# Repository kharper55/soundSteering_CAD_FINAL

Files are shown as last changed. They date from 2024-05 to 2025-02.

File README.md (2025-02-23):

All CAD pdfs and RAW files from KiCAD6 and some nice pin mapping references + block diagrams. Custom symbol and footprint library (not provided) needed to rebuild Gerbers (provided as-is). 

Contains schematic, PCB, BOM (entire KiCAD project + PDF prints) and Gerber files for 3x 4 layer mixed signal PCBs. KiCAD project has since seen edits in silkscreen and rectifying some issues with DNP parts.

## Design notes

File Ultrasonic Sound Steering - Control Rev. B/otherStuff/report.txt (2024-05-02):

Info: 
Info: Only selected footprints will be reannotated.
Info: Front footprints will start at 1
Info: Back footprints will start at 1.
Info: Prior to sorting by footprint location, the coordinates of which will be rounded to a 0.0100 mm, 0.0100 mm grid.
Info: 
Info: 
Info: Front Footprints
Info: *********** Sort on Footprint Coordinates ***********
Info: Sort Code 1
Info: 1 H4 UUID: [5ef39d40-b55b-4409-b36c-55ace9773fcc], X, Y: 270.2001 mm, 31.4900 mm, Rounded X, Y, 270.2000 mm, 31.4900 mm
Info: 2 H3 UUID: [7f6b7f0f-1088-4a6f-96c7-380cabd2f233], X, Y: 162.2002 mm, 31.4900 mm, Rounded X, Y, 162.2000 mm, 31.4900 mm
Info: 3 P1 UUID: [6f78a790-197d-4599-be1c-a15c64767265], X, Y: 260.8551 mm, 34.3800 mm, Rounded X, Y, 260.8600 mm, 34.3800 mm
Info: 4 P2 UUID: [7a461615-ffd7-4d30-9663-87001a941793], X, Y: 237.0701 mm, 34.3800 mm, Rounded X, Y, 237.0700 mm, 34.3800 mm
Info: 5 P3 UUID: [b7c12510-6d3f-4c6a-94f6-3d0dc28c4cde], X, Y: 213.2476 mm, 34.3800 mm, Rounded X, Y, 213.2500 mm, 34.3800 mm
Info: 6 P4 UUID: [4b9d0df7-170f-4f7f-a033-8b28d6827d94], X, Y: 189.3551 mm, 34.3800 mm, Rounded X, Y, 189.3600 mm, 34.3800 mm
Info: 7 R74 UUID: [192819fe-81a5-48ce-b989-7daec683b7d6], X, Y: 285.6400 mm, 38.6100 mm, Rounded X, Y, 285.6400 mm, 38.6100 mm
Info: 8 R75 UUID: [aceaaa9f-2b43-44a9-b572-54237d9b5ddd], X, Y: 284.1000 mm, 38.6100 mm, Rounded X, Y, 284.1000 mm, 38.6100 mm
Info: 9 C96 UUID: [d31a0397-f6ec-4a75-b0f9-c2d860a3d8c2], X, Y: 243.1000 mm, 41.3000 mm, Rounded X, Y, 243.1000 mm, 41.3000 mm
Info: 10 C94 UUID: [c2bd5aec-4e19-4a4d-851d-8b688b552ec4], X, Y: 241.6000 mm, 41.3000 mm, Rounded X, Y, 241.6000 mm, 41.3000 mm
Info: 11 C95 UUID: [f7d8199e-b9d8-48f1-bcea-ccafea0f0110], X, Y: 224.1000 mm, 41.5000 mm, Rounded X, Y, 224.1000 mm, 41.5000 mm
Info: 12 C93 UUID: [2ff3868e-4557-4a7c-8d10-9de1767db7a0], X, Y: 222.6000 mm, 41.5000 mm, Rounded X, Y, 222.6000 mm, 41.5000 mm
Info: 13 C104 UUID: [77131fb7-b846-4782-86b5-000abba21fb8], X, Y: 213.1000 mm, 41.5000 mm, Rounded X, Y, 213.1000 mm, 41.5000 mm
Info: 14 C102 UUID: [9f405f32-2f64-4263-b93f-015da219d625], X, Y: 211.6000 mm, 41.5000 mm, Rounded X, Y, 211.6000 mm, 41.5000 mm
Info: 15 C106 UUID: [21935355-0ea7-4418-bf57-3f39151b43f0], X, Y: 194.6000 mm, 41.5000 mm, Rounded X, Y, 194.6000 mm, 41.5000 mm
Info: 16 C108 UUID: [5b7d43c3-fe25-4339-ba2b-cab150709af7], X, Y: 193.0000 mm, 41.5000 mm, Rounded X, Y, 193.0000 mm, 41.5000 mm
Info: 17 D7 UUID: [b641bdf0-49eb-4e1c-94cb-5314bfd786c3], X, Y: 171.2000 mm, 43.1000 mm, Rounded X, Y, 171.2000 mm, 43.1000 mm
Info: 18 D6 UUID: [15c5f8f7-2afb-450d-b21e-f225e625be45], X, Y: 167.8000 mm, 43.1000 mm, Rounded X, Y, 167.8000 mm, 43.1000 mm
Info: 19 D8 UUID: [ad3ab07d-9057-4924-bd8b-8088b57ed8a1], X, Y: 164.4000 mm, 43.1000 mm, Rounded X, Y, 164.4000 mm, 43.1000 mm
Info: 20 R2 UUID: [6c8bd184-798c-4f7b-a843-9cd77462ab86], X, Y: 285.1250 mm, 43.3700 mm, Rounded X, Y, 285.1200 mm, 43.3700 mm
Info: 21 R1 UUID: [0578c37e-47f8-452a-a67a-b190503e62a1], X, Y: 285.1300 mm, 44.9400 mm, Rounded X, Y, 285.1300 mm, 44.9400 mm
Info: 22 C6 UUID: [90d4da69-4018-498f-bb6b-4cfebdb4cb5a], X, Y: 256.9948 mm, 45.9200 mm, Rounded X, Y, 256.9900 mm, 45.9200 mm
Info: 23 R5 UUID: [0b83f195-4963-4ca1-a54c-d24446b93c1d], X, Y: 255.4698 mm, 45.9200 mm, Rounded X, Y, 255.4700 mm, 45.9200 mm
Info: 24 R6 UUID: [a8cb8963-6a5a-49e4-a7a4-19c73d057da1], X, Y: 248.5198 mm, 45.9767 mm, Rounded X, Y, 248.5200 mm, 45.9800 mm
Info: 25 C4 UUID: [b4efda08-249d-4e6f-88e2-4c848a29d86f], X, Y: 246.9948 mm, 46.0017 mm, Rounded X, Y, 246.9900 mm, 46.0000 mm
Info: 26 U2 UUID: [b464a15f-49cd-483f-929b-b1d63c0dfe61], X, Y: 252.9200 mm, 47.6602 mm, Rounded X, Y, 252.9200 mm, 47.6600 mm
Info: 27 G*** UUID: [f62f571e-809b-4679-b4e9-53366150a207], X, Y: 171.0000 mm, 48.1000 mm, Rounded X, Y, 171.0000 mm, 48.1000 mm
Info: 28 G*** UUID: [f1c5bfbf-437b-4444-ade4-cd4697dfba52], X, Y: 164.1000 mm, 48.1000 mm, Rounded X, Y, 164.1000 mm, 48.1000 mm
Info: 29 R8 UUID: [c76515d9-e052-481d-a8d4-7fa5a038c2eb], X, Y: 256.9948 mm, 49.0200 mm, Rounded X, Y, 256.9900 mm, 49.0200 mm
Info: 30 R7 UUID: [2f5d750f-5572-471e-ad27-fa2c6e839281], X, Y: 246.9948 mm, 49.1017 mm, Rounded X, Y, 246.9900 mm, 49.1000 mm
Info: 31 R12 UUID: [ef9dd0d9-21e3-49e7-af84-aa2227a2675a], X, Y: 253.7200 mm, 51.2950 mm, Rounded X, Y, 253.7200 mm, 51.2900 mm
Info: 32 R15 UUID: [7903577e-90f3-4db0-83ab-298ddfa54431], X, Y: 252.1200 mm, 51.3200 mm, Rounded X, Y, 252.1200 mm, 51.3200 mm
Info: 33 R20 UUID: [e50c0e15-2a00-42e9-969f-a33d5defc610], X, Y: 255.9700 mm, 52.0450 mm, Rounded X, Y, 255.9700 mm, 52.0400 mm
Info: 34 R21 UUID: [9a23b505-a1c1-4c55-8e94-07d0a04f6fc8], X, Y: 249.8700 mm, 52.0700 mm, Rounded X, Y, 249.8700 mm, 52.0700 mm
Info: 35 C30 UUID: [ee7c2646-8918-4316-a13c-a55547939d0d], X, Y: 256.7200 mm, 54.3200 mm, Rounded X, Y, 256.7200 mm, 54.3200 mm
Info: 36 R23 UUID: [0a22617f-48e2-405b-8c59-09456fa25df2], X, Y: 255.2200 mm, 54.3200 mm, Rounded X, Y, 255.2200 mm, 54.3200 mm
Info: 37 C25 UUID: [2add6fbd-b38e-45b6-a212-125797d8d517], X, Y: 253.7200 mm, 54.3200 mm, Rounded X, Y, 253.7200 mm, 54.3200 mm
Info: 38 C26 UUID: [f990f52e-1060-43c0-97b5-9bdc75fcd620], X, Y: 252.1200 mm, 54.3450 mm, Rounded X, Y, 252.1200 mm, 54.3400 mm
Info: 39 R22 UUID: [0b8f20a1-43ed-46d2-8b26-702ba0309f43], X, Y: 250.6200 mm, 54.3450 mm, Rounded X, Y, 250.6200 mm, 54.3400 mm
Info: 40 C31 UUID: [b8513cf6-7d74-49e5-a1db-c65cbb1ba585], X, Y: 249.1200 mm, 54.3450 mm, Rounded X, Y, 249.1200 mm, 54.3400 mm
Info: 41 R31 UUID: [a8602b57-4e29-4aee-9e20-8a3468aa8102], X, Y: 248.9902 mm, 57.5333 mm, Rounded X, Y, 248.9900 mm, 57.5300 mm
Info: 42 C43 UUID: [42c4c59c-cc5c-4fd7-a70a-157ab00b49dd], X, Y: 247.4902 mm, 57.5383 mm, Rounded X, Y, 247.4900 mm, 57.5400 mm
Info: 43 U4 UUID: [9b29cd54-7d87-4a06-95ed-141c28052086], X, Y: 252.9200 mm, 59.1200 mm, Rounded X, Y, 252.9200 mm, 59.1200 mm
Info: 44 R30 UUID: [542dc883-e43e-472f-abc6-3a26a651cfff], X, Y: 248.9902 mm, 60.7133 mm, Rounded X, Y, 248.9900 mm, 60.7100 mm
Info: 45 C42 UUID: [e14837a6-e638-4080-99ac-983030d82948], X, Y: 247.4802 mm, 60.7183 mm, Rounded X, Y, 247.4800 mm, 60.7200 mm
Info: 46 C13 UUID: [5c6f666c-9dd8-4829-8e80-5befac30e1d8], X, Y: 266.1745 mm, 63.2595 mm, Rounded X, Y, 266.1700 mm, 63.2600 mm
Info: 47 C2 UUID: [32d9b593-6e00-4ffd-a08a-8f7fab912e91], X, Y: 264.6745 mm, 63.2595 mm, Rounded X, Y, 264.6700 mm, 63.2600 mm
Info: 48 R4 UUID: [335eb178-9181-4ef2-a296-3c4829b20506], X, Y: 263.1745 mm, 63.2595 mm, Rounded X, Y, 263.1700 mm, 63.2600 mm
Info: 49 C52 UUID: [90c07117-21cb-4709-aafc-49395e5940fc], X, Y: 250.6200 mm, 63.8950 mm, Rounded X, Y, 250.6200 mm, 63.8900 mm
Info: 50 C53 UUID: [f0b0f0b8-d6ab-47f5-b3d7-a419942acf09], X, Y: 255.1200 mm, 63.9200 mm, Rounded X, Y, 255.1200 mm, 63.9200 mm
Info: 51 R35 UUID: [96bb19ba-ff89-4c77-a440-9e0a11db0f5c], X, Y: 253.6200 mm, 63.9200 mm, Rounded X, Y, 253.6200 mm, 63.9200 mm
Info: 52 R34 UUID: [92833a25-9b29-40f2-9ff9-85f116f08a3f], X, Y: 252.1200 mm, 63.9200 mm, Rounded X, Y, 252.1200 mm, 63.9200 mm
Info: 53 R3 UUID: [eb0800e6-e528-4757-9302-dcfdf8abad5f], X, Y: 261.0995 mm, 65.1095 mm, Rounded X, Y, 261.1000 mm, 65.1100 mm
Info: 54 C49 UUID: [4f0d0ace-e127-46ac-950d-6772649d938a], X, Y: 252.8700 mm, 66.1400 mm, Rounded X, Y, 252.8700 mm, 66.1400 mm
Info: 55 C1 UUID: [0938bcb7-e6c9-4788-b5e6-9acbacb9b62b], X, Y: 261.0995 mm, 66.6095 mm, Rounded X, Y, 261.1000 mm, 66.6100 mm
Info: 56 U1 UUID: [93391fc0-2245-4688-ae4c-8d46a3492553], X, Y: 265.2445 mm, 67.3595 mm, Rounded X, Y, 265.2400 mm, 67.3600 mm
Info: 57 R28 UUID: [82640fbd-3c73-4450-a22e-da4ba30d7b63], X, Y: 258.1450 mm, 67.8500 mm, Rounded X, Y, 258.1400 mm, 67.8500 mm
Info: 58 R29 UUID: [e7bf863f-b7ab-4ead-b51e-bc27fb58766e], X, Y: 255.1700 mm, 67.8500 mm, Rounded X, Y, 255.1700 mm, 67.8500 mm
Info: 59 R65 UUID: [75d41bf9-6a28-4542-b1f4-cd0ecc474c5b], X, Y: 174.7400 mm, 69.1100 mm, Rounded X, Y, 174.7400 mm, 69.1100 mm
Info: 60 R66 UUID: [11961651-8c18-44a2-9be0-223b05e9f2bd], X, Y: 171.6600 mm, 69.1100 mm, Rounded X, Y, 171.6600 mm, 69.1100 mm
Info: 61 R67 UUID: [c720f2e8-cac0-49f0-894e-f5031baecdde], X, Y: 168.6100 mm, 69.1100 mm, Rounded X, Y, 168.6100 mm, 69.1100 mm
Info: 62 C40 UUID: [958d8925-0e3f-4da3-a6b1-bfae443f6cfd], X, Y: 258.1450 mm, 69.3500 mm, Rounded X, Y, 258.1400 mm, 69.3500 mm
Info: 63 C41 UUID: [71bd50be-7db5-4780-bbec-b6e8ed043e99], X, Y: 255.1700 mm, 69.3500 mm, Rounded X, Y, 255.1700 mm, 69.3500 mm
Info: 64 R64 UUID: [2fd27f65-5d80-4188-b2bf-acc531168e70], X, Y: 174.7400 mm, 70.6600 mm, Rounded X, Y, 174.7400 mm, 70.6600 mm
Info: 65 C51 UUID: [8e789659-96b5-4a8d-93cb-7298e7069d96], X, Y: 251.8772 mm, 71.0578 mm, Rounded X, Y, 251.8800 mm, 71.0600 mm
Info: 66 C18 UUID: [9996c1e2-bf8a-4331-acff-6dbfe163533c], X, Y: 266.6445 mm, 71.8678 mm, Rounded X, Y, 266.6400 mm, 71.8700 mm
Info: 67 C17 UUID: [0a662090-924a-41f9-9c84-ecfee2765f3e], X, Y: 265.0445 mm, 71.8678 mm, Rounded X, Y, 265.0400 mm, 71.8700 mm
Info: 68 C28 UUID: [28542c89-831f-46a2-9572-15f587ab3dd8], X, Y: 260.5450 mm, 71.8900 mm, Rounded X, Y, 260.5400 mm, 71.8900 mm
Info: 69 Q3 UUID: [d3c47d26-7908-49cc-ab0e-07a830d9cec5], X, Y: 178.5000 mm, 72.0500 mm, Rounded X, Y, 178.5000 mm, 72.0500 mm
Info: 70 R33 UUID: [9946b09b-2d8e-41c4-9b8b-ed51b1f0b4bf], X, Y: 251.8772 mm, 72.5578 mm, Rounded X, Y, 251.8800 mm, 72.5600 mm
Info: 71 R70 UUID: [7aacb1dd-9b5b-400c-b776-7248739c89ff], X, Y: 175.5100 mm, 72.9800 mm, Rounded X, Y, 175.5100 mm, 72.9800 mm
Info: 72 R71 UUID: [8ef63d0b-c40a-4028-9155-7be2f9ffa36c], X, Y: 183.0100 mm, 72.9900 mm, Rounded X, Y, 183.0100 mm, 72.9900 mm
Info: 73 C129 UUID: [42e22537-8a59-4884-bd3a-296ff192f30d], X, Y: 181.4800 mm, 73.0000 mm, Rounded X, Y, 181.4800 mm, 73.0000 mm
Info: 74 R37 UUID: [cb7e0a10-8b63-4d06-a672-9a51c28baffb], X, Y: 240.6750 mm, 73.2543 mm, Rounded X, Y, 240.6700 mm, 73.2500 mm
Info: 75 C48 UUID: [37e90919-1fd3-4491-a9f2-abbb7c6a93ce], X, Y: 249.6772 mm, 73.3578 mm, Rounded X, Y, 249.6800 mm, 73.3600 mm
Info: 76 U3 UUID: [83b39ec6-0a03-45f8-aae0-940e61a7cd70], X, Y: 256.5929 mm, 73.4056 mm, Rounded X, Y, 256.5900 mm, 73.4100 mm
Info: 77 U5 UUID: [bf2f306b-7e48-4394-9dde-f34ee5ca8ec2], X, Y: 244.7600 mm, 73.9632 mm, Rounded X, Y, 244.7600 mm, 73.9600 mm
Info: 78 R32 UUID: [bb950574-61bb-4618-8728-ac44e25a7a25], X, Y: 251.8772 mm, 74.2578 mm, Rounded X, Y, 251.8800 mm, 74.2600 mm
Info: 79 U24 UUID: [46db3e31-f72d-4b19-8aa0-55fdef644baa], X, Y: 170.2400 mm, 74.3900 mm, Rounded X, Y, 170.2400 mm, 74.3900 mm
Info: 80 R38 UUID: [45e4f1da-2cd8-4e6f-aa8f-689a94f70921], X, Y: 240.6750 mm, 74.8043 mm, Rounded X, Y, 240.6700 mm, 74.8000 mm
Info: 81 R18 UUID: [2d249090-11f4-449d-862f-8733c097b5af], X, Y: 268.0900 mm, 74.8800 mm, Rounded X, Y, 268.0900 mm, 74.8800 mm
Info: 82 R17 UUID: [52124a33-5324-45fa-b076-c4332c089c58], X, Y: 266.5900 mm, 74.8800 mm, Rounded X, Y, 266.5900 mm, 74.8800 mm
Info: 83 R16 UUID: [4ee4ae8b-61c7-460c-873f-ed49651743e8], X, Y: 265.0900 mm, 74.8800 mm, Rounded X, Y, 265.0900 mm, 74.8800 mm
Info: 84 R19 UUID: [48259941-b1fb-4747-bfc0-4331eaabce95], X, Y: 263.5900 mm, 74.8800 mm, Rounded X, Y, 263.5900 mm, 74.8800 mm
Info: 85 C29 UUID: [c9b8090c-a012-4831-a62a-59edb3a90baf], X, Y: 260.5450 mm, 74.8900 mm, Rounded X, Y, 260.5400 mm, 74.8900 mm
Info: 86 R61 UUID: [97c48f85-5a6d-4bef-8746-bcdebd06ca61], X, Y: 197.1100 mm, 75.2500 mm, Rounded X, Y, 197.1100 mm, 75.2500 mm
Info: 87 C50 UUID: [9a103e91-c496-430d-9146-89abff106f87], X, Y: 251.8772 mm, 75.7578 mm, Rounded X, Y, 251.8800 mm, 75.7600 mm
Info: 88 Q4 UUID: [92dae593-27cc-438d-a171-3260aeebd602], X, Y: 178.4900 mm, 75.9200 mm, Rounded X, Y, 178.4900 mm, 75.9200 mm
Info: 89 R69 UUID: [fbef717e-a140-4706-a0a6-c307fe2c19e4], X, Y: 175.5000 mm, 76.0200 mm, Rounded X, Y, 175.5000 mm, 76.0200 mm
Info: 90 R72 UUID: [c3b5ef56-74ef-43ec-b9f8-07e69d639ad9], X, Y: 183.0100 mm, 76.0350 mm, Rounded X, Y, 183.0100 mm, 76.0300 mm
Info: 91 C128 UUID: [b37c6c1a-abc1-4336-984f-1696003b4358], X, Y: 181.4800 mm, 76.0300 mm, Rounded X, Y, 181.4800 mm, 76.0300 mm
Info: 92 U13 UUID: [78d52183-fc9f-473d-af48-32cb8a86e314], X, Y: 216.5000 mm, 76.5000 mm, Rounded X, Y, 216.5000 mm, 76.5000 mm
Info: 93 FB1 UUID: [13478164-44d8-4b70-9a3b-18f200deddfc], X, Y: 270.0850 mm, 78.5550 mm, Rounded X, Y, 270.0800 mm, 78.5500 mm
Info: 94 R53 UUID: [9d9169e7-d932-4355-8a5e-b13cc3a2fc9a], X, Y: 165.2800 mm, 80.8300 mm, Rounded X, Y, 165.2800 mm, 80.8300 mm
Info: 95 R52 UUID: [9be3b8fe-2aed-47e1-bf97-ad717698cc02], X, Y: 161.4700 mm, 80.8400 mm, Rounded X, Y, 161.4700 mm, 80.8400 mm
Info: 96 U9 UUID: [1e35901f-e7f0-47bc-aea6-8bbf3533fe51], X, Y: 270.0900 mm, 82.6500 mm, Rounded X, Y, 270.0900 mm, 82.6500 mm
Info: 97 U11 UUID: [81382938-a484-404e-ae45-0197ce3f233a], X, Y: 261.4800 mm, 82.7250 mm, Rounded X, Y, 261.4800 mm, 82.7200 mm
Info: 98 R42 UUID: [16936265-9da4-432d-a361-22a87bc4a26f], X, Y: 257.4100 mm, 85.3750 mm, Rounded X, Y, 257.4100 mm, 85.3700 mm
Info: 99 C73 UUID: [1ad55954-5086-4ae6-acf2-05f4ff0708cd], X, Y: 270.3350 mm, 86.6250 mm, Rounded X, Y, 270.3300 mm, 86.6200 mm
Info: 100 U12 UUID: [c8756d37-f96f-4413-a974-4dbac44a0e0c], X, Y: 261.4550 mm, 87.2400 mm, Rounded X, Y, 261.4500 mm, 87.2400 mm
Info: 101 U10 UUID: [ebbc979d-a82a-471c-b7ac-e64b771ab7d5], X, Y: 265.4700 mm, 87.2697 mm, Rounded X, Y, 265.4700 mm, 87.2700 mm
Info: 102 C63 UUID: [caec2e82-d955-4b57-b3b9-4b6088cd5e3d], X, Y: 250.9250 mm, 87.5800 mm, Rounded X, Y, 250.9200 mm, 87.5800 mm
Info: 103 C65 UUID: [8d6a3f03-ec70-4c74-8934-5b1887b0c26a], X, Y: 249.4250 mm, 87.5800 mm, Rounded X, Y, 249.4200 mm, 87.5800 mm
Info: 104 C71 UUID: [55d8539e-39e3-440e-aa96-8af5bcd2eee1], X, Y: 258.1650 mm, 87.5900 mm, Rounded X, Y, 258.1600 mm, 87.5900 mm
Info: 105 R41 UUID: [46e0d02b-21e0-4f5f-8bb2-290863801475], X, Y: 256.6400 mm, 87.5900 mm, Rounded X, Y, 256.6400 mm, 87.5900 mm
Info: 106 U6 UUID: [0e20234a-d07f-4b02-bfb0-6ca2c38105cb], X, Y: 253.9500 mm, 87.5900 mm, Rounded X, Y, 253.9500 mm, 87.5900 mm
Info: 107 C61 UUID: [a19f97a2-0a39-482e-9340-8934eb3161fc], X, Y: 247.8250 mm, 87.6300 mm, Rounded X, Y, 247.8200 mm, 87.6300 mm
Info: 108 R73 UUID: [34f28257-075d-435a-96ca-7744eb05a464], X, Y: 181.3600 mm, 88.2100 mm, Rounded X, Y, 181.3600 mm, 88.2100 mm
Info: 109 U23 UUID: [8e489fcd-25ef-4282-b196-fb724bde004c], X, Y: 164.1900 mm, 92.6300 mm, Rounded X, Y, 164.1900 mm, 92.6300 mm
Info: 110 R60 UUID: [9c9165ac-716c-46cf-b69d-ea14b7bfe4bd], X, Y: 181.3900 mm, 97.0800 mm, Rounded X, Y, 181.3900 mm, 97.0800 mm
Info: 111 C112 UUID: [b3a4c3e6-681c-43ad-9343-5eb646d4f70f], X, Y: 258.7750 mm, 97.8500 mm, Rounded X, Y, 258.7700 mm, 97.8500 mm
Info: 112 C111 UUID: [10518b7c-2576-4335-ac7a-e38c726bca78], X, Y: 256.9750 mm, 97.8500 mm, Rounded X, Y, 256.9700 mm, 97.8500 mm
Info: 113 C78 UUID: [fc19c4f7-798f-46df-b8b4-fb10653c19a8], X, Y: 255.3750 mm, 97.8500 mm, Rounded X, Y, 255.3700 mm, 97.8500 mm
Info: 114 C83 UUID: [871747f9-d1f0-4f8a-8771-37d32db82351], X, Y: 252.5750 mm, 97.8500 mm, Rounded X, Y, 252.5700 mm, 97.8500 mm
Info: 115 C113 UUID: [4e6f3825-9341-4cd0-9ea1-c2c481507c6b], X, Y: 250.7400 mm, 97.8800 mm, Rounded X, Y, 250.7400 mm, 97.8800 mm
Info: 116 C114 UUID: [731aa020-86a5-4998-b1e5-55071e2cfa29], X, Y: 249.1300 mm, 97.8900 mm, Rounded X, Y, 249.1300 mm, 97.8900 mm
Info: 117 C75 UUID: [bf49afb2-9e6b-4a9b-b75c-195b8a5a194a], X, Y: 258.7500 mm, 101.7000 mm, Rounded X, Y, 258.7500 mm, 101.7000 mm
Info: 118 C68 UUID: [bd7604c5-87b8-4bd9-9e37-649c4b42cdae], X, Y: 246.0750 mm, 102.5250 mm, Rounded X, Y, 246.0700 mm, 102.5200 mm
Info: 119 R45 UUID: [2d77b8ea-03f8-43d2-b213-4da4a284dabd], X, Y: 258.7750 mm, 105.2750 mm, Rounded X, Y, 258.7700 mm, 105.2700 mm
Info: 120 D3 UUID: [a303aa19-a577-4ba5-9a36-66e085dc6db1], X, Y: 248.8000 mm, 105.3250 mm, Rounded X, Y, 248.8000 mm, 105.3200 mm
Info: 121 C76 UUID: [197e5499-bc56-4f90-8c4c-8d2aa56a1aa0], X, Y: 160.1825 mm, 105.3450 mm, Rounded X, Y, 160.1800 mm, 105.3400 mm
Info: 122 C127 UUID: [8bc0ea16-b07c-4e84-a974-b827d275f5a0], X, Y: 167.8500 mm, 105.3500 mm, Rounded X, Y, 167.8500 mm, 105.3500 mm
Info: 123 R68 UUID: [e3e1f600-a238-4847-b7c3-b379d7babea4], X, Y: 166.3100 mm, 105.3500 mm, Rounded X, Y, 166.3100 mm, 105.3500 mm
Info: 124 C124 UUID: [ea8b2af2-85c3-459f-a29f-9c21bd1553b7], X, Y: 164.7700 mm, 105.3500 mm, Rounded X, Y, 164.7700 mm, 105.3500 mm
Info: 125 C123 UUID: [a40b12bd-43c8-462e-9491-b7479b20666d], X, Y: 163.2400 mm, 105.3500 mm, Rounded X, Y, 163.2400 mm, 105.3500 mm
Info: 126 C126 UUID: [034b6d13-24cd-4c7b-893b-aff3f8314eec], X, Y: 161.7125 mm, 105.3550 mm, Rounded X, Y, 161.7100 mm, 105.3500 mm
Info: 127 R62 UUID: [882d58ad-dfac-4c09-8126-2d39727f4f25], X, Y: 174.1600 mm, 105.3800 mm, Rounded X, Y, 174.1600 mm, 105.3800 mm
Info: 128 R44 UUID: [898fec02-e9f0-4f68-86df-85569242df45], X, Y: 246.0750 mm, 106.6250 mm, Rounded X, Y, 246.0700 mm, 106.6200 mm
Info: 129 U8 UUID: [b50be23b-ce1c-4528-8206-bf645533c790], X, Y: 253.9750 mm, 106.8500 mm, Rounded X, Y, 253.9700 mm, 106.8500 mm
Info: 130 R46 UUID: [a9e2d506-51b2-477d-b263-0ea3a860e4c6], X, Y: 268.6000 mm, 106.9250 mm, Rounded X, Y, 268.6000 mm, 106.9200 mm
Info: 131 R43 UUID: [10ff95ff-472d-4d51-9562-3d4d318a9c29], X, Y: 246.0750 mm, 108.1250 mm, Rounded X, Y, 246.0700 mm, 108.1200 mm
Info: 132 D1 UUID: [24954364-08ca-480b-a17f-cef42a647d11], X, Y: 263.8500 mm, 109.2250 mm, Rounded X, Y, 263.8500 mm, 109.2200 mm
Info: 133 C70 UUID: [5b89adf9-9731-4f8a-b8c1-e82e57f2cb4a], X, Y: 246.0750 mm, 109.6250 mm, Rounded X, Y, 246.0700 mm, 109.6200 mm
Info: 134 S1 UUID: [48bfdc01-b0cd-4f5b-bb75-2b3ad4a6ff9f], X, Y: 271.9100 mm, 110.5800 mm, Rounded X, Y, 271.9100 mm, 110.5800 mm
Info: 135 C99 UUID: [6bac4868-49c8-4e96-84cf-d7d4421e10a0], X, Y: 220.9500 mm, 111.4750 mm, Rounded X, Y, 220.9500 mm, 111.4700 mm
Info: 136 C97 UUID: [3f7c91bb-b0a0-416f-ac44-126083cffde2], X, Y: 219.4500 mm, 111.4750 mm, Rounded X, Y, 219.4500 mm, 111.4700 mm
Info: 137 C100 UUID: [006fd919-1196-470f-a248-f93a156f42f7], X, Y: 239.4000 mm, 111.5000 mm, Rounded X, Y, 239.4000 mm, 111.5000 mm
Info: 138 C98 UUID: [5f0202a2-1de2-4919-9405-f4d2a479cf56], X, Y: 237.9100 mm, 111.5000 mm, Rounded X, Y, 237.9100 mm, 111.5000 mm
Info: 139 C107 UUID: [456aeb2b-6826-4420-b620-80c6dc9e071b], X, Y: 190.4000 mm, 111.5000 mm, Rounded X, Y, 190.4000 mm, 111.5000 mm
Info: 140 C105 UUID: [479b4504-5605-4082-919a-baca47d55419], X, Y: 188.9000 mm, 111.5000 mm, Rounded X, Y, 188.9000 mm, 111.5000 mm
Info: 141 C101 UUID: [66ae25e1-8f78-438d-aa96-ca55ba5a4ab3], X, Y: 209.3000 mm, 111.5250 mm, Rounded X, Y, 209.3000 mm, 111.5200 mm
Info: 142 C103 UUID: [8c1789b1-5d02-4b6f-aa73-a8487ba46dee], X, Y: 207.8200 mm, 111.5250 mm, Rounded X, Y, 207.8200 mm, 111.5200 mm
Info: 143 P5 UUID: [0210975c-d641-4efc-aed9-abd36f5b2ca2], X, Y: 243.0751 mm, 118.7000 mm, Rounded X, Y, 243.0800 mm, 118.7000 mm
Info: 144 P6 UUID: [83e8e0fb-2eed-4111-9b7a-27ebbdb49fb5], X, Y: 219.2901 mm, 118.7000 mm, Rounded X, Y, 219.2900 mm, 118.7000 mm
Info: 145 P7 UUID: [65d166da-6e54-4899-bf21-78b437ce2ab8], X, Y: 195.4676 mm, 118.7000 mm, Rounded X, Y, 195.4700 mm, 118.7000 mm
Info: 146 P8 UUID: [95e88e77-ee7d-4a55-b131-b751971338ed], X, Y: 171.5751 mm, 118.7000 mm, Rounded X, Y, 171.5800 mm, 118.7000 mm
Info: 147 H2 UUID: [fe5f3cf4-30f5-4ecf-a7da-43bdebe2cf47], X, Y: 270.2002 mm, 121.6400 mm, Rounded X, Y, 270.2000 mm, 121.6400 mm
Info: 148 H1 UUID: [395c3b9a-2c81-4f50-bfcd-a053be469ada], X, Y: 162.2002 mm, 121.6400 mm, Rounded X, Y, 162.2000 mm, 121.6400 mm
Info: 
Info: 
Info: Back Footprints
Info: *********** Sort on Footprint Coordinates ***********
Info: Sort Code 1
Info: 1 Q2 UUID: [7229c1f7-ce77-4976-8be7-27a657ec73d2], X, Y: 163.1592 mm, 41.5988 mm, Rounded X, Y, 163.1600 mm, 41.6000 mm
Info: 2 Q1 UUID: [30fecc18-0e4a-4a8b-b8b0-44c7c2196f7b], X, Y: 170.0945 mm, 41.6000 mm, Rounded X, Y, 170.0900 mm, 41.6000 mm
Info: 3 U22 UUID: [050e1bcb-3371-4602-b469-575177afa360], X, Y: 192.0000 mm, 41.6000 mm, Rounded X, Y, 192.0000 mm, 41.6000 mm
Info: 4 U20 UUID: [c18eab44-b32e-4646-aba6-319c7960505b], X, Y: 210.5000 mm, 41.7000 mm, Rounded X, Y, 210.5000 mm, 41.7000 mm
Info: 5 U18 UUID: [cd526938-1c37-4fa0-a92d-cff8ee4bd1f4], X, Y: 221.5000 mm, 41.7000 mm, Rounded X, Y, 221.5000 mm, 41.7000 mm
Info: 6 U16 UUID: [89f3bab7-ff7c-4c47-a530-197c66f36b2d], X, Y: 240.5000 mm, 41.7000 mm, Rounded X, Y, 240.5000 mm, 41.7000 mm
Info: 7 C110 UUID: [03e42c5d-8b0c-4085-a1e8-a37b52982fbc], X, Y: 249.8148 mm, 43.6967 mm, Rounded X, Y, 249.8100 mm, 43.7000 mm
Info: 8 C15 UUID: [ab44f634-ee67-4827-abd4-6fd7dd2e327f], X, Y: 252.8948 mm, 43.6967 mm, Rounded X, Y, 252.8900 mm, 43.7000 mm
Info: 9 P12 UUID: [be7cb87d-abfc-4a7d-8c35-12d8b56fcde4], X, Y: 270.1900 mm, 44.3400 mm, Rounded X, Y, 270.1900 mm, 44.3400 mm
Info: 10 R57 UUID: [b0ca33c9-4d0c-4b03-88eb-a8d18a79b7de], X, Y: 161.8000 mm, 45.0000 mm, Rounded X, Y, 161.8000 mm, 45.0000 mm
Info: 11 R58 UUID: [9980ec04-e9a0-43dc-a3f1-5f8bc796ad5b], X, Y: 163.4000 mm, 45.0000 mm, Rounded X, Y, 163.4000 mm, 45.0000 mm
Info: 12 R59 UUID: [17009834-6e4e-4fd2-8ac3-a243e8945980], X, Y: 165.0000 mm, 45.0000 mm, Rounded X, Y, 165.0000 mm, 45.0000 mm
Info: 13 R49 UUID: [c1f2104a-f60c-4faa-9ee3-e336583210a3], X, Y: 166.8500 mm, 45.0000 mm, Rounded X, Y, 166.8500 mm, 45.0000 mm
Info: 14 R54 UUID: [a57788f3-d21e-43ec-96a4-4db259bb954d], X, Y: 168.7000 mm, 45.0000 mm, Rounded X, Y, 168.7000 mm, 45.0000 mm
Info: 15 R55 UUID: [e5a074a7-ff93-4fde-b2c1-47d7de951c20], X, Y: 170.3000 mm, 45.0000 mm, Rounded X, Y, 170.3000 mm, 45.0000 mm
Info: 16 R56 UUID: [59bd1d4b-a234-43d7-91a4-3c8593a3bf5e], X, Y: 171.9000 mm, 45.0000 mm, Rounded X, Y, 171.9000 mm, 45.0000 mm
Info: 17 C109 UUID: [7dfd4a95-0f0c-4c6b-b96e-75361dc62b3c], X, Y: 249.8148 mm, 45.2367 mm, Rounded X, Y, 249.8100 mm, 45.2400 mm
Info: 18 C11 UUID: [049301c4-836c-42b1-a93c-28aae55408d5], X, Y: 252.9048 mm, 45.2367 mm, Rounded X, Y, 252.9000 mm, 45.2400 mm
Info: 19 R9 UUID: [ddc9600e-c189-4ae7-a3a6-1a827ed62c65], X, Y: 252.9200 mm, 47.5603 mm, Rounded X, Y, 252.9200 mm, 47.5600 mm
Info: 20 C16 UUID: [f8b4dc17-7e6f-447d-8bdd-6c8de11b4e98], X, Y: 252.9200 mm, 49.0603 mm, Rounded X, Y, 252.9200 mm, 49.0600 mm
Info: 21 C20 UUID: [3903a7de-2080-4916-aaae-f6130c5d3cb4], X, Y: 252.9200 mm, 50.5950 mm, Rounded X, Y, 252.9200 mm, 50.5900 mm
Info: 22 C19 UUID: [39bd9ff3-0c14-4750-8a58-22cb13cea02b], X, Y: 252.9200 mm, 52.0950 mm, Rounded X, Y, 252.9200 mm, 52.0900 mm
Info: 23 C121 UUID: [5cff931d-c10b-49a5-bdc4-9d14b1c160c6], X, Y: 254.4298 mm, 55.3267 mm, Rounded X, Y, 254.4300 mm, 55.3300 mm
Info: 24 C22 UUID: [ee9cbc31-a358-4ecc-bc3d-8e179228e60d], X, Y: 251.3898 mm, 55.3367 mm, Rounded X, Y, 251.3900 mm, 55.3400 mm
Info: 25 C10 UUID: [f73535b3-97a4-4a32-a960-648bbaab0a5c], X, Y: 251.3898 mm, 56.8367 mm, Rounded X, Y, 251.3900 mm, 56.8400 mm
Info: 26 C122 UUID: [46f3186b-9cb4-4ee4-aef3-fed529b61380], X, Y: 254.4298 mm, 56.8367 mm, Rounded X, Y, 254.4300 mm, 56.8400 mm
Info: 27 P10 UUID: [ec5d0170-2e7d-4ac1-9c32-53fadbc043c3], X, Y: 168.5600 mm, 57.0440 mm, Rounded X, Y, 168.5600 mm, 57.0400 mm
Info: 28 C45 UUID: [b858d4fc-1ae7-42f9-b7ac-881b2e757188], X, Y: 248.3198 mm, 58.3847 mm, Rounded X, Y, 248.3200 mm, 58.3800 mm
Info: 29 R26 UUID: [3a0f3436-5902-44bc-af79-bc7e4335f373], X, Y: 251.3902 mm, 58.3833 mm, Rounded X, Y, 251.3900 mm, 58.3800 mm
Info: 30 C37 UUID: [50fdd1d1-0b1b-47f2-bd51-fb5c8551a03d], X, Y: 254.4252 mm, 58.3833 mm, Rounded X, Y, 254.4300 mm, 58.3800 mm
Info: 31 C33 UUID: [a5aafbc4-6857-4b48-8cc9-4a6ab1bbc515], X, Y: 257.4848 mm, 58.3967 mm, Rounded X, Y, 257.4800 mm, 58.4000 mm
Info: 32 R27 UUID: [e2a9378b-ff6a-4a83-85d5-d0135d33860c], X, Y: 251.3952 mm, 59.8833 mm, Rounded X, Y, 251.4000 mm, 59.8800 mm
Info: 33 C38 UUID: [54fb6744-6c33-4a2c-b97b-8eea48071cb5], X, Y: 254.4252 mm, 59.8833 mm, Rounded X, Y, 254.4300 mm, 59.8800 mm
Info: 34 C39 UUID: [bcd20e3b-b32f-4f3f-8683-84c74b424a31], X, Y: 257.4748 mm, 59.8867 mm, Rounded X, Y, 257.4700 mm, 59.8900 mm
Info: 35 C47 UUID: [31db70a3-321b-4b2d-9be7-cba2683b6363], X, Y: 248.3168 mm, 59.8967 mm, Rounded X, Y, 248.3200 mm, 59.9000 mm
Info: 36 P14 UUID: [050031de-379a-4826-b614-b1ad07b7f6ac], X, Y: 270.8900 mm, 60.1365 mm, Rounded X, Y, 270.8900 mm, 60.1400 mm
Info: 37 C14 UUID: [e2b7a84e-676c-4bba-944f-4f2f88f47a73], X, Y: 251.4048 mm, 61.4267 mm, Rounded X, Y, 251.4000 mm, 61.4300 mm
Info: 38 C120 UUID: [0a84a363-d903-4d0f-8b6f-94f535064747], X, Y: 254.4298 mm, 61.4267 mm, Rounded X, Y, 254.4300 mm, 61.4300 mm
Info: 39 C24 UUID: [5de24c5a-0d92-4307-b912-89667a998851], X, Y: 251.4048 mm, 62.9267 mm, Rounded X, Y, 251.4000 mm, 62.9300 mm
Info: 40 C119 UUID: [7fd84043-c517-481b-bdbf-37d6473c4a16], X, Y: 254.4298 mm, 62.9267 mm, Rounded X, Y, 254.4300 mm, 62.9300 mm
Info: 41 C3 UUID: [ed96ccc4-aab8-44f5-a1d3-3647cc28df2b], X, Y: 269.3945 mm, 66.8345 mm, Rounded X, Y, 269.3900 mm, 66.8300 mm
Info: 42 C7 UUID: [5496db35-6ef0-4639-a828-70c5c26991aa], X, Y: 264.6445 mm, 67.5595 mm, Rounded X, Y, 264.6400 mm, 67.5600 mm
Info: 43 C125 UUID: [989b15eb-2f2c-42ac-9b7c-a70612fe0c20], X, Y: 174.7400 mm, 68.2400 mm, Rounded X, Y, 174.7400 mm, 68.2400 mm
Info: 44 C5 UUID: [392aa572-63f2-4317-8b79-89485949724a], X, Y: 269.3945 mm, 68.3345 mm, Rounded X, Y, 269.3900 mm, 68.3300 mm
Info: 45 R63 UUID: [bc3c8697-07da-4b1b-ad16-618c560fa37a], X, Y: 164.7400 mm, 68.4100 mm, Rounded X, Y, 164.7400 mm, 68.4100 mm
Info: 46 C44 UUID: [55507068-597a-4c50-bc81-2b343b4ef596], X, Y: 255.8478 mm, 68.9222 mm, Rounded X, Y, 255.8500 mm, 68.9200 mm
Info: 47 C46 UUID: [f81f1620-d48f-402f-9ed9-161e797ba741], X, Y: 257.4078 mm, 68.9172 mm, Rounded X, Y, 257.4100 mm, 68.9200 mm
Info: 48 C9 UUID: [4cef2cbc-20a6-4f56-a97a-e50f88857f1b], X, Y: 264.6745 mm, 69.4678 mm, Rounded X, Y, 264.6700 mm, 69.4700 mm
Info: 49 C85 UUID: [8a1972e6-f9a8-44a3-9e4b-757b6644815c], X, Y: 174.7450 mm, 69.7800 mm, Rounded X, Y, 174.7400 mm, 69.7800 mm
Info: 50 P15 UUID: [5d4950f4-94a1-4ab0-b1e8-e2a42c64c274], X, Y: 160.4600 mm, 70.7400 mm, Rounded X, Y, 160.4600 mm, 70.7400 mm
Info: 51 D4 UUID: [1e6167bc-7806-4ced-a5f6-e99b2283d242], X, Y: 164.8600 mm, 70.9300 mm, Rounded X, Y, 164.8600 mm, 70.9300 mm
Info: 52 C54 UUID: [40ddb19d-527e-460f-8d1d-e7faa8b277a1], X, Y: 247.4350 mm, 70.9632 mm, Rounded X, Y, 247.4300 mm, 70.9600 mm
Info: 53 R24 UUID: [a2a2d179-1175-4308-97c7-fa03d9127053], X, Y: 257.4050 mm, 71.9450 mm, Rounded X, Y, 257.4000 mm, 71.9400 mm
Info: 54 C21 UUID: [48e97c7a-98fb-4b35-bf23-b7ea8c85fac9], X, Y: 258.9078 mm, 71.9422 mm, Rounded X, Y, 258.9100 mm, 71.9400 mm
Info: 55 C23 UUID: [afc90274-01fc-4028-8959-5f230f4849e8], X, Y: 260.4078 mm, 71.9372 mm, Rounded X, Y, 260.4100 mm, 71.9400 mm
Info: 56 C8 UUID: [0aa32a1a-9e2c-4456-bd4a-5561b9c2c8d2], X, Y: 252.7778 mm, 71.9472 mm, Rounded X, Y, 252.7800 mm, 71.9500 mm
Info: 57 C12 UUID: [2e30bc3b-cc4a-44d0-976b-0f64614a5a2e], X, Y: 254.2878 mm, 71.9472 mm, Rounded X, Y, 254.2900 mm, 71.9500 mm
Info: 58 R25 UUID: [c10bb1c8-a745-4d9e-94df-30c005a5e76b], X, Y: 255.8450 mm, 71.9500 mm, Rounded X, Y, 255.8400 mm, 71.9500 mm
Info: 59 C56 UUID: [6334eb73-f858-49e0-af73-47361ff9d93f], X, Y: 247.4250 mm, 72.4793 mm, Rounded X, Y, 247.4200 mm, 72.4800 mm
Info: 60 R11 UUID: [cbbe08ae-6596-485b-98a3-241e9911a242], X, Y: 264.2645 mm, 72.5595 mm, Rounded X, Y, 264.2600 mm, 72.5600 mm
Info: 61 R10 UUID: [54610e84-ea16-4391-9601-61ffbcf0932a], X, Y: 267.3745 mm, 72.5595 mm, Rounded X, Y, 267.3700 mm, 72.5600 mm
Info: 62 R13 UUID: [480c40d1-0b68-4f35-95b9-a10a108eb864], X, Y: 268.8695 mm, 74.0745 mm, Rounded X, Y, 268.8700 mm, 74.0700 mm
Info: 63 R14 UUID: [d6967e59-ac81-4c74-983a-85444f18308d], X, Y: 262.8045 mm, 74.0845 mm, Rounded X, Y, 262.8000 mm, 74.0800 mm
Info: 64 C27 UUID: [88129fd6-6252-4341-9a45-cdaa28cd6452], X, Y: 265.8372 mm, 74.0772 mm, Rounded X, Y, 265.8400 mm, 74.0800 mm
Info: 65 C58 UUID: [011c59c5-0c46-4eac-8687-1cafa03e01eb], X, Y: 247.4000 mm, 74.1043 mm, Rounded X, Y, 247.4000 mm, 74.1000 mm
Info: 66 C34 UUID: [35ff2996-b5d4-4622-9c88-75b7625d77bb], X, Y: 257.4050 mm, 74.9450 mm, Rounded X, Y, 257.4000 mm, 74.9400 mm
Info: 67 C118 UUID: [98c13ee8-4310-4a21-8db5-ff993a9f4ac1], X, Y: 252.7778 mm, 74.9472 mm, Rounded X, Y, 252.7800 mm, 74.9500 mm
Info: 68 C117 UUID: [a56c3097-6f1e-4290-85b5-70a21926c298], X, Y: 254.2878 mm, 74.9522 mm, Rounded X, Y, 254.2900 mm, 74.9500 mm
Info: 69 C35 UUID: [d4aa73aa-daa5-4297-91ba-12d88b780096], X, Y: 255.8450 mm, 74.9500 mm, Rounded X, Y, 255.8500 mm, 74.9500 mm
Info: 70 C116 UUID: [6579343a-d450-4ba5-8b44-6cb016f1ef98], X, Y: 258.9178 mm, 74.9522 mm, Rounded X, Y, 258.9200 mm, 74.9500 mm
Info: 71 C115 UUID: [f6b4802b-cd30-434d-941b-8088132ba7da], X, Y: 260.4078 mm, 74.9572 mm, Rounded X, Y, 260.4100 mm, 74.9600 mm
Info: 72 C59 UUID: [d16b239e-8706-46a0-9ecf-f607e7faf56c], X, Y: 242.0500 mm, 75.6543 mm, Rounded X, Y, 242.0500 mm, 75.6500 mm
Info: 73 C57 UUID: [30db28b3-50af-4e57-8044-facdff9db157], X, Y: 247.4000 mm, 75.6543 mm, Rounded X, Y, 247.4000 mm, 75.6500 mm
Info: 74 C60 UUID: [1aca5681-7aa6-4eae-8c99-50777c4894db], X, Y: 242.0500 mm, 77.2043 mm, Rounded X, Y, 242.0500 mm, 77.2000 mm
Info: 75 C55 UUID: [64789ba1-d945-4e19-bb37-73597674a88f], X, Y: 247.4000 mm, 77.2043 mm, Rounded X, Y, 247.4000 mm, 77.2000 mm
Info: 76 C32 UUID: [14a53fb3-99f8-489f-988a-c0d3d55cb28b], X, Y: 255.8478 mm, 77.9872 mm, Rounded X, Y, 255.8500 mm, 77.9900 mm
Info: 77 C36 UUID: [f15d8941-e5d2-4ee2-8736-35d1b2f31cb2], X, Y: 257.3878 mm, 77.9872 mm, Rounded X, Y, 257.3900 mm, 77.9900 mm
Info: 78 C82 UUID: [6ef30bfa-4d68-4507-b1f2-4bea123a0a5a], X, Y: 269.2950 mm, 79.6050 mm, Rounded X, Y, 269.2900 mm, 79.6000 mm
Info: 79 C84 UUID: [a446a4bd-c0df-4521-8cd9-9cb94f0fa056], X, Y: 270.8550 mm, 79.6050 mm, Rounded X, Y, 270.8500 mm, 79.6000 mm
Info: 80 C88 UUID: [8463b486-db9d-4652-a5f6-722ed7121eba], X, Y: 262.7550 mm, 81.7700 mm, Rounded X, Y, 262.7500 mm, 81.7700 mm
Info: 81 C80 UUID: [4c3c566b-5d3a-42f0-a0f5-fa1979fedb7f], X, Y: 269.2900 mm, 82.6750 mm, Rounded X, Y, 269.2900 mm, 82.6700 mm
Info: 82 C81 UUID: [2325ae8a-9804-4d09-ac61-9ae66fe9b83e], X, Y: 270.8650 mm, 82.6750 mm, Rounded X, Y, 270.8600 mm, 82.6700 mm
Info: 83 C89 UUID: [5f072146-6b82-489f-af77-0c9758aad44e], X, Y: 262.7550 mm, 83.3000 mm, Rounded X, Y, 262.7500 mm, 83.3000 mm
Info: 84 R51 UUID: [d3d52359-4704-4c2a-a3da-5151eeeac1fc], X, Y: 259.7250 mm, 84.8247 mm, Rounded X, Y, 259.7200 mm, 84.8200 mm
Info: 85 C90 UUID: [3f49c6aa-37d6-41fd-9675-601b58a2e473], X, Y: 262.7550 mm, 84.8250 mm, Rounded X, Y, 262.7500 mm, 84.8200 mm
Info: 86 C87 UUID: [cf0b5247-64ae-477a-9c4c-9681fd84ab8b], X, Y: 265.8150 mm, 84.8200 mm, Rounded X, Y, 265.8100 mm, 84.8200 mm
Info: 87 C79 UUID: [b17ae80e-a340-4fae-baa4-af3df43b9a92], X, Y: 269.2950 mm, 85.6650 mm, Rounded X, Y, 269.2900 mm, 85.6600 mm
Info: 88 C77 UUID: [9976fec7-33ce-4dee-8290-4d3804dd5e30], X, Y: 270.8550 mm, 85.6650 mm, Rounded X, Y, 270.8500 mm, 85.6600 mm
Info: 89 C86 UUID: [2b14adac-cca2-4896-8bab-3a1fc486090b], X, Y: 265.8150 mm, 86.3450 mm, Rounded X, Y, 265.8100 mm, 86.3400 mm
Info: 90 R50 UUID: [ddaad275-5139-407c-8e36-15cf66ac78c7], X, Y: 262.7550 mm, 86.3600 mm, Rounded X, Y, 262.7500 mm, 86.3600 mm
Info: 91 C67 UUID: [af6de374-1a94-4cad-b07a-19ae085d0789], X, Y: 251.9150 mm, 87.5800 mm, Rounded X, Y, 251.9100 mm, 87.5800 mm
Info: 92 C69 UUID: [b4d3db8c-66ea-4e6c-a40f-011e0b2b021a], X, Y: 256.6650 mm, 87.5900 mm, Rounded X, Y, 256.6600 mm, 87.5900 mm
Info: 93 C92 UUID: [71745492-fbdf-4764-ab22-c14f16e7d789], X, Y: 262.7550 mm, 87.8900 mm, Rounded X, Y, 262.7500 mm, 87.8900 mm
Info: 94 C91 UUID: [6105f66b-49cc-4e83-8855-35e84d62db66], X, Y: 262.7550 mm, 89.4150 mm, Rounded X, Y, 262.7500 mm, 89.4100 mm
Info: 95 D2 UUID: [32c6056e-b8fa-4c46-ad0c-09c0b4bb2de6], X, Y: 253.5350 mm, 90.2150 mm, Rounded X, Y, 253.5300 mm, 90.2100 mm
Info: 96 P13 UUID: [62fae5db-aefd-49f4-bd23-c8258f8de2a8], X, Y: 266.3600 mm, 98.6300 mm, Rounded X, Y, 266.3600 mm, 98.6300 mm
Info: 97 C62 UUID: [185e717d-cafc-477b-8a94-8dd03b893b98], X, Y: 246.0750 mm, 98.8200 mm, Rounded X, Y, 246.0700 mm, 98.8200 mm
Info: 98 C66 UUID: [f1c13122-72ec-47d0-977a-e001c914b5f8], X, Y: 246.0750 mm, 100.3200 mm, Rounded X, Y, 246.0700 mm, 100.3200 mm
Info: 99 R47 UUID: [da550156-2ca0-4ce6-aea6-e89b7600c8fc], X, Y: 252.2250 mm, 100.9500 mm, Rounded X, Y, 252.2200 mm, 100.9500 mm
Info: 100 C64 UUID: [eccbf476-4db6-4dc1-8ec3-eb56c41e9f74], X, Y: 246.0750 mm, 101.8100 mm, Rounded X, Y, 246.0700 mm, 101.8100 mm
Info: 101 R48 UUID: [9885ea21-53d6-4293-a125-4684aced693e], X, Y: 252.2250 mm, 102.5500 mm, Rounded X, Y, 252.2200 mm, 102.5500 mm
Info: 102 D5 UUID: [98af2c1c-b6a7-4149-bfdf-bf548e98e423], X, Y: 255.1750 mm, 102.5880 mm, Rounded X, Y, 255.1700 mm, 102.5900 mm
Info: 103 P11 UUID: [ca42bf9c-0096-433a-b851-e6986d406de4], X, Y: 261.3100 mm, 104.4900 mm, Rounded X, Y, 261.3100 mm, 104.4900 mm
Info: 104 U7 UUID: [5dc85c26-8c89-40e3-b50e-35482bcb433a], X, Y: 246.1000 mm, 105.1350 mm, Rounded X, Y, 246.1000 mm, 105.1300 mm
Info: 105 C72 UUID: [27181084-a42d-4a0a-8ead-00b229558e3c], X, Y: 246.0500 mm, 109.7200 mm, Rounded X, Y, 246.0500 mm, 109.7200 mm
Info: 106 P9 UUID: [deb69fe6-822d-45f4-accb-86c7bc72f6a5], X, Y: 266.7100 mm, 110.8200 mm, Rounded X, Y, 266.7100 mm, 110.8200 mm
Info: 107 C74 UUID: [0ea40afa-ad0b-4a97-8bed-5210c8e03f19], X, Y: 246.0500 mm, 111.2200 mm, Rounded X, Y, 246.0500 mm, 111.2200 mm
Info: 108 U21 UUID: [a3bf3566-6d82-4a3a-93da-8f83a1066455], X, Y: 191.5000 mm, 111.3000 mm, Rounded X, Y, 191.5000 mm, 111.3000 mm
Info: 109 U19 UUID: [9d45ff23-ab3f-461c-a7ae-58c53f71fe04], X, Y: 210.5000 mm, 111.3000 mm, Rounded X, Y, 210.5000 mm, 111.3000 mm
Info: 110 U17 UUID: [1e6228d2-9c68-47f6-a7cc-da82c1324c88], X, Y: 222.0000 mm, 111.3000 mm, Rounded X, Y, 222.0000 mm, 111.3000 mm
Info: 111 U15 UUID: [b2af789e-e071-4e79-97b3-14a5a62d7887], X, Y: 240.5000 mm, 111.3000 mm, Rounded X, Y, 240.5000 mm, 111.3000 mm
Info: 
Info: 
Info: There are 10 types of reference designations
Info: **********************************************************
Info: H P R S U C D G*** Q FB 
Info:     Change Array
Info: ***********************
Info: C1 -> C22   
Info: C2 -> C18   
Info: C3 -> C23   
Info: C4 -> C10   
Info: C5 -> C26   
Info: C6 -> C9   
Info: C7 -> C24   
Info: C8 -> C34   
Info: C9 -> C29   
Info: C10 -> C11   
Info: C11 -> C5   
Info: C12 -> C35   
Info: C13 -> C17   
Info: C14 -> C19   
Info: C15 -> C3   
Info: C16 -> C6   
Info: C17 -> C27   
Info: C18 -> C26   
Info: C19 -> C8   
Info: C20 -> C7   
Info: C21 -> C32   
Info: C22 -> C10   
Info: C23 -> C33   
Info: C24 -> C21   
Info: C25 -> C12   
Info: C26 -> C13   
Info: C27 -> C37   
Info: C28 -> C28   
Info: C29 -> C31   
Info: C30 -> C11   
Info: C31 -> C14   
Info: C32 -> C49   
Info: C33 -> C15   
Info: C34 -> C39   
Info: C35 -> C42   
Info: C36 -> C50   
Info: C37 -> C14   
Info: C38 -> C16   
Info: C39 -> C17   
Info: C40 -> C23   
Info: C41 -> C24   
Info: C42 -> C16   
Info: C43 -> C15   
Info: C44 -> C27   
Info: C45 -> C13   
Info: C46 -> C28   
Info: C47 -> C18   
Info: C48 -> C30   
Info: C49 -> C21   
Info: C50 -> C32   
Info: C51 -> C25   
Info: C52 -> C19   
Info: C53 -> C20   
Info: C54 -> C31   
Info: C55 -> C48   
Info: C56 -> C36   
Info: C57 -> C46   
Info: C58 -> C38   
Info: C59 -> C45   
Info: C60 -> C47   
Info: C61 -> C38   
Info: C62 -> C66   
Info: C63 -> C35   
Info: C64 -> C68   
Info: C65 -> C36   
Info: C66 -> C67   
Info: C67 -> C62   
Info: C68 -> C46   
Info: C69 -> C63   
Info: C70 -> C52   
Info: C71 -> C37   
Info: C72 -> C69   
Info: C73 -> C34   
Info: C74 -> C70   
Info: C75 -> C45   
Info: C76 -> C47   
Info: C77 -> C60   
Info: C78 -> C41   
Info: C79 -> C59   
Info: C80 -> C54   
Info: C81 -> C55   
Info: C82 -> C51   
Info: C83 -> C42   
Info: C84 -> C52   
Info: C85 -> C30   
Info: C86 -> C61   
Info: C87 -> C58   
Info: C88 -> C53   
Info: C89 -> C56   
Info: C90 -> C57   
Info: C91 -> C65   
Info: C92 -> C64   
Info: C93 -> C4   
Info: C94 -> C2   
Info: C95 -> C3   
Info: C96 -> C1   
Info: C97 -> C54   
Info: C98 -> C56   
Info: C99 -> C53   
Info: C100 -> C55   
Info: C101 -> C59   
Info: C102 -> C6   
Info: C103 -> C60   
Info: C104 -> C5   
Info: C105 -> C58   
Info: C106 -> C7   
Info: C107 -> C57   
Info: C108 -> C8   
Info: C109 -> C4   
Info: C110 -> C2   
Info: C111 -> C40   
Info: C112 -> C39   
Info: C113 -> C43   
Info: C114 -> C44   
Info: C115 -> C44   
Info: C116 -> C43   
Info: C117 -> C41   
Info: C118 -> C40   
Info: C119 -> C22   
Info: C120 -> C20   
Info: C121 -> C9   
Info: C122 -> C12   
Info: C123 -> C50   
Info: C124 -> C49   
Info: C125 -> C25   
Info: C126 -> C51   
Info: C127 -> C48   
Info: C128 -> C33   
Info: C129 -> C29   
Info: D1 -> D5   
Info: D2 -> D3   
Info: D3 -> D4   
Info: D4 -> D2   
Info: D5 -> D4   
Info: D6 -> D2   
Info: D7 -> D1   
Info: D8 -> D3   
Info: FB1 -> FB1   
Info: G*** -> G***2   
Info: G*** -> G***1   
Info: H1 -> H1  Excluded  will be ignored
Info: H2 -> H2  Excluded  will be ignored
Info: H3 -> H3  Excluded  will be ignored
Info: H4 -> H4  Excluded  will be ignored
Info: P1 -> P1  Excluded  will be ignored
Info: P2 -> P2  Excluded  will be ignored
Info: P3 -> P3  Excluded  will be ignored
Info: P4 -> P4  Excluded  will be ignored
Info: P5 -> P5  Excluded  will be ignored
Info: P6 -> P6  Excluded  will be ignored
Info: P7 -> P7  Excluded  will be ignored
Info: P8 -> P8  Excluded  will be ignored
Info: P9 -> P9  Excluded  will be ignored
Info: P10 -> P10   
Info: P11 -> P11  Excluded  will be ignored
Info: P12 -> P12  Excluded  will be ignored
Info: P13 -> P13  Excluded  will be ignored
Info: P14 -> P14   
Info: P15 -> P15   
Info: Q1 -> Q3   
Info: Q2 -> Q2   
Info: Q3 -> Q1   
Info: Q4 -> Q2   
Info: R1 -> R3   
Info: R2 -> R2   
Info: R3 -> R19   
Info: R4 -> R16   
Info: R5 -> R4   
Info: R6 -> R5   
Info: R7 -> R7   
Info: R8 -> R6   
Info: R9 -> R9   
Info: R10 -> R16   
Info: R11 -> R15   
Info: R12 -> R8   
Info: R13 -> R17   
Info: R14 -> R18   
Info: R15 -> R9   
Info: R16 -> R34   
Info: R17 -> R33   
Info: R18 -> R32   
Info: R19 -> R35   
Info: R20 -> R10   
Info: R21 -> R11   
Info: R22 -> R13   
Info: R23 -> R12   
Info: R24 -> R13   
Info: R25 -> R14   
Info: R26 -> R10   
Info: R27 -> R11   
Info: R28 -> R20   
Info: R29 -> R21   
Info: R30 -> R15   
Info: R31 -> R14   
Info: R32 -> R30   
Info: R33 -> R26   
Info: R34 -> R18   
Info: R35 -> R17   
Info: R37 -> R29   
Info: R38 -> R31   
Info: R41 -> R42   
Info: R42 -> R41   
Info: R43 -> R50   
Info: R44 -> R48   
Info: R45 -> R45   
Info: R46 -> R49   
Info: R47 -> R21   
Info: R48 -> R22   
Info: R49 -> R5   
Info: R50 -> R20   
Info: R51 -> R19   
Info: R52 -> R40   
Info: R53 -> R39   
Info: R54 -> R6   
Info: R55 -> R7   
Info: R56 -> R8   
Info: R57 -> R2   
Info: R58 -> R3   
Info: R59 -> R4   
Info: R60 -> R44   
Info: R61 -> R36   
Info: R62 -> R47   
Info: R63 -> R12   
Info: R64 -> R25   
Info: R65 -> R22   
Info: R66 -> R23   
Info: R67 -> R24   
Info: R68 -> R46   
Info: R69 -> R37   
Info: R70 -> R27   
Info: R71 -> R28   
Info: R72 -> R38   
Info: R73 -> R43   
Info: R74 -> R74  Excluded  will be ignored
Info: R75 -> R75  Excluded  will be ignored
Info: S1 -> S1  Excluded  will be ignored
Info: U1 -> U4   
Info: U2 -> U2   
Info: U3 -> U5   
Info: U4 -> U3   
Info: U5 -> U6   
Info: U6 -> U13   
Info: U7 -> U4   
Info: U8 -> U17   
Info: U9 -> U9   
Info: U10 -> U12   
Info: U11 -> U10   
Info: U12 -> U11   
Info: U13 -> U8   
Info: U15 -> U15  Excluded  will be ignored
Info: U16 -> U16  Excluded  will be ignored
Info: U17 -> U6   
Info: U18 -> U3   
Info: U19 -> U5   
Info: U20 -> U2   
Info: U21 -> U21  Excluded  will be ignored
Info: U22 -> U22  Excluded  will be ignored
Info: U23 -> U14   
Info: U24 -> U7   
Info: 
Info: U13 -> U8   
Info: U15 -> U15  Excluded  will be ignored
Info: U16 -> U16  Excluded  will be ignored
Info: U17 -> U6   
Info: U18 -> U3   
Info: U19 -> U5   
Info: U20 -> U2   
Info: U21 -> U21  Excluded  will be ignored
Info: U22 -> U22  Excluded  will be ignored
Info: U23 -> U14   
Info: U24 -> U7   
Info: 
Info: 
Info: Only selected footprints will be reannotated.
Info: Front footprints will start at 1
Info: Back footprints will start at 1.
Info: Prior to sorting by footprint location, the coordinates of which will be rounded to a 0.0100 mm, 0.0100 mm grid.
Info: 
Info: 
Info: Front Footprints
Info: *********** Sort on Footprint Coordinates ***********
Info: Sort Code 1
Info: 1 H4 UUID: [5ef39d40-b55b-4409-b36c-55ace9773fcc], X, Y: 270.2001 mm, 31.4900 mm, Rounded X, Y, 270.2000 mm, 31.4900 mm
Info: 2 H3 UUID: [7f6b7f0f-1088-4a6f-96c7-380cabd2f233], X, Y: 162.2002 mm, 31.4900 mm, Rounded X, Y, 162.2000 mm, 31.4900 mm
Info: 3 P1 UUID: [6f78a790-197d-4599-be1c-a15c64767265], X, Y: 260.8551 mm, 34.3800 mm, Rounded X, Y, 260.8600 mm, 34.3800 mm
Info: 4 P2 UUID: [7a461615-ffd7-4d30-9663-87001a941793], X, Y: 237.0701 mm, 34.3800 mm, Rounded X, Y, 237.0700 mm, 34.3800 mm
Info: 5 P3 UUID: [b7c12510-6d3f-4c6a-94f6-3d0dc28c4cde], X, Y: 213.2476 mm, 34.3800 mm, Rounded X, Y, 213.2500 mm, 34.3800 mm
Info: 6 P4 UUID: [4b9d0df7-170f-4f7f-a033-8b28d6827d94], X, Y: 189.3551 mm, 34.3800 mm, Rounded X, Y, 189.3600 mm, 34.3800 mm
Info: 7 R74 UUID: [192819fe-81a5-48ce-b989-7daec683b7d6], X, Y: 285.6400 mm, 38.6100 mm, Rounded X, Y, 285.6400 mm, 38.6100 mm
Info: 8 R75 UUID: [aceaaa9f-2b43-44a9-b572-54237d9b5ddd], X, Y: 284.1000 mm, 38.6100 mm, Rounded X, Y, 284.1000 mm, 38.6100 mm
Info: 9 C96 UUID: [d31a0397-f6ec-4a75-b0f9-c2d860a3d8c2], X, Y: 243.1000 mm, 41.3000 mm, Rounded X, Y, 243.1000 mm, 41.3000 mm
Info: 10 C94 UUID: [c2bd5aec-4e19-4a4d-851d-8b688b552ec4], X, Y: 241.6000 mm, 41.3000 mm, Rounded X, Y, 241.6000 mm, 41.3000 mm
Info: 11 C95 UUID: [f7d8199e-b9d8-48f1-bcea-ccafea0f0110], X, Y: 224.1000 mm, 41.5000 mm, Rounded X, Y, 224.1000 mm, 41.5000 mm
Info: 12 C93 UUID: [2ff3868e-4557-4a7c-8d10-9de1767db7a0], X, Y: 222.6000 mm, 41.5000 mm, Rounded X, Y, 222.6000 mm, 41.5000 mm
Info: 13 C104 UUID: [77131fb7-b846-4782-86b5-000abba21fb8], X, Y: 213.1000 mm, 41.5000 mm, Rounded X, Y, 213.1000 mm, 41.5000 mm
Info: 14 C102 UUID: [9f405f32-2f64-4263-b93f-015da219d625], X, Y: 211.6000 mm, 41.5000 mm, Rounded X, Y, 211.6000 mm, 41.5000 mm
Info: 15 C106 UUID: [21935355-0ea7-4418-bf57-3f39151b43f0], X, Y: 194.6000 mm, 41.5000 mm, Rounded X, Y, 194.6000 mm, 41.5000 mm
Info: 16 C108 UUID: [5b7d43c3-fe25-4339-ba2b-cab150709af7], X, Y: 193.0000 mm, 41.5000 mm, Rounded X, Y, 193.0000 mm, 41.5000 mm
Info: 17 D7 UUID: [b641bdf0-49eb-4e1c-94cb-5314bfd786c3], X, Y: 171.2000 mm, 43.1000 mm, Rounded X, Y, 171.2000 mm, 43.1000 mm
Info: 18 D6 UUID: [15c5f8f7-2afb-450d-b21e-f225e625be45], X, Y: 167.8000 mm, 43.1000 mm, Rounded X, Y, 167.8000 mm, 43.1000 mm
Info: 19 D8 UUID: [ad3ab07d-9057-4924-bd8b-8088b57ed8a1], X, Y: 164.4000 mm, 43.1000 mm, Rounded X, Y, 164.4000 mm, 43.1000 mm
Info: 20 R2 UUID: [6c8bd184-798c-4f7b-a843-9cd77462ab86], X, Y: 285.1250 mm, 43.3700 mm, Rounded X, Y, 285.1200 mm, 43.3700 mm
Info: 21 R1 UUID: [0578c37e-47f8-452a-a67a-b190503e62a1], X, Y: 285.1300 mm, 44.9400 mm, Rounded X, Y, 285.1300 mm, 44.9400 mm
Info: 22 C6 UUID: [90d4da69-4018-498f-bb6b-4cfebdb4cb5a], X, Y: 256.9948 mm, 45.9200 mm, Rounded X, Y, 256.9900 mm, 45.9200 mm
Info: 23 R5 UUID: [0b83f195-4963-4ca1-a54c-d24446b93c1d], X, Y: 255.4698 mm, 45.9200 mm, Rounded X, Y, 255.4700 mm, 45.9200 mm
Info: 24 R6 UUID: [a8cb8963-6a5a-49e4-a7a4-19c73d057da1], X, Y: 248.5198 mm, 45.9767 mm, Rounded X, Y, 248.5200 mm, 45.9800 mm
Info: 25 C4 UUID: [b4efda08-249d-4e6f-88e2-4c848a29d86f], X, Y: 246.9948 mm, 46.0017 mm, Rounded X, Y, 246.9900 mm, 46.0000 mm
Info: 26 U2 UUID: [b464a15f-49cd-483f-929b-b1d63c0dfe61], X, Y: 252.9200 mm, 47.6602 mm, Rounded X, Y, 252.9200 mm, 47.6600 mm
Info: 27 G*** UUID: [f62f571e-809b-4679-b4e9-53366150a207], X, Y: 171.0000 mm, 48.1000 mm, Rounded X, Y, 171.0000 mm, 48.1000 mm
Info: 28 G*** UUID: [f1c5bfbf-437b-4444-ade4-cd4697dfba52], X, Y: 164.1000 mm, 48.1000 mm, Rounded X, Y, 164.1000 mm, 48.1000 mm
Info: 29 R8 UUID: [c76515d9-e052-481d-a8d4-7fa5a038c2eb], X, Y: 256.9948 mm, 49.0200 mm, Rounded X, Y, 256.9900 mm, 49.0200 mm
Info: 30 R7 UUID: [2f5d750f-5572-471e-ad27-fa2c6e839281], X, Y: 246.9948 mm, 49.1017 mm, Rounded X, Y, 246.9900 mm, 49.1000 mm
Info: 31 R12 UUID: [ef9dd0d9-21e3-49e7-af84-aa2227a2675a], X, Y: 253.7200 mm, 51.2950 mm, Rounded X, Y, 253.7200 mm, 51.2900 mm
Info: 32 R15 UUID: [7903577e-90f3-4db0-83ab-298ddfa54431], X, Y: 252.1200 mm, 51.3200 mm, Rounded X, Y, 252.1200 mm, 51.3200 mm
Info: 33 R20 UUID: [e50c0e15-2a00-42e9-969f-a33d5defc610], X, Y: 255.9700 mm, 52.0450 mm, Rounded X, Y, 255.9700 mm, 52.0400 mm
Info: 34 R21 UUID: [9a23b505-a1c1-4c55-8e94-07d0a04f6fc8], X, Y: 249.8700 mm, 52.0700 mm, Rounded X, Y, 249.8700 mm, 52.0700 mm
Info: 35 C30 UUID: [ee7c2646-8918-4316-a13c-a55547939d0d], X, Y: 256.7200 mm, 54.3200 mm, Rounded X, Y, 256.7200 mm, 54.3200 mm
Info: 36 R23 UUID: [0a22617f-48e2-405b-8c59-09456fa25df2], X, Y: 255.2200 mm, 54.3200 mm, Rounded X, Y, 255.2200 mm, 54.3200 mm
Info: 37 C25 UUID: [2add6fbd-b38e-45b6-a212-125797d8d517], X, Y: 253.7200 mm, 54.3200 mm, Rounded X, Y, 253.7200 mm, 54.3200 mm
Info: 38 C26 UUID: [f990f52e-1060-43c0-97b5-9bdc75fcd620], X, Y: 252.1200 mm, 54.3450 mm, Rounded X, Y, 252.1200 mm, 54.3400 mm
Info: 39 R22 UUID: [0b8f20a1-43ed-46d2-8b26-702ba0309f43], X, Y: 250.6200 mm, 54.3450 mm, Rounded X, Y, 250.6200 mm, 54.3400 mm
Info: 40 C31 UUID: [b8513cf6-7d74-49e5-a1db-c65cbb1ba585], X, Y: 249.1200 mm, 54.3450 mm, Rounded X, Y, 249.1200 mm, 54.3400 mm
Info: 41 R31 UUID: [a8602b57-4e29-4aee-9e20-8a3468aa8102], X, Y: 248.9902 mm, 57.5333 mm, Rounded X, Y, 248.9900 mm, 57.5300 mm
Info: 42 C43 UUID: [42c4c59c-cc5c-4fd7-a70a-157ab00b49dd], X, Y: 247.4902 mm, 57.5383 mm, Rounded X, Y, 247.4900 mm, 57.5400 mm
Info: 43 U4 UUID: [9b29cd54-7d87-4a06-95ed-141c28052086], X, Y: 252.9200 mm, 59.1200 mm, Rounded X, Y, 252.9200 mm, 59.1200 mm
Info: 44 R30 UUID: [542dc883-e43e-472f-abc6-3a26a651cfff], X, Y: 248.9902 mm, 60.7133 mm, Rounded X, Y, 248.9900 mm, 60.7100 mm
Info: 45 C42 UUID: [e14837a6-e638-4080-99ac-983030d82948], X, Y: 247.4802 mm, 60.7183 mm, Rounded X, Y, 247.4800 mm, 60.7200 mm
Info: 46 C13 UUID: [5c6f666c-9dd8-4829-8e80-5befac30e1d8], X, Y: 266.1745 mm, 63.2595 mm, Rounded X, Y, 266.1700 mm, 63.2600 mm
Info: 47 C2 UUID: [32d9b593-6e00-4ffd-a08a-8f7fab912e91], X, Y: 264.6745 mm, 63.2595 mm, Rounded X, Y, 264.6700 mm, 63.2600 mm
Info: 48 R4 UUID: [335eb178-9181-4ef2-a296-3c4829b20506], X, Y: 263.1745 mm, 63.2595 mm, Rounded X, Y, 263.1700 mm, 63.2600 mm
Info: 49 C52 UUID: [90c07117-21cb-4709-aafc-49395e5940fc], X, Y: 250.6200 mm, 63.8950 mm, Rounded X, Y, 250.6200 mm, 63.8900 mm
Info: 50 C53 UUID: [f0b0f0b8-d6ab-47f5-b3d7-a419942acf09], X, Y: 255.1200 mm, 63.9200 mm, Rounded X, Y, 255.1200 mm, 63.9200 mm
Info: 51 R35 UUID: [96bb19ba-ff89-4c77-a440-9e0a11db0f5c], X, Y: 253.6200 mm, 63.9200 mm, Rounded X, Y, 253.6200 mm, 63.9200 mm
Info: 52 R34 UUID: [92833a25-9b29-40f2-9ff9-85f116f08a3f], X, Y: 252.1200 mm, 63.9200 mm, Rounded X, Y, 252.1200 mm, 63.9200 mm
Info: 53 R3 UUID: [eb0800e6-e528-4757-9302-dcfdf8abad5f], X, Y: 261.0995 mm, 65.1095 mm, Rounded X, Y, 261.1000 mm, 65.1100 mm
Info: 54 C49 UUID: [4f0d0ace-e127-46ac-950d-6772649d938a], X, Y: 252.8700 mm, 66.1400 mm, Rounded X, Y, 252.8700 mm, 66.1400 mm
Info: 55 C1 UUID: [0938bcb7-e6c9-4788-b5e6-9acbacb9b62b], X, Y: 261.0995 mm, 66.6095 mm, Rounded X, Y, 261.1000 mm, 66.6100 mm
Info: 56 U1 UUID: [93391fc0-2245-4688-ae4c-8d46a3492553], X, Y: 265.2445 mm, 67.3595 mm, Rounded X, Y, 265.2400 mm, 67.3600 mm
Info: 57 R28 UUID: [82640fbd-3c73-4450-a22e-da4ba30d7b63], X, Y: 258.1450 mm, 67.8500 mm, Rounded X, Y, 258.1400 mm, 67.8500 mm
Info: 58 R29 UUID: [e7bf863f-b7ab-4ead-b51e-bc27fb58766e], X, Y: 255.1700 mm, 67.8500 mm, Rounded X, Y, 255.1700 mm, 67.8500 mm
Info: 59 R65 UUID: [75d41bf9-6a28-4542-b1f4-cd0ecc474c5b], X, Y: 174.7400 mm, 69.1100 mm, Rounded X, Y, 174.7400 mm, 69.1100 mm
Info: 60 R66 UUID: [11961651-8c18-44a2-9be0-223b05e9f2bd], X, Y: 171.6600 mm, 69.1100 mm, Rounded X, Y, 171.6600 mm, 69.1100 mm
Info: 61 R67 UUID: [c720f2e8-cac0-49f0-894e-f5031baecdde], X, Y: 168.6100 mm, 69.1100 mm, Rounded X, Y, 168.6100 mm, 69.1100 mm
Info: 62 C40 UUID: [958d8925-0e3f-4da3-a6b1-bfae443f6cfd], X, Y: 258.1450 mm, 69.3500 mm, Rounded X, Y, 258.1400 mm, 69.3500 mm
Info: 63 C41 UUID: [71bd50be-7db5-4780-bbec-b6e8ed043e99], X, Y: 255.1700 mm, 69.3500 mm, Rounded X, Y, 255.1700 mm, 69.3500 mm
Info: 64 R64 UUID: [2fd27f65-5d80-4188-b2bf-acc531168e70], X, Y: 174.7400 mm, 70.6600 mm, Rounded X, Y, 174.7400 mm, 70.6600 mm
Info: 65 C51 UUID: [8e789659-96b5-4a8d-93cb-7298e7069d96], X, Y: 251.8772 mm, 71.0578 mm, Rounded X, Y, 251.8800 mm, 71.0600 mm
Info: 66 C18 UUID: [9996c1e2-bf8a-4331-acff-6dbfe163533c], X, Y: 266.6445 mm, 71.8678 mm, Rounded X, Y, 266.6400 mm, 71.8700 mm
Info: 67 C17 UUID: [0a662090-924a-41f9-9c84-ecfee2765f3e], X, Y: 265.0445 mm, 71.8678 mm, Rounded X, Y, 265.0400 mm, 71.8700 mm
Info: 68 C28 UUID: [28542c89-831f-46a2-9572-15f587ab3dd8], X, Y: 260.5450 mm, 71.8900 mm, Rounded X, Y, 260.5400 mm, 71.8900 mm
Info: 69 Q3 UUID: [d3c47d26-7908-49cc-ab0e-07a830d9cec5], X, Y: 178.5000 mm, 72.0500 mm, Rounded X, Y, 178.5000 mm, 72.0500 mm
Info: 70 R33 UUID: [9946b09b-2d8e-41c4-9b8b-ed51b1f0b4bf], X, Y: 251.8772 mm, 72.5578 mm, Rounded X, Y, 251.8800 mm, 72.5600 mm
Info: 71 R70 UUID: [7aacb1dd-9b5b-400c-b776-7248739c89ff], X, Y: 175.5100 mm, 72.9800 mm, Rounded X, Y, 175.5100 mm, 72.9800 mm
Info: 72 R71 UUID: [8ef63d0b-c40a-4028-9155-7be2f9ffa36c], X, Y: 183.0100 mm, 72.9900 mm, Rounded X, Y, 183.0100 mm, 72.9900 mm
Info: 73 C129 UUID: [42e22537-8a59-4884-bd3a-296ff192f30d], X, Y: 181.4800 mm, 73.0000 mm, Rounded X, Y, 181.4800 mm, 73.0000 mm
Info: 74 R37 UUID: [cb7e0a10-8b63-4d06-a672-9a51c28baffb], X, Y: 240.6750 mm, 73.2543 mm, Rounded X, Y, 240.6700 mm, 73.2500 mm
Info: 75 C48 UUID: [37e90919-1fd3-4491-a9f2-abbb7c6a93ce], X, Y: 249.6772 mm, 73.3578 mm, Rounded X, Y, 249.6800 mm, 73.3600 mm
Info: 76 U3 UUID: [83b39ec6-0a03-45f8-aae0-940e61a7cd70], X, Y: 256.5929 mm, 73.4056 mm, Rounded X, Y, 256.5900 mm, 73.4100 mm
Info: 77 U5 UUID: [bf2f306b-7e48-4394-9dde-f34ee5ca8ec2], X, Y: 244.7600 mm, 73.9632 mm, Rounded X, Y, 244.7600 mm, 73.9600 mm
Info: 78 R32 UUID: [bb950574-61bb-4618-8728-ac44e25a7a25], X, Y: 251.8772 mm, 74.2578 mm, Rounded X, Y, 251.8800 mm, 74.2600 mm
Info: 79 U24 UUID: [46db3e31-f72d-4b19-8aa0-55fdef644baa], X, Y: 170.2400 mm, 74.3900 mm, Rounded X, Y, 170.2400 mm, 74.3900 mm
Info: 80 R38 UUID: [45e4f1da-2cd8-4e6f-aa8f-689a94f70921], X, Y: 240.6750 mm, 74.8043 mm, Rounded X, Y, 240.6700 mm, 74.8000 mm
Info: 81 R18 UUID: [2d249090-11f4-449d-862f-8733c097b5af], X, Y: 268.0900 mm, 74.8800 mm, Rounded X, Y, 268.0900 mm, 74.8800 mm
Info: 82 R17 UUID: [52124a33-5324-45fa-b076-c4332c089c58], X, Y: 266.5900 mm, 74.8800 mm, Rounded X, Y, 266.5900 mm, 74.8800 mm
Info: 83 R16 UUID: [4ee4ae8b-61c7-460c-873f-ed49651743e8], X, Y: 265.0900 mm, 74.8800 mm, Rounded X, Y, 265.0900 mm, 74.8800 mm
Info: 84 R19 UUID: [48259941-b1fb-4747-bfc0-4331eaabce95], X, Y: 263.5900 mm, 74.8800 mm, Rounded X, Y, 263.5900 mm, 74.8800 mm
Info: 85 C29 UUID: [c9b8090c-a012-4831-a62a-59edb3a90baf], X, Y: 260.5450 mm, 74.8900 mm, Rounded X, Y, 260.5400 mm, 74.8900 mm
Info: 86 R61 UUID: [97c48f85-5a6d-4bef-8746-bcdebd06ca61], X, Y: 197.1100 mm, 75.2500 mm, Rounded X, Y, 197.1100 mm, 75.2500 mm
Info: 87 C50 UUID: [9a103e91-c496-430d-9146-89abff106f87], X, Y: 251.8772 mm, 75.7578 mm, Rounded X, Y, 251.8800 mm, 75.7600 mm
Info: 88 Q4 UUID: [92dae593-27cc-438d-a171-3260aeebd602], X, Y: 178.4900 mm, 75.9200 mm, Rounded X, Y, 178.4900 mm, 75.9200 mm
Info: 89 R69 UUID: [fbef717e-a140-4706-a0a6-c307fe2c19e4], X, Y: 175.5000 mm, 76.0200 mm, Rounded X, Y, 175.5000 mm, 76.0200 mm
Info: 90 R72 UUID: [c3b5ef56-74ef-43ec-b9f8-07e69d639ad9], X, Y: 183.0100 mm, 76.0350 mm, Rounded X, Y, 183.0100 mm, 76.0300 mm
Info: 91 C128 UUID: [b37c6c1a-abc1-4336-984f-1696003b4358], X, Y: 181.4800 mm, 76.0300 mm, Rounded X, Y, 181.4800 mm, 76.0300 mm
Info: 92 U13 UUID: [78d52183-fc9f-473d-af48-32cb8a86e314], X, Y: 216.5000 mm, 76.5000 mm, Rounded X, Y, 216.5000 mm, 76.5000 mm
Info: 93 FB1 UUID: [13478164-44d8-4b70-9a3b-18f200deddfc], X, Y: 270.0850 mm, 78.5550 mm, Rounded X, Y, 270.0800 mm, 78.5500 mm
Info: 94 R53 UUID: [9d9169e7-d932-4355-8a5e-b13cc3a2fc9a], X, Y: 165.2800 mm, 80.8300 mm, Rounded X, Y, 165.2800 mm, 80.8300 mm
Info: 95 R52 UUID: [9be3b8fe-2aed-47e1-bf97-ad717698cc02], X, Y: 161.4700 mm, 80.8400 mm, Rounded X, Y, 161.4700 mm, 80.8400 mm
Info: 96 U9 UUID: [1e35901f-e7f0-47bc-aea6-8bbf3533fe51], X, Y: 270.0900 mm, 82.6500 mm, Rounded X, Y, 270.0900 mm, 82.6500 mm
Info: 97 U11 UUID: [81382938-a484-404e-ae45-0197ce3f233a], X, Y: 261.4800 mm, 82.7250 mm, Rounded X, Y, 261.4800 mm, 82.7200 mm
Info: 98 R42 UUID: [16936265-9da4-432d-a361-22a87bc4a26f], X, Y: 257.4100 mm, 85.3750 mm, Rounded X, Y, 257.4100 mm, 85.3700 mm
Info: 99 C73 UUID: [1ad55954-5086-4ae6-acf2-05f4ff0708cd], X, Y: 270.3350 mm, 86.6250 mm, Rounded X, Y, 270.3300 mm, 86.6200 mm
Info: 100 U12 UUID: [c8756d37-f96f-4413-a974-4dbac44a0e0c], X, Y: 261.4550 mm, 87.2400 mm, Rounded X, Y, 261.4500 mm, 87.2400 mm
Info: 101 U10 UUID: [ebbc979d-a82a-471c-b7ac-e64b771ab7d5], X, Y: 265.4700 mm, 87.2697 mm, Rounded X, Y, 265.4700 mm, 87.2700 mm
Info: 102 C63 UUID: [caec2e82-d955-4b57-b3b9-4b6088cd5e3d], X, Y: 250.9250 mm, 87.5800 mm, Rounded X, Y, 250.9200 mm, 87.5800 mm
Info: 103 C65 UUID: [8d6a3f03-ec70-4c74-8934-5b1887b0c26a], X, Y: 249.4250 mm, 87.5800 mm, Rounded X, Y, 249.4200 mm, 87.5800 mm
Info: 104 C71 UUID: [55d8539e-39e3-440e-aa96-8af5bcd2eee1], X, Y: 258.1650 mm, 87.5900 mm, Rounded X, Y, 258.1600 mm, 87.5900 mm
Info: 105 R41 UUID: [46e0d02b-21e0-4f5f-8bb2-290863801475], X, Y: 256.6400 mm, 87.5900 mm, Rounded X, Y, 256.6400 mm, 87.5900 mm
Info: 106 U6 UUID: [0e20234a-d07f-4b02-bfb0-6ca2c38105cb], X, Y: 253.9500 mm, 87.5900 mm, Rounded X, Y, 253.9500 mm, 87.5900 mm
Info: 107 C61 UUID: [a19f97a2-0a39-482e-9340-8934eb3161fc], X, Y: 247.8250 mm, 87.6300 mm, Rounded X, Y, 247.8200 mm, 87.6300 mm
Info: 108 R73 UUID: [34f28257-075d-435a-96ca-7744eb05a464], X, Y: 181.3600 mm, 88.2100 mm, Rounded X, Y, 181.3600 mm, 88.2100 mm
Info: 109 U23 UUID: [8e489fcd-25ef-4282-b196-fb724bde004c], X, Y: 164.1900 mm, 92.6300 mm, Rounded X, Y, 164.1900 mm, 92.6300 mm
Info: 110 R60 UUID: [9c9165ac-716c-46cf-b69d-ea14b7bfe4bd], X, Y: 181.3900 mm, 97.0800 mm, Rounded X, Y, 181.3900 mm, 97.0800 mm
Info: 111 C112 UUID: [b3a4c3e6-681c-43ad-9343-5eb646d4f70f], X, Y: 258.7750 mm, 97.8500 mm, Rounded X, Y, 258.7700 mm, 97.8500 mm
Info: 112 C111 UUID: [10518b7c-2576-4335-ac7a-e38c726bca78], X, Y: 256.9750 mm, 97.8500 mm, Rounded X, Y, 256.9700 mm, 97.8500 mm
Info: 113 C78 UUID: [fc19c4f7-798f-46df-b8b4-fb10653c19a8], X, Y: 255.3750 mm, 97.8500 mm, Rounded X, Y, 255.3700 mm, 97.8500 mm
Info: 114 C83 UUID: [871747f9-d1f0-4f8a-8771-37d32db82351], X, Y: 252.5750 mm, 97.8500 mm, Rounded X, Y, 252.5700 mm, 97.8500 mm
Info: 115 C113 UUID: [4e6f3825-9341-4cd0-9ea1-c2c481507c6b], X, Y: 250.7400 mm, 97.8800 mm, Rounded X, Y, 250.7400 mm, 97.8800 mm
Info: 116 C114 UUID: [731aa020-86a5-4998-b1e5-55071e2cfa29], X, Y: 249.1300 mm, 97.8900 mm, Rounded X, Y, 249.1300 mm, 97.8900 mm
Info: 117 C75 UUID: [bf49afb2-9e6b-4a9b-b75c-195b8a5a194a], X, Y: 258.7500 mm, 101.7000 mm, Rounded X, Y, 258.7500 mm, 101.7000 mm
Info: 118 C68 UUID: [bd7604c5-87b8-4bd9-9e37-649c4b42cdae], X, Y: 246.0750 mm, 102.5250 mm, Rounded X, Y, 246.0700 mm, 102.5200 mm
Info: 119 R45 UUID: [2d77b8ea-03f8-43d2-b213-4da4a284dabd], X, Y: 258.7750 mm, 105.2750 mm, Rounded X, Y, 258.7700 mm, 105.2700 mm
Info: 120 D3 UUID: [a303aa19-a577-4ba5-9a36-66e085dc6db1], X, Y: 248.8000 mm, 105.3250 mm, Rounded X, Y, 248.8000 mm, 105.3200 mm
Info: 121 C76 UUID: [197e5499-bc56-4f90-8c4c-8d2aa56a1aa0], X, Y: 160.1825 mm, 105.3450 mm, Rounded X, Y, 160.1800 mm, 105.3400 mm
Info: 122 C127 UUID: [8bc0ea16-b07c-4e84-a974-b827d275f5a0], X, Y: 167.8500 mm, 105.3500 mm, Rounded X, Y, 167.8500 mm, 105.3500 mm
Info: 123 R68 UUID: [e3e1f600-a238-4847-b7c3-b379d7babea4], X, Y: 166.3100 mm, 105.3500 mm, Rounded X, Y, 166.3100 mm, 105.3500 mm
Info: 124 C124 UUID: [ea8b2af2-85c3-459f-a29f-9c21bd1553b7], X, Y: 164.7700 mm, 105.3500 mm, Rounded X, Y, 164.7700 mm, 105.3500 mm
Info: 125 C123 UUID: [a40b12bd-43c8-462e-9491-b7479b20666d], X, Y: 163.2400 mm, 105.3500 mm, Rounded X, Y, 163.2400 mm, 105.3500 mm
Info: 126 C126 UUID: [034b6d13-24cd-4c7b-893b-aff3f8314eec], X, Y: 161.7125 mm, 105.3550 mm, Rounded X, Y, 161.7100 mm, 105.3500 mm
Info: 127 R62 UUID: [882d58ad-dfac-4c09-8126-2d39727f4f25], X, Y: 174.1600 mm, 105.3800 mm, Rounded X, Y, 174.1600 mm, 105.3800 mm
Info: 128 R44 UUID: [898fec02-e9f0-4f68-86df-85569242df45], X, Y: 246.0750 mm, 106.6250 mm, Rounded X, Y, 246.0700 mm, 106.6200 mm
Info: 129 U8 UUID: [b50be23b-ce1c-4528-8206-bf645533c790], X, Y: 253.9750 mm, 106.8500 mm, Rounded X, Y, 253.9700 mm, 106.8500 mm
Info: 130 R46 UUID: [a9e2d506-51b2-477d-b263-0ea3a860e4c6], X, Y: 268.6000 mm, 106.9250 mm, Rounded X, Y, 268.6000 mm, 106.9200 mm
Info: 131 R43 UUID: [10ff95ff-472d-4d51-9562-3d4d318a9c29], X, Y: 246.0750 mm, 108.1250 mm, Rounded X, Y, 246.0700 mm, 108.1200 mm
Info: 132 D1 UUID: [24954364-08ca-480b-a17f-cef42a647d11], X, Y: 263.8500 mm, 109.2250 mm, Rounded X, Y, 263.8500 mm, 109.2200 mm
Info: 133 C70 UUID: [5b89adf9-9731-4f8a-b8c1-e82e57f2cb4a], X, Y: 246.0750 mm, 109.6250 mm, Rounded X, Y, 246.0700 mm, 109.6200 mm
Info: 134 S1 UUID: [48bfdc01-b0cd-4f5b-bb75-2b3ad4a6ff9f], X, Y: 271.9100 mm, 110.5800 mm, Rounded X, Y, 271.9100 mm, 110.5800 mm
Info: 135 C99 UUID: [6bac4868-49c8-4e96-84cf-d7d4421e10a0], X, Y: 220.9500 mm, 111.4750 mm, Rounded X, Y, 220.9500 mm, 111.4700 mm
Info: 136 C97 UUID: [3f7c91bb-b0a0-416f-ac44-126083cffde2], X, Y: 219.4500 mm, 111.4750 mm, Rounded X, Y, 219.4500 mm, 111.4700 mm
Info: 137 C100 UUID: [006fd919-1196-470f-a248-f93a156f42f7], X, Y: 239.4000 mm, 111.5000 mm, Rounded X, Y, 239.4000 mm, 111.5000 mm
Info: 138 C98 UUID: [5f0202a2-1de2-4919-9405-f4d2a479cf56], X, Y: 237.9100 mm, 111.5000 mm, Rounded X, Y, 237.9100 mm, 111.5000 mm
Info: 139 C107 UUID: [456aeb2b-6826-4420-b620-80c6dc9e071b], X, Y: 190.4000 mm, 111.5000 mm, Rounded X, Y, 190.4000 mm, 111.5000 mm
Info: 140 C105 UUID: [479b4504-5605-4082-919a-baca47d55419], X, Y: 188.9000 mm, 111.5000 mm, Rounded X, Y, 188.9000 mm, 111.5000 mm
Info: 141 C101 UUID: [66ae25e1-8f78-438d-aa96-ca55ba5a4ab3], X, Y: 209.3000 mm, 111.5250 mm, Rounded X, Y, 209.3000 mm, 111.5200 mm
Info: 142 C103 UUID: [8c1789b1-5d02-4b6f-aa73-a8487ba46dee], X, Y: 207.8200 mm, 111.5250 mm, Rounded X, Y, 207.8200 mm, 111.5200 mm
Info: 143 P5 UUID: [0210975c-d641-4efc-aed9-abd36f5b2ca2], X, Y: 243.0751 mm, 118.7000 mm, Rounded X, Y, 243.0800 mm, 118.7000 mm
Info: 144 P6 UUID: [83e8e0fb-2eed-4111-9b7a-27ebbdb49fb5], X, Y: 219.2901 mm, 118.7000 mm, Rounded X, Y, 219.2900 mm, 118.7000 mm
Info: 145 P7 UUID: [65d166da-6e54-4899-bf21-78b437ce2ab8], X, Y: 195.4676 mm, 118.7000 mm, Rounded X, Y, 195.4700 mm, 118.7000 mm
Info: 146 P8 UUID: [95e88e77-ee7d-4a55-b131-b751971338ed], X, Y: 171.5751 mm, 118.7000 mm, Rounded X, Y, 171.5800 mm, 118.7000 mm
Info: 147 H2 UUID: [fe5f3cf4-30f5-4ecf-a7da-43bdebe2cf47], X, Y: 270.2002 mm, 121.6400 mm, Rounded X, Y, 270.2000 mm, 121.6400 mm
Info: 148 H1 UUID: [395c3b9a-2c81-4f50-bfcd-a053be469ada], X, Y: 162.2002 mm, 121.6400 mm, Rounded X, Y, 162.2000 mm, 121.6400 mm
Info: 
Info: 
Info: Back Footprints
Info: *********** Sort on Footprint Coordinates ***********
Info: Sort Code 1
Info: 1 Q2 UUID: [7229c1f7-ce77-4976-8be7-27a657ec73d2], X, Y: 163.1592 mm, 41.5988 mm, Rounded X, Y, 163.1600 mm, 41.6000 mm
Info: 2 Q1 UUID: [30fecc18-0e4a-4a8b-b8b0-44c7c2196f7b], X, Y: 170.0945 mm, 41.6000 mm, Rounded X, Y, 170.0900 mm, 41.6000 mm
Info: 3 U22 UUID: [050e1bcb-3371-4602-b469-575177afa360], X, Y: 192.0000 mm, 41.6000 mm, Rounded X, Y, 192.0000 mm, 41.6000 mm
Info: 4 U20 UUID: [c18eab44-b32e-4646-aba6-319c7960505b], X, Y: 210.5000 mm, 41.7000 mm, Rounded X, Y, 210.5000 mm, 41.7000 mm
Info: 5 U18 UUID: [cd526938-1c37-4fa0-a92d-cff8ee4bd1f4], X, Y: 221.5000 mm, 41.7000 mm, Rounded X, Y, 221.5000 mm, 41.7000 mm
Info: 6 U16 UUID: [89f3bab7-ff7c-4c47-a530-197c66f36b2d], X, Y: 240.5000 mm, 41.7000 mm, Rounded X, Y, 240.5000 mm, 41.7000 mm
Info: 7 C110 UUID: [03e42c5d-8b0c-4085-a1e8-a37b52982fbc], X, Y: 249.8148 mm, 43.6967 mm, Rounded X, Y, 249.8100 mm, 43.7000 mm
Info: 8 C15 UUID: [ab44f634-ee67-4827-abd4-6fd7dd2e327f], X, Y: 252.8948 mm, 43.6967 mm, Rounded X, Y, 252.8900 mm, 43.7000 mm
Info: 9 P12 UUID: [be7cb87d-abfc-4a7d-8c35-12d8b56fcde4], X, Y: 270.1900 mm, 44.3400 mm, Rounded X, Y, 270.1900 mm, 44.3400 mm
Info: 10 R57 UUID: [b0ca33c9-4d0c-4b03-88eb-a8d18a79b7de], X, Y: 161.8000 mm, 45.0000 mm, Rounded X, Y, 161.8000 mm, 45.0000 mm
Info: 11 R58 UUID: [9980ec04-e9a0-43dc-a3f1-5f8bc796ad5b], X, Y: 163.4000 mm, 45.0000 mm, Rounded X, Y, 163.4000 mm, 45.0000 mm
Info: 12 R59 UUID: [17009834-6e4e-4fd2-8ac3-a243e8945980], X, Y: 165.0000 mm, 45.0000 mm, Rounded X, Y, 165.0000 mm, 45.0000 mm
Info: 13 R49 UUID: [c1f2104a-f60c-4faa-9ee3-e336583210a3], X, Y: 166.8500 mm, 45.0000 mm, Rounded X, Y, 166.8500 mm, 45.0000 mm
Info: 14 R54 UUID: [a57788f3-d21e-43ec-96a4-4db259bb954d], X, Y: 168.7000 mm, 45.0000 mm, Rounded X, Y, 168.7000 mm, 45.0000 mm
Info: 15 R55 UUID: [e5a074a7-ff93-4fde-b2c1-47d7de951c20], X, Y: 170.3000 mm, 45.0000 mm, Rounded X, Y, 170.3000 mm, 45.0000 mm
Info: 16 R56 UUID: [59bd1d4b-a234-43d7-91a4-3c8593a3bf5e], X, Y: 171.9000 mm, 45.0000 mm, Rounded X, Y, 171.9000 mm, 45.0000 mm
Info: 17 C109 UUID: [7dfd4a95-0f0c-4c6b-b96e-75361dc62b3c], X, Y: 249.8148 mm, 45.2367 mm, Rounded X, Y, 249.8100 mm, 45.2400 mm
Info: 18 C11 UUID: [049301c4-836c-42b1-a93c-28aae55408d5], X, Y: 252.9048 mm, 45.2367 mm, Rounded X, Y, 252.9000 mm, 45.2400 mm
Info: 19 R9 UUID: [ddc9600e-c189-4ae7-a3a6-1a827ed62c65], X, Y: 252.9200 mm, 47.5603 mm, Rounded X, Y, 252.9200 mm, 47.5600 mm
Info: 20 C16 UUID: [f8b4dc17-7e6f-447d-8bdd-6c8de11b4e98], X, Y: 252.9200 mm, 49.0603 mm, Rounded X, Y, 252.9200 mm, 49.0600 mm
Info: 21 C20 UUID: [3903a7de-2080-4916-aaae-f6130c5d3cb4], X, Y: 252.9200 mm, 50.5950 mm, Rounded X, Y, 252.9200 mm, 50.5900 mm
Info: 22 C19 UUID: [39bd9ff3-0c14-4750-8a58-22cb13cea02b], X, Y: 252.9200 mm, 52.0950 mm, Rounded X, Y, 252.9200 mm, 52.0900 mm
Info: 23 C121 UUID: [5cff931d-c10b-49a5-bdc4-9d14b1c160c6], X, Y: 254.4298 mm, 55.3267 mm, Rounded X, Y, 254.4300 mm, 55.3300 mm
Info: 24 C22 UUID: [ee9cbc31-a358-4ecc-bc3d-8e179228e60d], X, Y: 251.3898 mm, 55.3367 mm, Rounded X, Y, 251.3900 mm, 55.3400 mm
Info: 25 C10 UUID: [f73535b3-97a4-4a32-a960-648bbaab0a5c], X, Y: 251.3898 mm, 56.8367 mm, Rounded X, Y, 251.3900 mm, 56.8400 mm
Info: 26 C122 UUID: [46f3186b-9cb4-4ee4-aef3-fed529b61380], X, Y: 254.4298 mm, 56.8367 mm, Rounded X, Y, 254.4300 mm, 56.8400 mm
Info: 27 P10 UUID: [ec5d0170-2e7d-4ac1-9c32-53fadbc043c3], X, Y: 168.5600 mm, 57.0440 mm, Rounded X, Y, 168.5600 mm, 57.0400 mm
Info: 28 C45 UUID: [b858d4fc-1ae7-42f9-b7ac-881b2e757188], X, Y: 248.3198 mm, 58.3847 mm, Rounded X, Y, 248.3200 mm, 58.3800 mm
Info: 29 R26 UUID: [3a0f3436-5902-44bc-af79-bc7e4335f373], X, Y: 251.3902 mm, 58.3833 mm, Rounded X, Y, 251.3900 mm, 58.3800 mm
Info: 30 C37 UUID: [50fdd1d1-0b1b-47f2-bd51-fb5c8551a03d], X, Y: 254.4252 mm, 58.3833 mm, Rounded X, Y, 254.4300 mm, 58.3800 mm
Info: 31 C33 UUID: [a5aafbc4-6857-4b48-8cc9-4a6ab1bbc515], X, Y: 257.4848 mm, 58.3967 mm, Rounded X, Y, 257.4800 mm, 58.4000 mm
Info: 32 R27 UUID: [e2a9378b-ff6a-4a83-85d5-d0135d33860c], X, Y: 251.3952 mm, 59.8833 mm, Rounded X, Y, 251.4000 mm, 59.8800 mm
Info: 33 C38 UUID: [54fb6744-6c33-4a2c-b97b-8eea48071cb5], X, Y: 254.4252 mm, 59.8833 mm, Rounded X, Y, 254.4300 mm, 59.8800 mm
Info: 34 C39 UUID: [bcd20e3b-b32f-4f3f-8683-84c74b424a31], X, Y: 257.4748 mm, 59.8867 mm, Rounded X, Y, 257.4700 mm, 59.8900 mm
Info: 35 C47 UUID: [31db70a3-321b-4b2d-9be7-cba2683b6363], X, Y: 248.3168 mm, 59.8967 mm, Rounded X, Y, 248.3200 mm, 59.9000 mm
Info: 36 P14 UUID: [050031de-379a-4826-b614-b1ad07b7f6ac], X, Y: 270.8900 mm, 60.1365 mm, Rounded X, Y, 270.8900 mm, 60.1400 mm
Info: 37 C14 UUID: [e2b7a84e-676c-4bba-944f-4f2f88f47a73], X, Y: 251.4048 mm, 61.4267 mm, Rounded X, Y, 251.4000 mm, 61.4300 mm
Info: 38 C120 UUID: [0a84a363-d903-4d0f-8b6f-94f535064747], X, Y: 254.4298 mm, 61.4267 mm, Rounded X, Y, 254.4300 mm, 61.4300 mm
Info: 39 C24 UUID: [5de24c5a-0d92-4307-b912-89667a998851], X, Y: 251.4048 mm, 62.9267 mm, Rounded X, Y, 251.4000 mm, 62.9300 mm
Info: 40 C119 UUID: [7fd84043-c517-481b-bdbf-37d6473c4a16], X, Y: 254.4298 mm, 62.9267 mm, Rounded X, Y, 254.4300 mm, 62.9300 mm
Info: 41 C3 UUID: [ed96ccc4-aab8-44f5-a1d3-3647cc28df2b], X, Y: 269.3945 mm, 66.8345 mm, Rounded X, Y, 269.3900 mm, 66.8300 mm
Info: 42 C7 UUID: [5496db35-6ef0-4639-a828-70c5c26991aa], X, Y: 264.6445 mm, 67.5595 mm, Rounded X, Y, 264.6400 mm, 67.5600 mm
Info: 43 C125 UUID: [989b15eb-2f2c-42ac-9b7c-a70612fe0c20], X, Y: 174.7400 mm, 68.2400 mm, Rounded X, Y, 174.7400 mm, 68.2400 mm
Info: 44 C5 UUID: [392aa572-63f2-4317-8b79-89485949724a], X, Y: 269.3945 mm, 68.3345 mm, Rounded X, Y, 269.3900 mm, 68.3300 mm
Info: 45 R63 UUID: [bc3c8697-07da-4b1b-ad16-618c560fa37a], X, Y: 164.7400 mm, 68.4100 mm, Rounded X, Y, 164.7400 mm, 68.4100 mm
Info: 46 C44 UUID: [55507068-597a-4c50-bc81-2b343b4ef596], X, Y: 255.8478 mm, 68.9222 mm, Rounded X, Y, 255.8500 mm, 68.9200 mm
Info: 47 C46 UUID: [f81f1620-d48f-402f-9ed9-161e797ba741], X, Y: 257.4078 mm, 68.9172 mm, Rounded X, Y, 257.4100 mm, 68.9200 mm
Info: 48 C9 UUID: [4cef2cbc-20a6-4f56-a97a-e50f88857f1b], X, Y: 264.6745 mm, 69.4678 mm, Rounded X, Y, 264.6700 mm, 69.4700 mm
Info: 49 C85 UUID: [8a1972e6-f9a8-44a3-9e4b-757b6644815c], X, Y: 174.7450 mm, 69.7800 mm, Rounded X, Y, 174.7400 mm, 69.7800 mm
Info: 50 P15 UUID: [5d4950f4-94a1-4ab0-b1e8-e2a42c64c274], X, Y: 160.4600 mm, 70.7400 mm, Rounded X, Y, 160.4600 mm, 70.7400 mm
Info: 51 D4 UUID: [1e6167bc-7806-4ced-a5f6-e99b2283d242], X, Y: 164.8600 mm, 70.9300 mm, Rounded X, Y, 164.8600 mm, 70.9300 mm
Info: 52 C54 UUID: [40ddb19d-527e-460f-8d1d-e7faa8b277a1], X, Y: 247.4350 mm, 70.9632 mm, Rounded X, Y, 247.4300 mm, 70.9600 mm
Info: 53 R24 UUID: [a2a2d179-1175-4308-97c7-fa03d9127053], X, Y: 257.4050 mm, 71.9450 mm, Rounded X, Y, 257.4000 mm, 71.9400 mm
Info: 54 C21 UUID: [48e97c7a-98fb-4b35-bf23-b7ea8c85fac9], X, Y: 258.9078 mm, 71.9422 mm, Rounded X, Y, 258.9100 mm, 71.9400 mm
Info: 55 C23 UUID: [afc90274-01fc-4028-8959-5f230f4849e8], X, Y: 260.4078 mm, 71.9372 mm, Rounded X, Y, 260.4100 mm, 71.9400 mm
Info: 56 C8 UUID: [0aa32a1a-9e2c-4456-bd4a-5561b9c2c8d2], X, Y: 252.7778 mm, 71.9472 mm, Rounded X, Y, 252.7800 mm, 71.9500 mm
Info: 57 C12 UUID: [2e30bc3b-cc4a-44d0-976b-0f64614a5a2e], X, Y: 254.2878 mm, 71.9472 mm, Rounded X, Y, 254.2900 mm, 71.9500 mm
Info: 58 R25 UUID: [c10bb1c8-a745-4d9e-94df-30c005a5e76b], X, Y: 255.8450 mm, 71.9500 mm, Rounded X, Y, 255.8400 mm, 71.9500 mm
Info: 59 C56 UUID: [6334eb73-f858-49e0-af73-47361ff9d93f], X, Y: 247.4250 mm, 72.4793 mm, Rounded X, Y, 247.4200 mm, 72.4800 mm
Info: 60 R11 UUID: [cbbe08ae-6596-485b-98a3-241e9911a242], X, Y: 264.2645 mm, 72.5595 mm, Rounded X, Y, 264.2600 mm, 72.5600 mm
Info: 61 R10 UUID: [54610e84-ea16-4391-9601-61ffbcf0932a], X, Y: 267.3745 mm, 72.5595 mm, Rounded X, Y, 267.3700 mm, 72.5600 mm
Info: 62 R13 UUID: [480c40d1-0b68-4f35-95b9-a10a108eb864], X, Y: 268.8695 mm, 74.0745 mm, Rounded X, Y, 268.8700 mm, 74.0700 mm
Info: 63 R14 UUID: [d6967e59-ac81-4c74-983a-85444f18308d], X, Y: 262.8045 mm, 74.0845 mm, Rounded X, Y, 262.8000 mm, 74.0800 mm
Info: 64 C27 UUID: [88129fd6-6252-4341-9a45-cdaa28cd6452], X, Y: 265.8372 mm, 74.0772 mm, Rounded X, Y, 265.8400 mm, 74.0800 mm
Info: 65 C58 UUID: [011c59c5-0c46-4eac-8687-1cafa03e01eb], X, Y: 247.4000 mm, 74.1043 mm, Rounded X, Y, 247.4000 mm, 74.1000 mm
Info: 66 C34 UUID: [35ff2996-b5d4-4622-9c88-75b7625d77bb], X, Y: 257.4050 mm, 74.9450 mm, Rounded X, Y, 257.4000 mm, 74.9400 mm
Info: 67 C118 UUID: [98c13ee8-4310-4a21-8db5-ff993a9f4ac1], X, Y: 252.7778 mm, 74.9472 mm, Rounded X, Y, 252.7800 mm, 74.9500 mm
Info: 68 C117 UUID: [a56c3097-6f1e-4290-85b5-70a21926c298], X, Y: 254.2878 mm, 74.9522 mm, Rounded X, Y, 254.2900 mm, 74.9500 mm
Info: 69 C35 UUID: [d4aa73aa-daa5-4297-91ba-12d88b780096], X, Y: 255.8450 mm, 74.9500 mm, Rounded X, Y, 255.8500 mm, 74.9500 mm
Info: 70 C116 UUID: [6579343a-d450-4ba5-8b44-6cb016f1ef98], X, Y: 258.9178 mm, 74.9522 mm, Rounded X, Y, 258.9200 mm, 74.9500 mm
Info: 71 C115 UUID: [f6b4802b-cd30-434d-941b-8088132ba7da], X, Y: 260.4078 mm, 74.9572 mm, Rounded X, Y, 260.4100 mm, 74.9600 mm
Info: 72 C59 UUID: [d16b239e-8706-46a0-9ecf-f607e7faf56c], X, Y: 242.0500 mm, 75.6543 mm, Rounded X, Y, 242.0500 mm, 75.6500 mm
Info: 73 C57 UUID: [30db28b3-50af-4e57-8044-facdff9db157], X, Y: 247.4000 mm, 75.6543 mm, Rounded X, Y, 247.4000 mm, 75.6500 mm
Info: 74 C60 UUID: [1aca5681-7aa6-4eae-8c99-50777c4894db], X, Y: 242.0500 mm, 77.2043 mm, Rounded X, Y, 242.0500 mm, 77.2000 mm
Info: 75 C55 UUID: [64789ba1-d945-4e19-bb37-73597674a88f], X, Y: 247.4000 mm, 77.2043 mm, Rounded X, Y, 247.4000 mm, 77.2000 mm
Info: 76 C32 UUID: [14a53fb3-99f8-489f-988a-c0d3d55cb28b], X, Y: 255.8478 mm, 77.9872 mm, Rounded X, Y, 255.8500 mm, 77.9900 mm
Info: 77 C36 UUID: [f15d8941-e5d2-4ee2-8736-35d1b2f31cb2], X, Y: 257.3878 mm, 77.9872 mm, Rounded X, Y, 257.3900 mm, 77.9900 mm
Info: 78 C82 UUID: [6ef30bfa-4d68-4507-b1f2-4bea123a0a5a], X, Y: 269.2950 mm, 79.6050 mm, Rounded X, Y, 269.2900 mm, 79.6000 mm
Info: 79 C84 UUID: [a446a4bd-c0df-4521-8cd9-9cb94f0fa056], X, Y: 270.8550 mm, 79.6050 mm, Rounded X, Y, 270.8500 mm, 79.6000 mm
Info: 80 C88 UUID: [8463b486-db9d-4652-a5f6-722ed7121eba], X, Y: 262.7550 mm, 81.7700 mm, Rounded X, Y, 262.7500 mm, 81.7700 mm
Info: 81 C80 UUID: [4c3c566b-5d3a-42f0-a0f5-fa1979fedb7f], X, Y: 269.2900 mm, 82.6750 mm, Rounded X, Y, 269.2900 mm, 82.6700 mm
Info: 82 C81 UUID: [2325ae8a-9804-4d09-ac61-9ae66fe9b83e], X, Y: 270.8650 mm, 82.6750 mm, Rounded X, Y, 270.8600 mm, 82.6700 mm
Info: 83 C89 UUID: [5f072146-6b82-489f-af77-0c9758aad44e], X, Y: 262.7550 mm, 83.3000 mm, Rounded X, Y, 262.7500 mm, 83.3000 mm
Info: 84 R51 UUID: [d3d52359-4704-4c2a-a3da-5151eeeac1fc], X, Y: 259.7250 mm, 84.8247 mm, Rounded X, Y, 259.7200 mm, 84.8200 mm
Info: 85 C90 UUID: [3f49c6aa-37d6-41fd-9675-601b58a2e473], X, Y: 262.7550 mm, 84.8250 mm, Rounded X, Y, 262.7500 mm, 84.8200 mm
Info: 86 C87 UUID: [cf0b5247-64ae-477a-9c4c-9681fd84ab8b], X, Y: 265.8150 mm, 84.8200 mm, Rounded X, Y, 265.8100 mm, 84.8200 mm
Info: 87 C79 UUID: [b17ae80e-a340-4fae-baa4-af3df43b9a92], X, Y: 269.2950 mm, 85.6650 mm, Rounded X, Y, 269.2900 mm, 85.6600 mm
Info: 88 C77 UUID: [9976fec7-33ce-4dee-8290-4d3804dd5e30], X, Y: 270.8550 mm, 85.6650 mm, Rounded X, Y, 270.8500 mm, 85.6600 mm
Info: 89 C86 UUID: [2b14adac-cca2-4896-8bab-3a1fc486090b], X, Y: 265.8150 mm, 86.3450 mm, Rounded X, Y, 265.8100 mm, 86.3400 mm
Info: 90 R50 UUID: [ddaad275-5139-407c-8e36-15cf66ac78c7], X, Y: 262.7550 mm, 86.3600 mm, Rounded X, Y, 262.7500 mm, 86.3600 mm
Info: 91 C67 UUID: [af6de374-1a94-4cad-b07a-19ae085d0789], X, Y: 251.9150 mm, 87.5800 mm, Rounded X, Y, 251.9100 mm, 87.5800 mm
Info: 92 C69 UUID: [b4d3db8c-66ea-4e6c-a40f-011e0b2b021a], X, Y: 256.6650 mm, 87.5900 mm, Rounded X, Y, 256.6600 mm, 87.5900 mm
Info: 93 C92 UUID: [71745492-fbdf-4764-ab22-c14f16e7d789], X, Y: 262.7550 mm, 87.8900 mm, Rounded X, Y, 262.7500 mm, 87.8900 mm
Info: 94 C91 UUID: [6105f66b-49cc-4e83-8855-35e84d62db66], X, Y: 262.7550 mm, 89.4150 mm, Rounded X, Y, 262.7500 mm, 89.4100 mm
Info: 95 D2 UUID: [32c6056e-b8fa-4c46-ad0c-09c0b4bb2de6], X, Y: 253.5350 mm, 90.2150 mm, Rounded X, Y, 253.5300 mm, 90.2100 mm
Info: 96 P13 UUID: [62fae5db-aefd-49f4-bd23-c8258f8de2a8], X, Y: 266.3600 mm, 98.6300 mm, Rounded X, Y, 266.3600 mm, 98.6300 mm
Info: 97 C62 UUID: [185e717d-cafc-477b-8a94-8dd03b893b98], X, Y: 246.0750 mm, 98.8200 mm, Rounded X, Y, 246.0700 mm, 98.8200 mm
Info: 98 C66 UUID: [f1c13122-72ec-47d0-977a-e001c914b5f8], X, Y: 246.0750 mm, 100.3200 mm, Rounded X, Y, 246.0700 mm, 100.3200 mm
Info: 99 R47 UUID: [da550156-2ca0-4ce6-aea6-e89b7600c8fc], X, Y: 252.2250 mm, 100.9500 mm, Rounded X, Y, 252.2200 mm, 100.9500 mm
Info: 100 C64 UUID: [eccbf476-4db6-4dc1-8ec3-eb56c41e9f74], X, Y: 246.0750 mm, 101.8100 mm, Rounded X, Y, 246.0700 mm, 101.8100 mm
Info: 101 R48 UUID: [9885ea21-53d6-4293-a125-4684aced693e], X, Y: 252.2250 mm, 102.5500 mm, Rounded X, Y, 252.2200 mm, 102.5500 mm
Info: 102 D5 UUID: [98af2c1c-b6a7-4149-bfdf-bf548e98e423], X, Y: 255.1750 mm, 102.5880 mm, Rounded X, Y, 255.1700 mm, 102.5900 mm
Info: 103 P11 UUID: [ca42bf9c-0096-433a-b851-e6986d406de4], X, Y: 261.3100 mm, 104.4900 mm, Rounded X, Y, 261.3100 mm, 104.4900 mm
Info: 104 U7 UUID: [5dc85c26-8c89-40e3-b50e-35482bcb433a], X, Y: 246.1000 mm, 105.1350 mm, Rounded X, Y, 246.1000 mm, 105.1300 mm
Info: 105 C72 UUID: [27181084-a42d-4a0a-8ead-00b229558e3c], X, Y: 246.0500 mm, 109.7200 mm, Rounded X, Y, 246.0500 mm, 109.7200 mm
Info: 106 P9 UUID: [deb69fe6-822d-45f4-accb-86c7bc72f6a5], X, Y: 266.7100 mm, 110.8200 mm, Rounded X, Y, 266.7100 mm, 110.8200 mm
Info: 107 C74 UUID: [0ea40afa-ad0b-4a97-8bed-5210c8e03f19], X, Y: 246.0500 mm, 111.2200 mm, Rounded X, Y, 246.0500 mm, 111.2200 mm
Info: 108 U21 UUID: [a3bf3566-6d82-4a3a-93da-8f83a1066455], X, Y: 191.5000 mm, 111.3000 mm, Rounded X, Y, 191.5000 mm, 111.3000 mm
Info: 109 U19 UUID: [9d45ff23-ab3f-461c-a7ae-58c53f71fe04], X, Y: 210.5000 mm, 111.3000 mm, Rounded X, Y, 210.5000 mm, 111.3000 mm
Info: 110 U17 UUID: [1e6228d2-9c68-47f6-a7cc-da82c1324c88], X, Y: 222.0000 mm, 111.3000 mm, Rounded X, Y, 222.0000 mm, 111.3000 mm
Info: 111 U15 UUID: [b2af789e-e071-4e79-97b3-14a5a62d7887], X, Y: 240.5000 mm, 111.3000 mm, Rounded X, Y, 240.5000 mm, 111.3000 mm
Info: 
Info: 
Info: There are 10 types of reference designations
Info: **********************************************************
Info: H P R S U C D G*** Q FB 
Info:     Change Array
Info: ***********************
Info: C1 -> C22   
Info: C2 -> C18   
Info: C3 -> C23   
Info: C4 -> C10   
Info: C5 -> C26   
Info: C6 -> C9   
Info: C7 -> C24   
Info: C8 -> C34   
Info: C9 -> C29   
Info: C10 -> C11   
Info: C11 -> C5   
Info: C12 -> C35   
Info: C13 -> C17   
Info: C14 -> C19   
Info: C15 -> C3   
Info: C16 -> C6   
Info: C17 -> C27   
Info: C18 -> C26   
Info: C19 -> C8   
Info: C20 -> C7   
Info: C21 -> C32   
Info: C22 -> C10   
Info: C23 -> C33   
Info: C24 -> C21   
Info: C25 -> C12   
Info: C26 -> C13   
Info: C27 -> C37   
Info: C28 -> C28   
Info: C29 -> C31   
Info: C30 -> C11   
Info: C31 -> C14   
Info: C32 -> C49   
Info: C33 -> C15   
Info: C34 -> C39   
Info: C35 -> C42   
Info: C36 -> C50   
Info: C37 -> C14   
Info: C38 -> C16   
Info: C39 -> C17   
Info: C40 -> C23   
Info: C41 -> C24   
Info: C42 -> C16   
Info: C43 -> C15   
Info: C44 -> C27   
Info: C45 -> C13   
Info: C46 -> C28   
Info: C47 -> C18   
Info: C48 -> C30   
Info: C49 -> C21   
Info: C50 -> C32   
Info: C51 -> C25   
Info: C52 -> C19   
Info: C53 -> C20   
Info: C54 -> C31   
Info: C55 -> C48   
Info: C56 -> C36   
Info: C57 -> C46   
Info: C58 -> C38   
Info: C59 -> C45   
Info: C60 -> C47   
Info: C61 -> C38   
Info: C62 -> C66   
Info: C63 -> C35   
Info: C64 -> C68   
Info: C65 -> C36   
Info: C66 -> C67   
Info: C67 -> C62   
Info: C68 -> C46   
Info: C69 -> C63   
Info: C70 -> C52   
Info: C71 -> C37   
Info: C72 -> C69   
Info: C73 -> C34   
Info: C74 -> C70   
Info: C75 -> C45   
Info: C76 -> C47   
Info: C77 -> C60   
Info: C78 -> C41   
Info: C79 -> C59   
Info: C80 -> C54   
Info: C81 -> C55   
Info: C82 -> C51   
Info: C83 -> C42   
Info: C84 -> C52   
Info: C85 -> C30   
Info: C86 -> C61   
Info: C87 -> C58   
Info: C88 -> C53   
Info: C89 -> C56   
Info: C90 -> C57   
Info: C91 -> C65   
Info: C92 -> C64   
Info: C93 -> C4   
Info: C94 -> C2   
Info: C95 -> C3   
Info: C96 -> C1   
Info: C97 -> C54   
Info: C98 -> C56   
Info: C99 -> C53   
Info: C100 -> C55   
Info: C101 -> C59   
Info: C102 -> C6   
Info: C103 -> C60   
Info: C104 -> C5   
Info: C105 -> C58   
Info: C106 -> C7   
Info: C107 -> C57   
Info: C108 -> C8   
Info: C109 -> C4   
Info: C110 -> C2   
Info: C111 -> C40   
Info: C112 -> C39   
Info: C113 -> C43   
Info: C114 -> C44   
Info: C115 -> C44   
Info: C116 -> C43   
Info: C117 -> C41   
Info: C118 -> C40   
Info: C119 -> C22   
Info: C120 -> C20   
Info: C121 -> C9   
Info: C122 -> C12   
Info: C123 -> C50   
Info: C124 -> C49   
Info: C125 -> C25   
Info: C126 -> C51   
Info: C127 -> C48   
Info: C128 -> C33   
Info: C129 -> C29   
Info: D1 -> D5   
Info: D2 -> D3   
Info: D3 -> D4   
Info: D4 -> D2   
Info: D5 -> D4   
Info: D6 -> D2   
Info: D7 -> D1   
Info: D8 -> D3   
Info: FB1 -> FB1   
Info: G*** -> G***2   
Info: G*** -> G***1   
Info: H1 -> H1  Excluded  will be ignored
Info: H2 -> H2  Excluded  will be ignored
Info: H3 -> H3  Excluded  will be ignored
Info: H4 -> H4  Excluded  will be ignored
Info: P1 -> P1  Excluded  will be ignored
Info: P2 -> P2  Excluded  will be ignored
Info: P3 -> P3  Excluded  will be ignored
Info: P4 -> P4  Excluded  will be ignored
Info: P5 -> P5  Excluded  will be ignored
Info: P6 -> P6  Excluded  will be ignored
Info: P7 -> P7  Excluded  will be ignored
Info: P8 -> P8  Excluded  will be ignored
Info: P9 -> P9  Excluded  will be ignored
Info: P10 -> P10   
Info: P11 -> P11  Excluded  will be ignored
Info: P12 -> P12  Excluded  will be ignored
Info: P13 -> P13  Excluded  will be ignored
Info: P14 -> P14   
Info: P15 -> P15   
Info: Q1 -> Q3   
Info: Q2 -> Q2   
Info: Q3 -> Q1   
Info: Q4 -> Q2   
Info: R1 -> R3   
Info: R2 -> R2   
Info: R3 -> R19   
Info: R4 -> R16   
Info: R5 -> R4   
Info: R6 -> R5   
Info: R7 -> R7   
Info: R8 -> R6   
Info: R9 -> R9   
Info: R10 -> R16   
Info: R11 -> R15   
Info: R12 -> R8   
Info: R13 -> R17   
Info: R14 -> R18   
Info: R15 -> R9   
Info: R16 -> R34   
Info: R17 -> R33   
Info: R18 -> R32   
Info: R19 -> R35   
Info: R20 -> R10   
Info: R21 -> R11   
Info: R22 -> R13   
Info: R23 -> R12   
Info: R24 -> R13   
Info: R25 -> R14   
Info: R26 -> R10   
Info: R27 -> R11   
Info: R28 -> R20   
Info: R29 -> R21   
Info: R30 -> R15   
Info: R31 -> R14   
Info: R32 -> R30   
Info: R33 -> R26   
Info: R34 -> R18   
Info: R35 -> R17   
Info: R37 -> R29   
Info: R38 -> R31   
Info: R41 -> R42   
Info: R42 -> R41   
Info: R43 -> R50   
Info: R44 -> R48   
Info: R45 -> R45   
Info: R46 -> R49   
Info: R47 -> R21   
Info: R48 -> R22   
Info: R49 -> R5   
Info: R50 -> R20   
Info: R51 -> R19   
Info: R52 -> R40   
Info: R53 -> R39   
Info: R54 -> R6   
Info: R55 -> R7   
Info: R56 -> R8   
Info: R57 -> R2   
Info: R58 -> R3   
Info: R59 -> R4   
Info: R60 -> R44   
Info: R61 -> R36   
Info: R62 -> R47   
Info: R63 -> R12   
Info: R64 -> R25   
Info: R65 -> R22   
Info: R66 -> R23   
Info: R67 -> R24   
Info: R68 -> R46   
Info: R69 -> R37   
Info: R70 -> R27   
Info: R71 -> R28   
Info: R72 -> R38   
Info: R73 -> R43   
Info: R74 -> R74  Excluded  will be ignored
Info: R75 -> R75  Excluded  will be ignored
Info: S1 -> S1  Excluded  will be ignored
Info: U1 -> U4   
Info: U2 -> U2   
Info: U3 -> U5   
Info: U4 -> U3   
Info: U5 -> U6   
Info: U6 -> U13   
Info: U7 -> U4   
Info: U8 -> U17   
Info: U9 -> U9   
Info: U10 -> U12   
Info: U11 -> U10   
Info: U12 -> U11   
Error: Duplicate instances of C22
Error: Duplicate instances of C18
Error: Duplicate instances of C23
Error: Duplicate instances of C10
Error: Duplicate instances of C26
Error: Duplicate instances of C9
Error: Duplicate instances of C24
Error: Duplicate instances of C34
Error: Duplicate instances of C29
Error: Duplicate instances of C11
Error: Duplicate instances of C5
Error: Selected options resulted in errors! Change them and try again.
Error: Duplicate instances of C22
Error: Duplicate instances of C18
Error: Duplicate instances of C23
Error: Duplicate instances of C10
Error: Duplicate instances of C26
Error: Duplicate instances of C9
Error: Duplicate instances of C24
Error: Duplicate instances of C34
Error: Duplicate instances of C29
Error: Duplicate instances of C11
Error: Duplicate instances of C5
Error: Selected options resulted in errors! Change them and try again.

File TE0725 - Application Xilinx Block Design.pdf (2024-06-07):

axi_iic_0 AXI IIC S_AXI IIC s_axi_aclk s_axi_aresetn iic2intc_irpt gpo[0:0] axi_quad_spi_0 AXI Quad SPI SPI_0 STARTUP_IO AXI_LITE ext_spi_clk s_axi_aclk s_axi_aresetn ip2intc_irpt axi_quad_spi_1 AXI Quad SPI SPI_0 io0_i io1_o sck_i spisel AXI_LITE ext_spi_clk s_axi_aclk s_axi_aresetn ip2intc_irpt axi_timer_0 AXI Timer S_AXI capturetrig0 capturetrig1 generateout0 generateout1 pwm0 interrupt freeze s_axi_aclk s_axi_aresetn axi_uartlite_0 AXI Uartlite S_AXI UART s_axi_aclk s_axi_aresetn interrupt clk_wiz_0 reset clk_in1 Clocking Wizard clk_out1 clk_out2 locked iic_main extra_io[2:0] i2s_receiver_0 I2S Receiver s_axi_ctrl m_axis_aud s_axi_ctrl_aclk s_axi_ctrl_aresetn aud_mclk aud_mrst m_axis_aud_aclk m_axis_aud_aresetn irq lrclk_in sclk_in sdata_0_in mdm_1 MicroBlaze Debug Module (MDM) MBDEBUG_0 Debug_SYS_Rst microblaze_0 MicroBlaze INTERRUPT DLMB ILMB M_AXI_DP DEBUG Clk Reset microblaze_0_axi_intc AXI Interrupt Controller s_axi interrupt s_axi_aclk s_axi_aresetn intr[5:0] processor_clk processor_rst microblaze_0_axi_periph AXI Interconnect S00_AXI M00_AXI M01_AXI M02_AXI M03_AXI M04_AXI M05_AXI M06_AXI M07_AXI ACLK ARESETN S00_ACLK S00_ARESETN M00_ACLK M00_ARESETN M01_ACLK M01_ARESETN M02_ACLK M02_ARESETN M03_ACLK M03_ARESETN M04_ACLK M04_ARESETN M05_ACLK M05_ARESETN M06_ACLK M06_ARESETN M07_ACLK M07_ARESETN microblaze_0_local_memory DLMB ILMB LMB_Clk SYS_Rst microblaze_0_xlconcat Concat In0[0:0] In1[0:0] In2[0:0] In3[0:0] In4[0:0] In5[0:0] dout[5:0] esp32_miso cs esp32_mosi esp32_sck esp32_ss ext_rst_esp heartbeat_led i2s_scl i2s_sda i2s_ws pwm_fan pwm_buff_en reset scl sdi sdoa sdob sys_clock pwm_out[1:64] tx_active_led rst_clk_wiz_0_100M Processor System Reset slowest_sync_clk ext_reset_in aux_reset_in mb_debug_sys_rst dcm_locked mb_reset bus_struct_reset[0:0] peripheral_reset[0:0] interconnect_aresetn[0:0] peripheral_aresetn[0:0] serial_adc_pwm_top_0 serial_adc_pwm_top_v1_0 s_axi s_axi_aclk clk_serial s_axi_aresetn sdoa sdob cs scl sdi pwm_fan pwm_buff_en pwm_out[1:64] heartbeat_led tx_active_led extra_io[2:0] uart spi_flash

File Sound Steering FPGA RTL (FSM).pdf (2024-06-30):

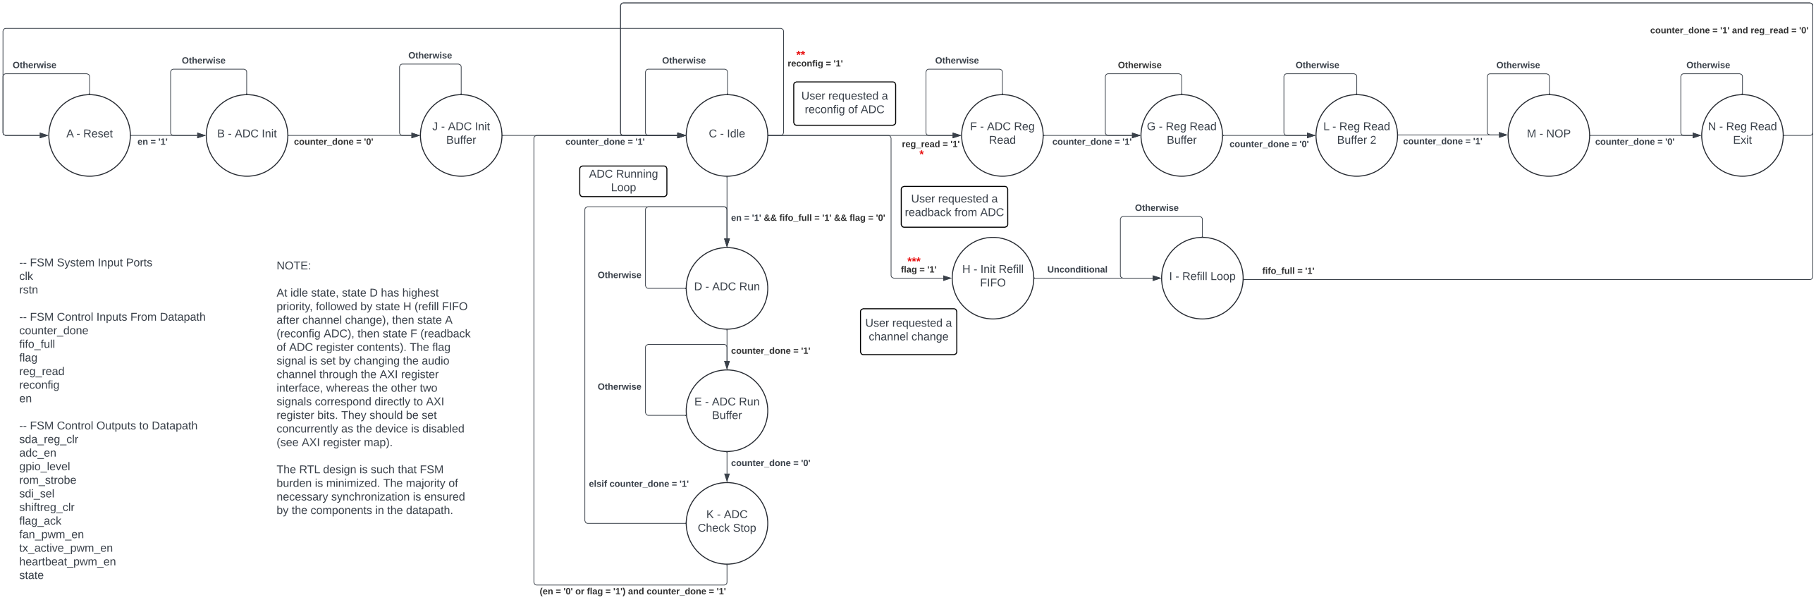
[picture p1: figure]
A - Reset; B - ADC Init; C - Idle; Otherwise Otherwise; Otherwise; reg_read = '1'; F - ADC Reg Read; D - ADC Run; G - Reg Read Buffer; counter_done = '1'; E - ADC Run Buffer; reconfig = '1'; NOTE:; At idle state, state D has highest; after channel change), then state A (reconfig ADC), then state F (readback of ADC register contents). The flag signal is set by changing the audio channel through the AXI register interface, whereas the other two signals correspond directly to AXI register bits. They should be set concurrently as the device is disabled (see AXI register map).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

en = '1' && fifo_full = '1' && flag = '0'

priority, followed by state H (refill FIFO

(en = '0' or flag = '1') and counter_done = '1'

### Sound Steering FPGA RTL (FSM)

Kevin Harper | June 1, 2024

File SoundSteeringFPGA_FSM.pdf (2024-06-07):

A - Reset | en = '1' | B - ADC Init | C - Idle
Otherwise Otherwise | Otherwise

reg_read = '1' F - ADC Reg Read

Otherwise

en = '1' && fifo_full = '1' && flag = '0'

D - ADC Run

G - Reg Read Buffer

Otherwise

counter_done = '1'

E - ADC Run Buffer

Otherwise

reconfig = '1'

Otherwise

counter_done = '1'

NOTE: At idle state, state D has highest priority, followed by state H (refill FIFO

after channel change), then state A (reconfig ADC), then state F (readback of ADC register contents). The flag

signal is set by changing the audio channel through the AXI register interface, whereas the other two signals correspond directly to AXI register bits. They should be set concurrently as the device is disabled

(see AXI register map).

The RTL design is such that FSM burden is minimized. The majority of necessary synchronization is ensured

by the components in the datapath.

flag = '1' H - Init Refill FIFO

User requested a
channel change
J - ADC Init counter_done = '0' | Buffer | counter_done = '1'

Otherwise

K - ADC
Check Stop

(en = '0' or flag = '1') and counter_done = '1'

elsif counter_done = '1'

counter_done = '0'

I - Refill Loop Unconditional

Otherwise

fifo_full = '1'

L - Reg Read Buffer 2 | M - NOP | N - Reg Read Exit counter_done = '0'

Otherwise

counter_done = '1'

Otherwise

counter_done = '0'

counter_done = '1' and reg_read = '0'

Otherwise

User requested a
readback from ADC

User requested a
reconfig of ADC

***

*

**

ADC Running
Loop

# Sound Steering AXI-Lite RTL Peripheral FSM

-- FSM System Input Ports
clk
rstn

-- FSM Control Inputs From Datapath counter_done
fifo_full
flag
reg_read
reconfig
en

-- FSM Control Outputs to Datapath sda_reg_clr adc_en

gpio_level rom_strobe

sdi_sel shiftreg_clr

flag_ack
fan_pwm_en
tx_active_pwm_en
heartbeat_pwm_en
state

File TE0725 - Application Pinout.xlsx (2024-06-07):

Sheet: Overview, Notes & Disclaimer
 |  |  |  | Pinout Planner and Trace length for 3.5x7.3 Series
 |  |  |  | Version v2.6.3
Carrier / Module Combination:
 |  |  |  |  | Select Module:
 |  |  |  |  | TE0725_REV03
 |  |  |  | Depending on your Office Setup
 |  |  |  | Press: STRG + Shift +F9 (LibreOffice)
 |  |  |  | Press: F9 (Microsoft Office)
 |  |  | to update table after selection
Notes:
 | 1. Published by Trenz Electronic GmbH, Holzweg 19A, 32257 Bünde, Germany.
 | 2. Document modification date: | 2019-08-22
 | 3. Detailed information’s of modules and carrier boards are available on the Trenz Electronic Wiki
 | 4. Trace length are only PCB length without devices packages and connector length
Disclaimers:
 | 1. All pinouts and pin information is provided as-is without assurance of correctness or completeness.
 | 2. All information is subject to change at any time without notice.
 | 3.Please verify all data with user manuals, FPGA and other components vendor's documentation.
Supported Software:
 | 1. Microsoft Office Excel (tested with Office 2019 on Win10 OS)
 | 2. LibreOffice Calc (tested with LibreOffice 6.2.3.2 (X64) on Win10 OS)

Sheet: Module Pin Table
Use overview sheet to select carrier and module
 | TE0725_REV03
Index | Conn Pin name | Desig. | Pin | intermediate | Module Net Name | # netname | FPGA Pin | others | M. Trace Length (mm)
1 | GND | J1 | 1 | --- | GND | 188 | --- | --- | ---
2 | GND | J1 | 2 | --- | GND | 188 | --- | --- | ---
3 | IO | J1 | 3 | --- | B35_L23_N | 2 | K1 | --- | 35.7327
4 | IO | J1 | 4 | --- | B35_L23_P | 2 | K2 | --- | 36.6321
5 | VCC | J1 | 5 | --- | 3.3V | 57 | --- | --- | ---
6 | VCC | J1 | 6 | --- | VCCIO35 | 16 | --- | --- | ---
7 | IO | J1 | 7 | --- | B35_L15_N | 2 | G2 | --- | 33.2423
8 | IO | J1 | 8 | --- | B35_L15_P | 2 | H2 | --- | 33.2423
9 | IO | J1 | 9 | --- | B35_L13_N | 2 | F3 | --- | 31.7862
10 | IO | J1 | 10 | --- | B35_L13_P | 2 | F4 | --- | 32.8214
11 | IO | J1 | 11 | --- | B35_L12_N | 2 | D3 | --- | 28.8848
12 | IO | J1 | 12 | --- | B35_L12_P | 2 | E3 | --- | 28.9374
13 | IO | J1 | 13 | --- | B35_L22_P | 2 | J3 | --- | 24.3505
14 | IO | J1 | 14 | --- | B35_L22_N | 2 | J2 | --- | 24.0032
15 | IO | J1 | 15 | --- | B35_L17_N | 2 | G1 | --- | 19.8156
16 | IO | J1 | 16 | --- | B35_L17_P | 2 | H1 | --- | 19.8156
17 | IO | J1 | 17 | --- | B35_L18_N | 2 | E1 | --- | 17.2377
18 | IO | J1 | 18 | --- | B35_L18_P | 2 | F1 | --- | 17.4862
19 | IO | J1 | 19 | --- | B35_L14_N | 2 | D2 | --- | 15.3667
20 | IO | J1 | 20 | --- | B35_L14_P | 2 | E2 | --- | 15.7195
21 | IO | J1 | 21 | --- | B35_L16_P | 2 | C2 | --- | 12.9746
22 | IO | J1 | 22 | --- | B35_L16_N | 2 | C1 | --- | 12.755
23 | IO | J1 | 23 | --- | B35_L9_N | 2 | A1 | --- | 9.9248
24 | IO | J1 | 24 | --- | B35_L9_P | 2 | B1 | --- | 10.4762
25 | IO | J1 | 25 | --- | B35_L10_P | 2 | B3 | --- | 10.9407
26 | IO | J1 | 26 | --- | B35_L10_N | 2 | B2 | --- | 10.8562
27 | IO | J1 | 27 | --- | B35_L8_N | 2 | A3 | --- | 9.7786
28 | IO | J1 | 28 | --- | B35_L8_P | 2 | A4 | --- | 9.6853
29 | IO | J1 | 29 | --- | B35_L11_N | 2 | D4 | --- | 16.82
30 | IO | J1 | 30 | --- | B35_L11_P | 2 | D5 | --- | 16.0985
31 | IO | J1 | 31 | --- | B35_L3_N | 2 | A5 | --- | 11.2399
32 | IO | J1 | 32 | --- | B35_L3_P | 2 | A6 | --- | 11.157
33 | IO | J1 | 33 | --- | B35_L2_N | 2 | B6 | --- | 13.665
34 | IO | J1 | 34 | --- | B35_L2_P | 2 | B7 | --- | 13.3926
35 | IO | J1 | 35 | --- | B35_L7_N | 2 | B4 | --- | 19.3525
36 | IO | J1 | 36 | --- | B35_L7_P | 3 | C4 | --- | 35.9472
37 | IO | J1 | 37 | --- | B35_L1_N | 2 | C5 | --- | 22.193
38 | IO | J1 | 38 | --- | B35_L1_P | 2 | C6 | --- | 21.7488
39 | IO | J1 | 39 | --- | B35_L5_N | 2 | E5 | --- | 27.1261
40 | IO | J1 | 40 | --- | B35_L5_P | 2 | E6 | --- | 26.7066
41 | IO | J1 | 41 | --- | B35_L6_N | 2 | D7 | --- | 26.9566
42 | IO | J1 | 42 | --- | B35_L6_P | 2 | E7 | --- | 26.1406
43 | IO | J1 | 43 | --- | B35_L19_P | 2 | G6 | --- | 33.1997
44 | IO | J1 | 44 | --- | B35_L19_N | 2 | F6 | --- | 33.0684
45 | VCC | J1 | 45 | --- | VCCIO35 | 16 | --- | --- | ---
46 | VCC | J1 | 46 | --- | 3.3V | 57 | --- | --- | ---
47 | IO | J1 | 47 | --- | B35_L4_N | 2 | C7 | --- | 31.9514
48 | IO | J1 | 48 | --- | B35_L4_P | 2 | D8 | --- | 31.7141
49 | GND | J1 | 49 | --- | GND | 188 | --- | --- | ---
50 | GND | J1 | 50 | --- | GND | 188 | --- | --- | ---
51 | GND | J2 | 1 | --- | GND | 188 | --- | --- | ---
52 | GND | J2 | 2 | --- | GND | 188 | --- | --- | ---
53 | IO | J2 | 3 | --- | B34_L24_N | 2 | T8 | --- | 21.1968
54 | IO | J2 | 4 | --- | B34_L24_P | 2 | R8 | --- | 21.6353
55 | VCC | J2 | 5 | --- | 3.3V | 57 | --- | --- | ---
56 | VCC | J2 | 6 | --- | VCCIO34 | 16 | --- | --- | ---
57 | IO | J2 | 7 | --- | B34_L21_N | 2 | V9 | --- | 14.7225
58 | IO | J2 | 8 | --- | B34_L21_P | 2 | U9 | --- | 15.5412
59 | IO | J2 | 9 | --- | B34_L18_N | 2 | N6 | --- | 20.7321
60 | IO | J2 | 10 | --- | B34_L18_P | 2 | M6 | --- | 19.2802
61 | IO | J2 | 11 | --- | B34_L22_N | 2 | U6 | --- | 14.2754
62 | IO | J2 | 12 | --- | B34_L22_P | 2 | U7 | --- | 10.0872
63 | IO | J2 | 13 | --- | B34_L20_N | 2 | V6 | --- | 11.4403
64 | IO | J2 | 14 | --- | B34_L20_P | 2 | V7 | --- | 7.2984
65 | IO | J2 | 15 | --- | B34_L23_N | 2 | T6 | --- | 11.5077
66 | IO | J2 | 16 | --- | B34_L23_P | 2 | R7 | --- | 19.6994
67 | IO | J2 | 17 | --- | B34_L10_N | 2 | V4 | --- | 8.6226
68 | IO | J2 | 18 | --- | B34_L10_P | 2 | V5 | --- | 6.095
69 | IO | J2 | 19 | --- | B34_L19_P | 2 | R6 | --- | 13.6272
70 | IO | J2 | 20 | --- | B34_L19_N | 2 | R5 | --- | 13.5235
71 | IO | J2 | 21 | --- | B34_L8_P | 2 | U4 | --- | 10.5352
72 | IO | J2 | 22 | --- | B34_L8_N | 2 | U3 | --- | 8.248
73 | IO | J2 | 23 | --- | B34_L9_N | 2 | V2 | --- | 10.1245
74 | IO | J2 | 24 | --- | B34_L9_P | 2 | U2 | --- | 8.935
75 | IO | J2 | 25 | --- | B34_L7_N | 2 | V1 | --- | 11.0309
76 | IO | J2 | 26 | --- | B34_L7_P | 2 | U1 | --- | 9.4581
77 | IO | J2 | 27 | --- | B34_L13_P | 2 | N5 | --- | 24.5189
78 | IO | J2 | 28 | --- | B34_L13_N | 2 | P5 | --- | 22.9635
79 | IO | J2 | 29 | --- | B34_L12_P | 2 | T5 | --- | 23.5868
80 | IO | J2 | 30 | --- | B34_L12_N | 2 | T4 | --- | 20.7418
81 | IO | J2 | 31 | --- | B34_L11_N | 2 | T3 | --- | 23.0921
82 | IO | J2 | 32 | --- | B34_L11_P | 2 | R3 | --- | 21.8751
83 | IO | J2 | 33 | --- | B34_L14_P | 2 | P4 | --- | 27.6209
84 | IO | J2 | 34 | --- | B34_L14_N | 2 | P3 | --- | 25.149
85 | IO | J2 | 35 | --- | B34_L16_N | 2 | N4 | --- | 30.7389
86 | IO | J2 | 36 | --- | B34_L16_P | 2 | M4 | --- | 29.6831
87 | IO | J2 | 37 | --- | B34_L17_N | 2 | T1 | --- | 26.9221
88 | IO | J2 | 38 | --- | B34_L17_P | 2 | R1 | --- | 27.1847
89 | IO | J2 | 39 | --- | B34_L15_N | 2 | R2 | --- | 31.6098
90 | IO | J2 | 40 | --- | B34_L15_P | 2 | P2 | --- | 30.5084
91 | IO | J2 | 41 | --- | B34_L3_N | 2 | N1 | --- | 34.1156
92 | IO | J2 | 42 | --- | B34_L3_P | 2 | N2 | --- | 33.4589
93 | IO | J2 | 43 | --- | B34_L1_N | 2 | M1 | --- | 36.7347
94 | IO | J2 | 44 | --- | B34_L1_P | 2 | L1 | --- | 35.4857
95 | VCC | J2 | 45 | --- | VCCIO34 | 16 | --- | --- | ---
96 | VCC | J2 | 46 | --- | 3.3V | 57 | --- | --- | ---
97 | IO | J2 | 47 | --- | B34_L4_P | 2 | M3 | --- | 45.8289
98 | IO | J2 | 48 | --- | B34_L4_N | 2 | M2 | --- | 45.261
99 | GND | J2 | 49 | --- | GND | 188 | --- | --- | ---
100 | GND | J2 | 50 | --- | GND | 188 | --- | --- | ---
101 | GND | JB1 | 1 | --- | GND | 188 | --- | --- | ---
102 | GND | JB1 | 2 | --- | GND | 188 | --- | --- | ---
103 | JTAG/UART | JB1 | 3 | --- | UART_RXD | 2 | M18 | --- | 17.9437
104 | JTAG/UART | JB1 | 4 | --- | F_TCK | 2 | E10 | --- | 29.0918
105 | VCC | JB1 | 5 | --- | 3.3V | 57 | --- | --- | ---
106 | VCC | JB1 | 6 | --- | 3.3V | 57 | --- | --- | ---
107 | JTAG/UART | JB1 | 7 | --- | UART_TXD | 2 | L18 | --- | 18.4656
108 | JTAG/UART | JB1 | 8 | --- | F_TDO | 2 | E13 | --- | 23.8251
109 | JTAG/UART | JB1 | 9 | --- | XMOD_E | 2 | M17 | --- | 21.2142
110 | JTAG/UART | JB1 | 10 | --- | F_TDI | 2 | E11 | --- | 26.427
111 | JTAG/UART | JB1 | 11 | --- | nRST | 3 | -- | U9-3 | 9.2202
112 | JTAG/UART | JB1 | 12 | --- | F_TMS | 2 | E12 | --- | 24.9618
113 | GND | JB1 | H1 | --- | GND | 188 | --- | --- | ---
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

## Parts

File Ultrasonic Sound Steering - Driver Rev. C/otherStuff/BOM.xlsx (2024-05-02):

Description | Manufacturer/Supplier | Min. quantity | Safe quantity | Package | MFR P/N | Unit Price |  | Link | Operating Voltage | Datasheet
10mm 40kHz ultrasonic transducer | Manorshi | 64 | 72 | Plastic 10mm radial TH | MA40S4S | 4.04 | $/50 | https://www.mouser.com/ProductDetail/Murata-Electronics/MA40S4S?qs=dyqxRLCA4pZUsZeqTN%2FO6A%3D%3D | ~18V | https://www.mouser.com/datasheet/2/281/MA40S4S-792899.pdf | 290.88
Dual channel noninverting low side gate driver IC | Microchip | 32 | 40 | MSOP8 | MIC4127YMME-TR | 1.01 | $/25 | https://www.mouser.com/ProductDetail/Microchip-Technology/MIC4127YMME-TR?qs=U6T8BxXiZAWcUTMWGiO%252Buw%3D%3D | ~18V | https://www.mouser.com/datasheet/2/268/MIC4126_27_28_Data_Sheet_20006084A-1891221.pdf | 40.4
0.1uF ceramic SMD 25VDC X7R | Kyocera AVX | 32 | 40 | 0603 | KGM15BR71E104KT | 0.02 | $/10 | https://www.mouser.com/ProductDetail/KYOCERA-AVX/KGM15BR71E104KT?qs=Jm2GQyTW%2FbiCo%2Fby4Q068Q%3D%3D | ~18V | https://www.mouser.com/datasheet/2/40/KGM_X7R-3223212.pdf | 0.88
4.7uF MLCC SMD 25VDC X5R | Murata | 32 | 40 | 0603 | GRT188R6YA475KE13J | 0.14 | $/10 | https://www.mouser.com/ProductDetail/Murata-Electronics/GRT188R6YA475KE13J?qs=d0WKAl%252BL4Kb75CCCaGtx8w%3D%3D | ~18V | https://www.mouser.com/datasheet/2/281/1/GRT188R6YA475KE13_01A-3158664.pdf | 5.56
TE Shrouded Vert 2.54mm pitch | TE | 16 | 20 | N/A | 2-644861-8 | 0.48 | $/10 | https://www.mouser.com/ProductDetail/TE-Connectivity-AMP/2-644861-8?qs=vsOZ4Z0PtMfz2oLZnOXmcA%3D%3D | x | https://www.te.com/usa-en/product-2-644861-8.datasheet.pdf | 9.64
TE Mating Conn 24AWG IDC feed thru w/ locking ramp | TE | 16 | 20 | 1X8POS 2.54MM | 3-640621-8 | 0.47 | $/10 | https://www.mouser.com/ProductDetail/TE-Connectivity-AMP/3-640621-8?qs=Z9rit7M%252B%252BOioUdyKCb966w%3D%3D | x | https://www.te.com/usa-en/product-3-640621-8.datasheet.pdf | 9.48
8P 50ft flat IDC Conductor 24AWG roll | Unknown | 1 | 1 | N/A | N/A | 9.99 | $/1 | https://www.amazon.com/Pc-Accessories-Length-Conductors-Connectors/dp/B00E9P0F34 | x | N/A | 9.99
8 ohm 1W speaker 3'' | Adafruit | 1 | 2 | N/A | ADA1313 | 6.99 | $/1 | https://www.amazon.com/Adafruit-Speaker-Diameter-Watt-ADA1313/dp/B00XW2NPTG | x | https://www.adafruit.com/product/1313#technical-details | 13.98
MAX98537 Class D 3W Mono Audio Amp for I2S | Unknown | 1 | 1 | N/A | ADA3006 | 6.99 | $/2 | https://www.amazon.com/DAOKI-Amplifier-Filterless-Amplifiers-Raspberry/dp/B08SLPRYPJ | 3v3 | https://learn.adafruit.com/adafruit-max98357-i2s-class-d-mono-amp/downloads | 6.99
FPGA programmer | Altera | 1 | 1 | N/A | USB Blaster | 24.99 | $/1 | https://www.waveshare.com/usb-blaster.htm | x | N/A | 24.99
FPGA | Altera | 1 | 1 | Custom | EP4CE6-C | 39.99 | $/1 | https://www.waveshare.com/coreep4ce6.htm | 3v3 | https://www.alldatasheet.com/datasheet-pdf/pdf/580153/ALTERA/EP4CE6.html | 39.99
Board fab cost | PCBWay | 1 | 1 | N/A | N/A | 31.10 | $/5 | www.pcbway.com | x | N/A | 31.1
 |  |  |  |  |  | 91.76 for 16mm transducer brd
Min. Total: | 384.982
Safe Total: | 431.378
Tax + shipping fudge | 30
Total total: | 461.378
alt
ALT. for above | Alibaba | Manorshi | 10mm radial | https://www.alibaba.com/product-detail/MANORSHI-10mm-40kHz-ultrasonic-sensor-transmitter_60757880811.html | 0.6 | $/72 | 72 | 43.2 | Long lead times with standard delivery. Minimum order quantity is 72!

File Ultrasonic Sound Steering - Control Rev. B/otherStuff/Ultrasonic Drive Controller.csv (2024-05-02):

Component Count: | 270
Ref | Qnty | Value | Cmp name | Footprint | Description | Vendor
C1, C35, C36, C51, C52, C128, | 6 | 10uF | C_Polarized_US | Capacitor_Tantalum_SMD:CP_EIA-3216-18_Kemet-A | Polarized capacitor, US symbol
C2, C3, | 2 | 68nF | C | Capacitor_SMD:C_0603_1608Metric | Unpolarized capacitor
C4, C12, C17, C56, C62, C65, C92, C95, C96, C103, C111, C112, C114, C115, C133, C134, | 16 | 10uF | C | Capacitor_SMD:C_0603_1608Metric | Unpolarized capacitor
C5, C7, C26, C27, C30, C31, | 6 | 6.8uF | C | Capacitor_SMD:C_0603_1608Metric | Unpolarized capacitor
C6, C8, C16, C28, C32, C40, C41, C42, C45, C49, C50, C57, C58, C61, C63, C64, C66, C76, C86, C89, C90, C91, C93, C94, C97, C98, C99, C101, C104, C105, C106, C109, C110, C113, C116, C117, C118, C120, C122, C123, C125, C129, C131, C132, C135, | 45 | 100nF | C | Capacitor_SMD:C_0603_1608Metric | Unpolarized capacitor
C9, C25, C29, C39, C43, C77, C78, | 7 | 10nF | C | Capacitor_SMD:C_0603_1608Metric | Unpolarized capacitor
C10, C11, | 2 | 100pF | C | Capacitor_SMD:C_0603_1608Metric | Unpolarized capacitor
C13, | 1 | 1nF | C | Capacitor_SMD:C_0603_1608Metric | Unpolarized capacitor
C14, C15, | 2 | 680nF | C | Capacitor_SMD:C_0603_1608Metric | Unpolarized capacitor
C18, | 1 | 680pF | C | Capacitor_SMD:C_0603_1608Metric | Unpolarized capacitor
C19, C20, | 2 | 1.5nF | C | Capacitor_SMD:C_0603_1608Metric | Unpolarized capacitor
C21, C22, C23, C24, C33, C34, | 6 | 470pF | C | Capacitor_SMD:C_0603_1608Metric | Unpolarized capacitor
C37, C38, | 2 | 150pF | C | Capacitor_SMD:C_0603_1608Metric | Unpolarized capacitor
C44, C48, | 2 | 330pF | C | Capacitor_SMD:C_0603_1608Metric | Unpolarized capacitor
C46, C47, C53, C54, | 4 | 68pF | C | Capacitor_SMD:C_0603_1608Metric | Unpolarized capacitor
C55, C59, C60, C73, C74, C85, | 6 | 1uF | C | Capacitor_SMD:C_0603_1608Metric | Unpolarized capacitor
C67, C68, | 2 | 47uF | C_Polarized_US | Capacitor_Tantalum_SMD:CP_EIA-3528-21_Kemet-B | Polarized capacitor, US symbol
C69, C70, C71, C72, C100, C102, C107, C108, C119, C121, C124, C126, C127, C130, | 14 | 22uF | C | Capacitor_SMD:C_0603_1608Metric | Unpolarized capacitor
C75, | 1 | 47nF | C | Capacitor_SMD:C_0603_1608Metric | Unpolarized capacitor
C79, C87, | 2 | 100uF | C_Polarized_US | Capacitor_Tantalum_SMD:CP_EIA-3528-21_Kemet-B | Polarized capacitor, US symbol
C80, C81, C82, C83, C84, C88, | 6 | 47uF | C | Capacitor_SMD:C_0603_1608Metric | Unpolarized capacitor
D1, D2, D4, | 3 | MBR0520L | D_Schottky | Diode_SMD:D_SOD-123 | Schottky diode
D3, D8, D9, | 3 | LED | LED | LED_SMD:LED_1206_3216Metric_Pad1.42x1.75mm_HandSolder | Light emitting diode
D5, D6, D7, | 3 | LESD5D5.0CT1G | D_TVS | Diode_SMD:D_SOD-523 | Bidirectional transient-voltage-suppression diode
P1, P2, P3, P4, P5, P6, P7, P8, | 8 | Conn_02x08_Odd_Even | Conn_02x08_Odd_Even | Connector_PinSocket_2.54mm:PinSocket_2x08_P2.54mm_Vertical | Generic connector, double row, 02x08, odd/even pin numbering scheme (row 1 odd numbers, row 2 even numbers), script generated (kicad-library-utils/schlib/autogen/connector/)
P9, | 1 | SJ1-3524NG | SJ1-3524NG | SJ1-3524NG:CUI_SJ1-3524NG
P10, | 1 | Conn_02x04 | Conn_02x04_Odd_Even | Connector_PinSocket_2.54mm:PinSocket_2x04_P2.54mm_Vertical | Generic connector, double row, 02x04, odd/even pin numbering scheme (row 1 odd numbers, row 2 even numbers), script generated (kicad-library-utils/schlib/autogen/connector/)
P11, | 1 | SJ1-42516 | SJ1-42516_1 | SJ1-42516:CUI_SJ1-42516
P12, | 1 | PJ-051BH | PJ-051BH | PJ-051BH:CUI_PJ-051BH
P13, | 1 | USB_Micro-B_Molex-105017 | USB_B_Micro | Connector_USB:USB_Micro-B_Molex-105017-0001 | USB Micro Type B connector
P14, | 1 | Molex 1053131103 | Conn_01x03 | footprints18:CON_1053131103 | Generic connector, single row, 01x03, script generated (kicad-library-utils/schlib/autogen/connector/)
Q1, Q2, Q3, Q4, | 4 | DMN65D8L | DMN65D8L | footprints12:DMP3099L-7_DIO | 0.115A Id, 60V Vds, N-Channel MOSFET, SOT-23
R1, R2, R4, R7, R9, R44, R45, R77, | 8 | 100kohm | R_US | Resistor_SMD:R_0603_1608Metric | Resistor, US symbol
R3, R57, R58, R59, R72, R73, R74, R75, R80, R81, R82, R83, R84, R85, R86, | 15 | 0ohm | R_US | Resistor_SMD:R_0603_1608Metric | Resistor, US symbol
R5, R6, R27, R28, R29, R30, R31, R32, R33, R34, R40, R52, R62, R63, | 14 | 1kohm | R_US | Resistor_SMD:R_0603_1608Metric | Resistor, US symbol
R8, | 1 | 68ohm | R_US | Resistor_SMD:R_0603_1608Metric | Resistor, US symbol
R10, R11, | 2 | 2kohm | R_US | Resistor_SMD:R_0603_1608Metric | Resistor, US symbol
R12, | 1 | 1.2kohm | R_US | Resistor_SMD:R_0603_1608Metric | Resistor, US symbol
R13, R14, R53, R54, R67, | 5 | 10kohm | R_US | Resistor_SMD:R_0603_1608Metric | Resistor, US symbol
R15, R16, R17, R18, R21, R22, R25, R26, R55, R56, R64, R68, R71, R76, | 14 | 4.7kohm | R_US | Resistor_SMD:R_0603_1608Metric | Resistor, US symbol
R19, R20, R23, R24, | 4 | 9.1kohm | R_US | Resistor_SMD:R_0603_1608Metric | Resistor, US symbol
R35, R36, R37, R38, | 4 | 33ohm | R_US | Resistor_SMD:R_0603_1608Metric | Resistor, US symbol
R39, | 1 | 13kohm | R_US | Resistor_SMD:R_0603_1608Metric | Resistor, US symbol
R41, R42, R65, R66, R69, R70, | 6 | 100ohm | R_US | Resistor_SMD:R_0603_1608Metric | Resistor, US symbol
R43, | 1 | 50ohm | R_US | Resistor_SMD:R_0603_1608Metric | Resistor, US symbol
R46, R48, | 2 | 3.57kohm | R_US | Resistor_SMD:R_0603_1608Metric | Resistor, US symbol
R47, R49, | 2 | 1.15kohm | R_US | Resistor_SMD:R_0603_1608Metric | Resistor, US symbol
R50, | 1 | 180ohm | R_US | Resistor_SMD:R_0603_1608Metric | Resistor, US symbol
R51, | 1 | 2.2kohm | R_US | Resistor_SMD:R_0603_1608Metric | Resistor, US symbol
R60, | 1 | 22.1kohm | R_US | Resistor_SMD:R_0603_1608Metric | Resistor, US symbol
R61, | 1 | 47.5kohm | R_US | Resistor_SMD:R_0603_1608Metric | Resistor, US symbol
R78, R79, | 2 | 0ohm | R_US | Resistor_SMD:R_0402_1005Metric | Resistor, US symbol
SW1, | 1 | CUS-12TB | CUS-12TB_1 | CUS-12TB_NDC
U1, | 1 | TS472IQT | TS472IQT | footprints24:QFN_72IQT_STM
U2, U6, | 2 | OPA837IDBVT | OPA837IDBVT | footprints20:DBV6_TEX
U3, U4, | 2 | ADA4940-2ACPZ-R7 | ADA4940-2ACPZ-R7 | ADA4940-2ACPZ-R7:QFN50P400X400X80-25N
U5, | 1 | AD4680BCPZ-RL7 | AD4680BCPZ-RL7 | AD4680:CP-16-45_ADI
U7, U8, | 2 | TPS7A9201DSKT | TPS7A9101DSKR | TPS7A9101DSKR:SON50P250X250X80-11N
U9, | 1 | MIC29502AWD-TR | MIC29302AWD-TR | Package_TO_SOT_SMD:TO-263-5_TabPin6
U10, | 1 | REF3430TIDBVR | REF3430TIDBVR_2 | REF3430TIDBVR:DBV0006A_N
U11, | 1 | OPA2837xDGK | OPA1692xDGK | Package_SO:VSSOP-8_3.0x3.0mm_P0.65mm | Dual SoundPlus Low Power, Low Noise & Low Distortion Audio Operational Amplifiers, VSSOP-8
U12, U13, U15, U16, U19, U20, U21, U22, | 8 | SN74LVC540APWR | SN74LVC540APWR_1 | footprints31:PW20-L
U17, | 1 | CP2102N-Axx-xQFN28 | CP2102N-Axx-xQFN28 | Package_DFN_QFN:QFN-28-1EP_5x5mm_P0.5mm_EP3.35x3.35mm | USB to UART master bridge, QFN-28
U18, | 1 | ESP32-WROOM-32D | ESP32-WROOM-32D | ESP32-WROOM-32D:MODULE_ESP32-WROOM-32D

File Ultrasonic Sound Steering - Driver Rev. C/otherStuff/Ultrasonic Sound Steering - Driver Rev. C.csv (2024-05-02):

Source: | C:\Users\kharp\Desktop\School\2024\F2024\ELEC4498-CapstoneII\CAD\Ultrasonic Sound Steering - Driver Rev. C\UltrasonicDrive.kicad_sch
Date: | 1/31/2024 5:19:48 PM
Tool: | Eeschema (6.0.11)
Generator: | C:\Program Files\KiCad\6.0\bin\scripting\plugins/bom_csv_grouped_by_value_with_fp.py
Component Count: | 134
Ref | Qnty | Value | Cmp name | Footprint | Description | Vendor
C1, C3, C5, C7, C9, C11, C13, C15, C17, C19, C21, C23, C25, C27, C29, C31, C33, C35, C37, C39, C41, C43, C45, C47, C49, C51, C53, C55, C57, C59, C61, C63, | 32 | 4.7µF | C_Small | Capacitor_SMD:C_0603_1608Metric | Unpolarized capacitor, small symbol
C2, C4, C6, C8, C10, C12, C14, C16, C18, C20, C22, C24, C26, C28, C30, C32, C34, C36, C38, C40, C42, C44, C46, C48, C50, C52, C54, C56, C58, C60, C62, C64, C67, C69, C71, | 35 | 100nF | C | Capacitor_SMD:C_0603_1608Metric | Unpolarized capacitor
C65, C76, C82, | 3 | 1µF | C | Capacitor_SMD:C_0603_1608Metric | Unpolarized capacitor
C66, C68, C70, | 3 | 10µF | C | Capacitor_SMD:C_0603_1608Metric | Unpolarized capacitor
C72, C73, C77, C78, C81, | 5 | 22µF | C | Capacitor_SMD:C_0805_2012Metric | Unpolarized capacitor
D1, | 1 | BAT54H,115 | D_Schottky | Diode_SMD:D_SOD-123F | Schottky diode
Q1, Q3, Q4, | 3 | DMN65D8L | 2N7002 | footprints12:DMP3099L-7_DIO | 0.115A Id, 60V Vds, N-Channel MOSFET, SOT-23
Q2, | 1 | DMP3099L | DMP3099L_1 | footprints12:DMP3099L-7_DIO
R1, R2, | 2 | 10kΩ | R_US | Resistor_SMD:R_0603_1608Metric | Resistor, US symbol
R3, R5, R6, R9, R10, R11, | 6 | 4.7kΩ | R_US | Resistor_SMD:R_0603_1608Metric | Resistor, US symbol
R4, R7, R12, | 3 | 100Ω | R_US | Resistor_SMD:R_0603_1608Metric | Resistor, US symbol
R8, | 1 | 180Ω | R_US | Resistor_SMD:R_0603_1608Metric | Resistor, US symbol
R13, | 1 | 1.2kΩ | R_US | Resistor_SMD:R_0603_1608Metric | Resistor, US symbol
R14, R15, | 2 | 0Ω | R_US | Resistor_SMD:R_0603_1608Metric | Resistor, US symbol
SW1, | 1 | CUS-12TB | CUS-12TB_1 | CUS-12TB:CUS-12TB_NDC
U1, U2, U3, U4, U5, U6, U7, U8, U9, U10, U11, U12, U13, U14, U15, U16, U17, U18, U19, U20, U21, U22, U23, U24, U25, U26, U27, U28, U29, U30, U31, U32, | 32 | MIC4127 | MIC4127 | Capstone Symbols, Footprints:MSOP-8-1EP_3x3mm_P0.65mm_EP1.95x2.15mm_ThermalVias_mic4127alt
U33, | 1 | 74LVC1G14 | 74LVC1G14_1 | Package_TO_SOT_SMD:SOT-23-5 | Single Schmitt NOT Gate, Low-Voltage CMOS
U34, | 1 | SIP32510DT-T1-GE3 | SIP32510DT-T1-GE3 | SIP32510DT_T1_GE3:SIP32510DT-T1-GE3_VIS
U35, | 1 | AD5272BRMZ-100-RL7 | AD5272BRMZ-100-RL7_1 | footprints30:RM_10_ADI

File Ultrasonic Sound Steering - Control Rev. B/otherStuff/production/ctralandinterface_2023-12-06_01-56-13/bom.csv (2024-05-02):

Designator | Footprint | Quantity | Value | LCSC Part #
_93, _92, _91, _90, _89, _88, _87, _86, _85, _84, _83, _82, _81, _80, _79, _78, _77, _76, _75, _74, _73, _72, _71, _70, _69, _68, _67, _66, _65, _64, _63, _62, _61, _60, _59, _58, _57, _56, _55, _54, _53, _52, _51, _50, _49, _48, _47, _46, _45, _44, _43, _42, _41, _40, _39, _38, _37, _36, _35, _34, _33, _32, _31, _30, _29, _28, _27, _26, _25, _24, _23, _22, _21, _20, _19, _18, _17, _16, _15, _14, _13, _12, _11, _10, _9, _8, _7, _6, _5, _4, _3, _2, |  | 93
C1, C128, C35, C36, C51, C52 | CP_EIA-3216-18_Kemet-A | 6 | 10µF
C10, C11 | 0603 | 2 | 100pF
C100, C102, C107, C108, C119, C121, C124, C126, C127, C130, C69, C70, C71, C72 | 0603 | 14 | 22µF
C101, C104, C105, C106, C109, C110, C113, C116, C117, C118, C120, C122, C123, C125, C129, C131, C132, C135, C16, C28, C32, C40, C41, C42, C45, C49, C50, C57, C58, C6, C61, C63, C64, C66, C76, C8, C86, C89, C90, C91, C93, C94, C97, C98, C99 | 0603 | 45 | 100nF
C103, C111, C112, C114, C115, C12, C133, C134, C17, C4, C56, C62, C65, C92, C95, C96 | 0603 | 16 | 10µF
C13 | 0603 | 1 | 1nF
C14, C15 | 0603 | 2 | 680nF
C18 | 0603 | 1 | 680pF
C19, C20 | 0603 | 2 | 1.5nF
C2, C3 | 0603 | 2 | 68nF
C21, C22, C23, C24, C33, C34 | 0603 | 6 | 470pF
C25, C29, C39, C43, C77, C78, C9 | 0603 | 7 | 10nF
C26, C27, C30, C31, C5, C7 | 0603 | 6 | 6.8µF
C37, C38 | 0603 | 2 | 150pF
C44, C48 | 0603 | 2 | 330pF
C46, C47, C53, C54 | 0603 | 4 | 68pF
C55, C59, C60, C73, C74, C85 | 0603 | 6 | 1µF
C67, C68 | CP_EIA-3528-21_Kemet-B | 2 | 47µF
C75 | 0603 | 1 | 47nF
C79, C87 | CP_EIA-3528-21_Kemet-B | 2 | 100µF
C80, C81, C82, C83, C84, C88 | 0603 | 6 | 47µF
D1, D2, D4 | D_SOD-123 | 3 | MBR0520L
D3, D8, D9 | 1206 | 3 | LED
D5, D6, D7 | D_SOD-523 | 3 | LESD5D5.0CT1G
P1, P2, P3, P4, P5, P6, P7, P8 | PinSocket_2x08_P2.54mm_Vertical | 8 | Conn_02x08_Odd_Even
P10 | PinSocket_2x04_P2.54mm_Vertical | 1 | Conn_02x04
P11 | CUI_SJ1-42516 | 1 | SJ1-42516
P12 | CUI_PJ-051BH | 1 | PJ-051BH
P13 | USB_Micro-B_Molex-105017-0001_Alt | 1 | USB_Micro-B_Molex-105017
P14 | CON_1053131103 | 1 | Molex 1053131103
P9 | CUI_SJ1-3524NG | 1 | SJ1-3524NG
Q1, Q2, Q3, Q4 | DMP3099L-7_DIO | 4 | DMN65D8L
R1, R2, R4, R44, R45, R7, R77, R9 | 0603 | 8 | 100kΩ
R10, R11 | 0603 | 2 | 2kΩ
R12 | 0603 | 1 | 1.2kΩ
R13, R14, R53, R54, R67 | 0603 | 5 | 10kΩ
R15, R16, R17, R18, R21, R22, R25, R26, R55, R56, R64, R68, R71, R76 | 0603 | 14 | 4.7kΩ
R19, R20, R23, R24 | 0603 | 4 | 9.1kΩ
R27, R28, R29, R30, R31, R32, R33, R34, R40, R5, R52, R6, R62, R63 | 0603 | 14 | 1kΩ
R3, R57, R58, R59, R72, R73, R74, R75, R80, R81, R82, R83, R84, R85, R86 | 0603 | 15 | 0Ω
R35, R36, R37, R38 | 0603 | 4 | 33Ω
R39 | 0603 | 1 | 13kΩ
R41, R42, R65, R66, R69, R70 | 0603 | 6 | 100Ω
R43 | 0603 | 1 | 50Ω
R46, R48 | 0603 | 2 | 3.57kΩ
R47, R49 | 0603 | 2 | 1.15kΩ
R50 | 0603 | 1 | 180Ω
R51 | 0603 | 1 | 2.2kΩ
R60 | 0603 | 1 | 22.1kΩ
R61 | 0603 | 1 | 47.5kΩ
R78, R79 | 0402 | 2 | 0Ω
R8 | 0603 | 1 | 68Ω
SW1 | CUS-12TB_NDC | 1 | CUS-12TB
U1 | QFN_72IQT_STM | 1 | TS472IQT
U10 | DBV0006A_N | 1 | REF3430TIDBVR
U11 | VSSOP-8_3.0x3.0mm_P0.65mm | 1 | OPA2837xDGK
U12, U13, U15, U16, U19, U20, U21, U22 | PW20-L | 8 | SN74LVC540APWR
U17 | QFN-28-1EP_5x5mm_P0.5mm_EP3.35x3.35mm | 1 | CP2102N-Axx-xQFN28
U18 | MODULE_ESP32-WROOM-32D | 1 | ESP32-WROOM-32D
U2, U6 | DBV6_TEX | 2 | OPA837IDBVT
U3, U4 | QFN50P400X400X80-25N | 2 | ADA4940-2ACPZ-R7
U5 | CP-16-45_ADI | 1 | AD4680BCPZ-RL7
U7, U8 | SON50P250X250X80-11N | 2 | TPS7A9201DSKT
U9 | TO-263-5_TabPin6 | 1 | MIC29502AWD-TR

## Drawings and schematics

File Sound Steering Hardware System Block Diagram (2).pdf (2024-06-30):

## Sound Steering Hardware System Block Diagram

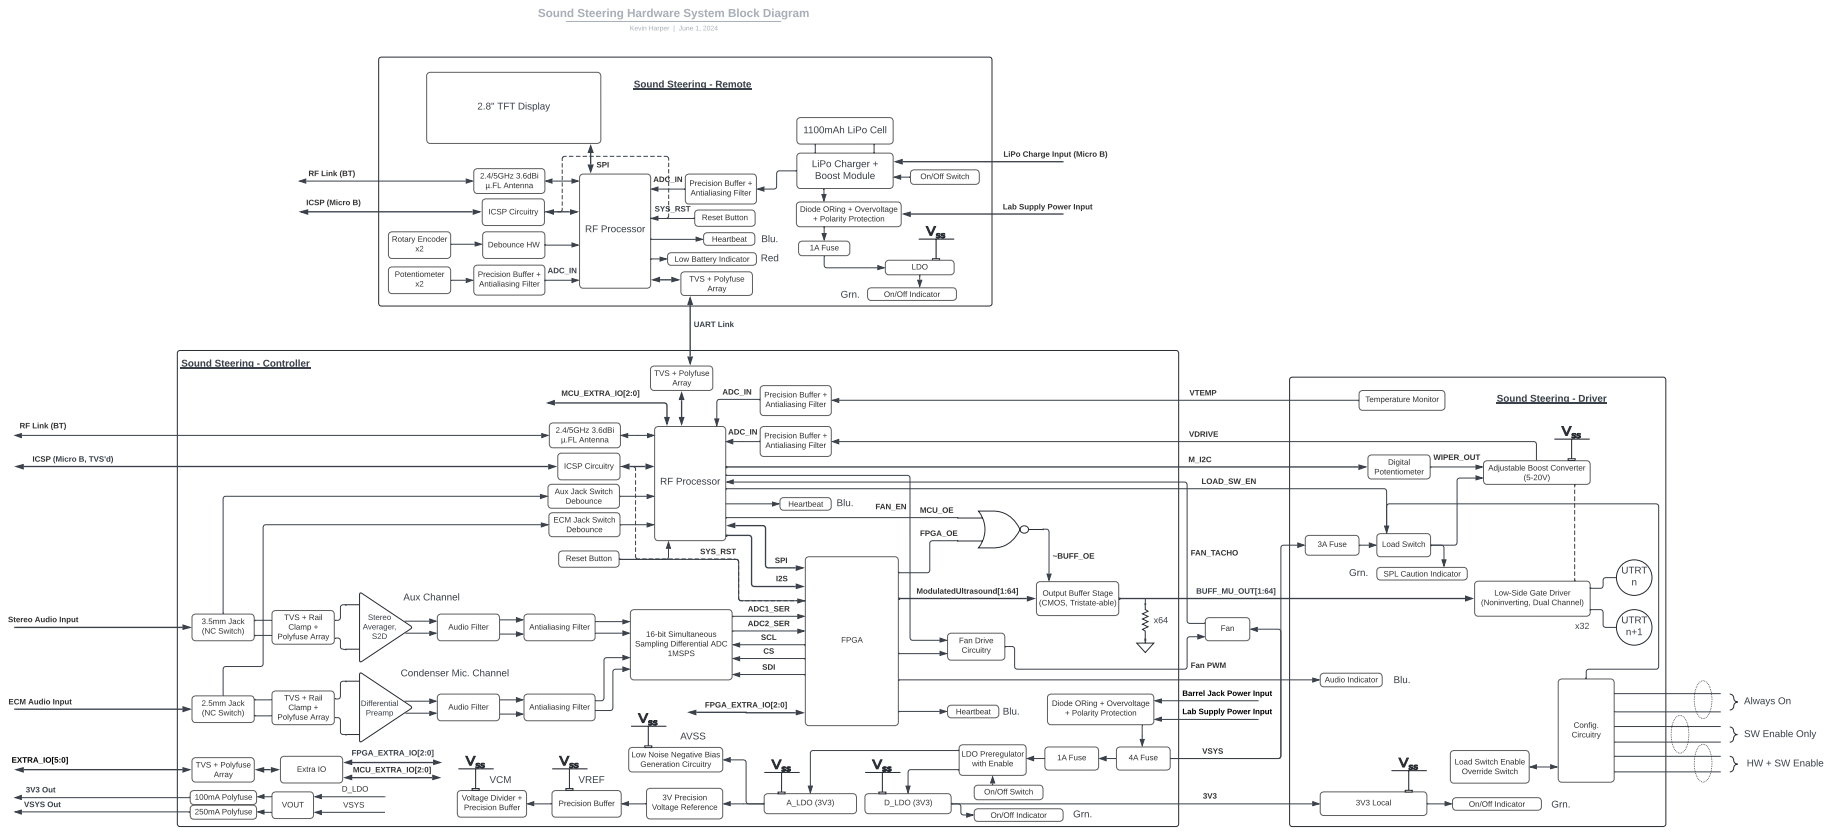
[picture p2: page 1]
Audio Filter; Antialiasing Filter; 16-bit Simultaneous; 1MSPS; ADC1_SER; ADC2_SER; FPGA; ModulatedUltrasound[1:64]; Rotary Encoder x2; Potentiometer x2; Debounce HW; Precision Buffer + Antialiasing Filter; RF Processor; ADC_IN; 2.8" TFT Display; SPI; LiPo Charger +; Boost Module; 1100mAh LiPo Cell; Heartbeat; ICSP Circuitry; 2.4/5GHz 3.6dBi µ.FL Antenna; 1A Fuse; Digital Potentiometer; WIPER_OUT; + Polarity Protection; Lab Supply Power Input; 4A Fuse; LDO; A_LDO (3V3); ICSP (Micro B)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

Kevin Harper | June 1, 2024

Sound Steering - Remote

LiPo Charge Input (Micro B)

RF Link (BT)

On/Off Switch

Lab Supply Power Input

Diode ORing + Overvoltage
+ Polarity Protection

Low Battery Indicator

On/Off Indicator

Sound Steering - Controller

Sound Steering - Driver

ICSP (Micro B, TVS'd)

Adjustable Boost Converter

Aux Jack Switch
Debounce

ECM Jack Switch

SPL Caution Indicator

Output Buffer Stage
(CMOS, Tristate-able)

Low-Side Gate Driver
(Noninverting, Dual Channel)

Stereo Audio Input

Fan Drive Circuitry

Sampling Differential ADC

Condenser Mic. Channel

Barrel Jack Power Input

ECM Audio Input

SW Enable Only

Low Noise Negative Bias Generation Circuitry

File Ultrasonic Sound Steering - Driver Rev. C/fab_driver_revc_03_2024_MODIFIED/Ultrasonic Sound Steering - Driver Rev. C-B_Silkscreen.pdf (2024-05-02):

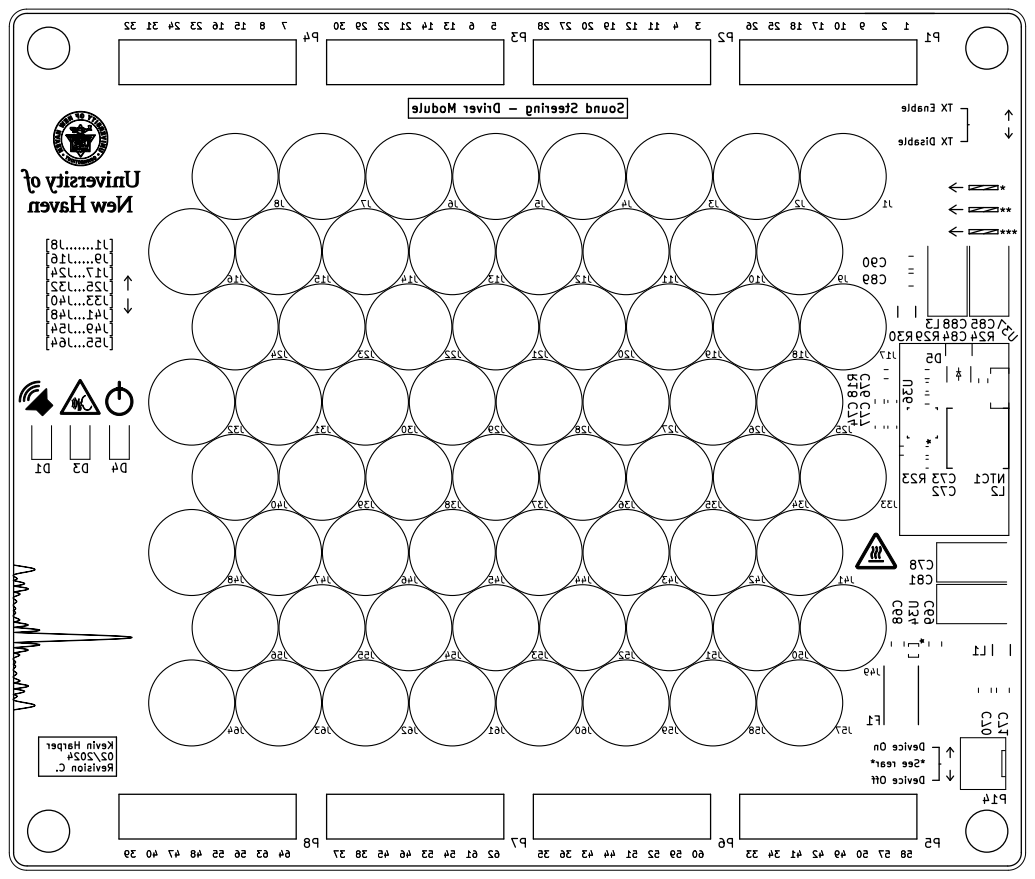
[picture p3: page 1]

Module Driver - Steering Sound

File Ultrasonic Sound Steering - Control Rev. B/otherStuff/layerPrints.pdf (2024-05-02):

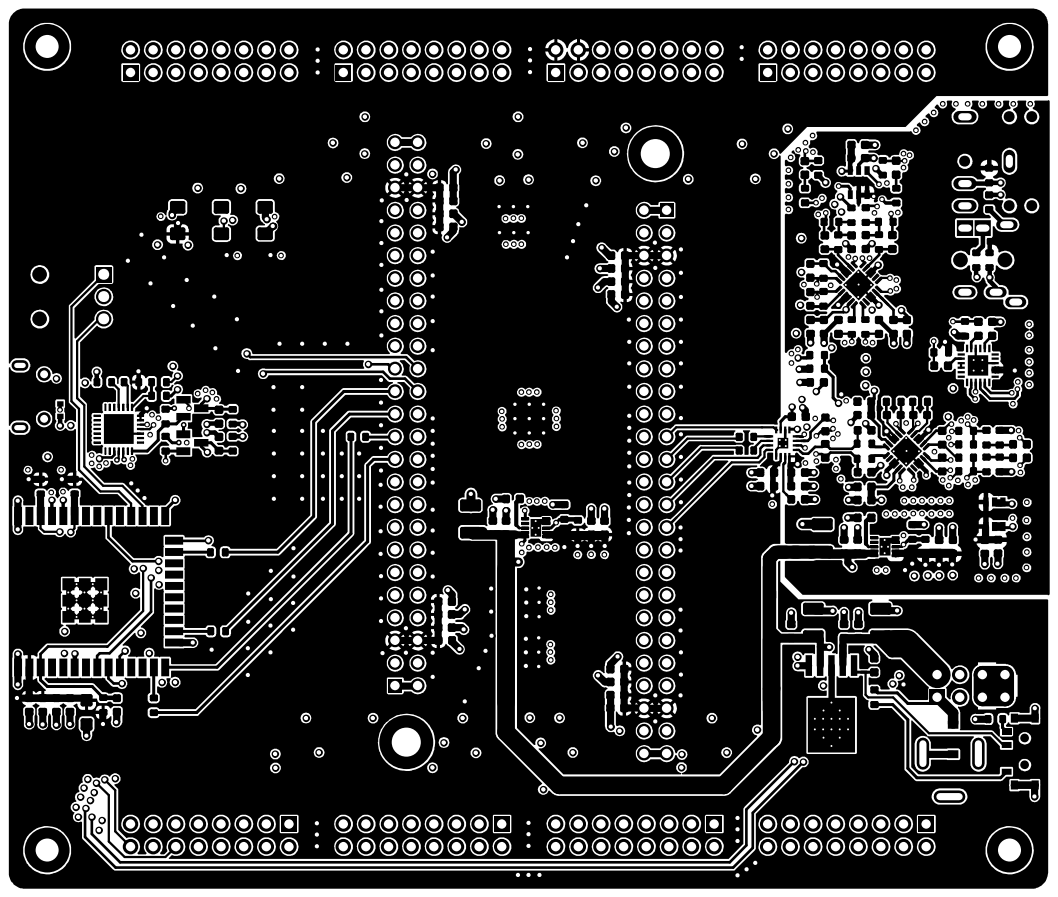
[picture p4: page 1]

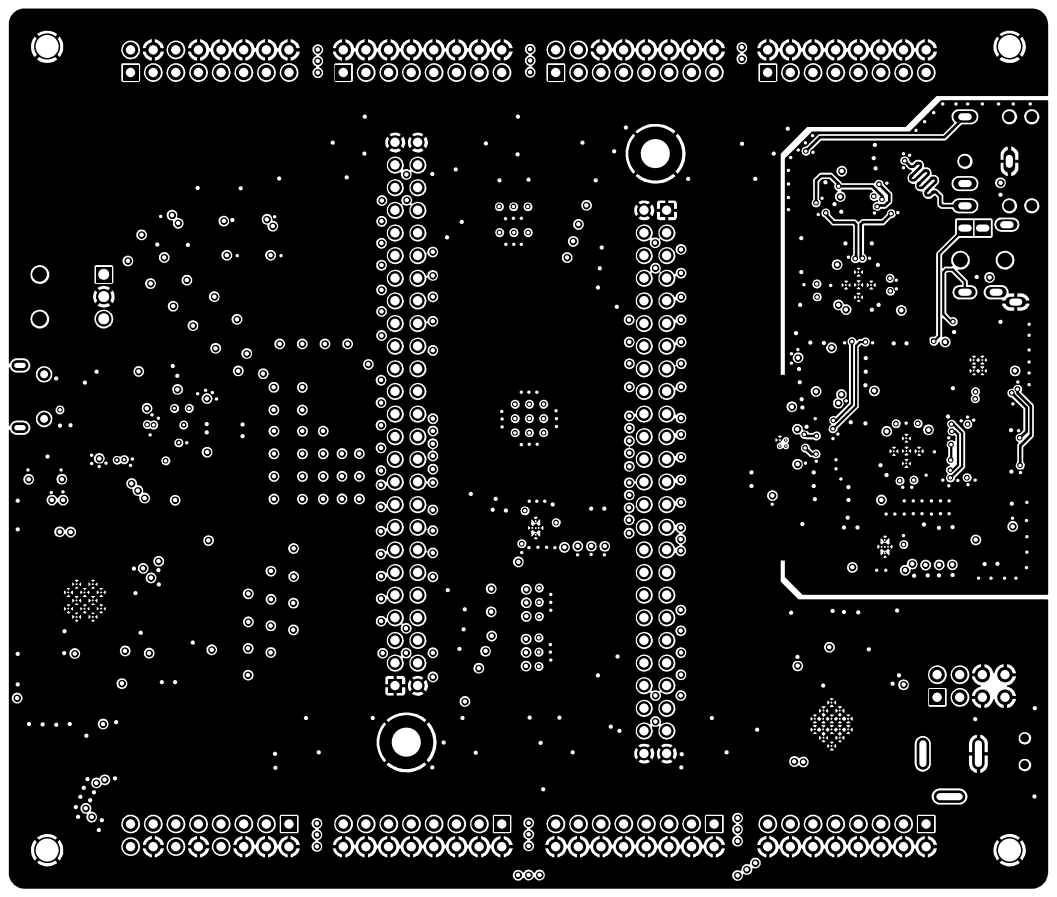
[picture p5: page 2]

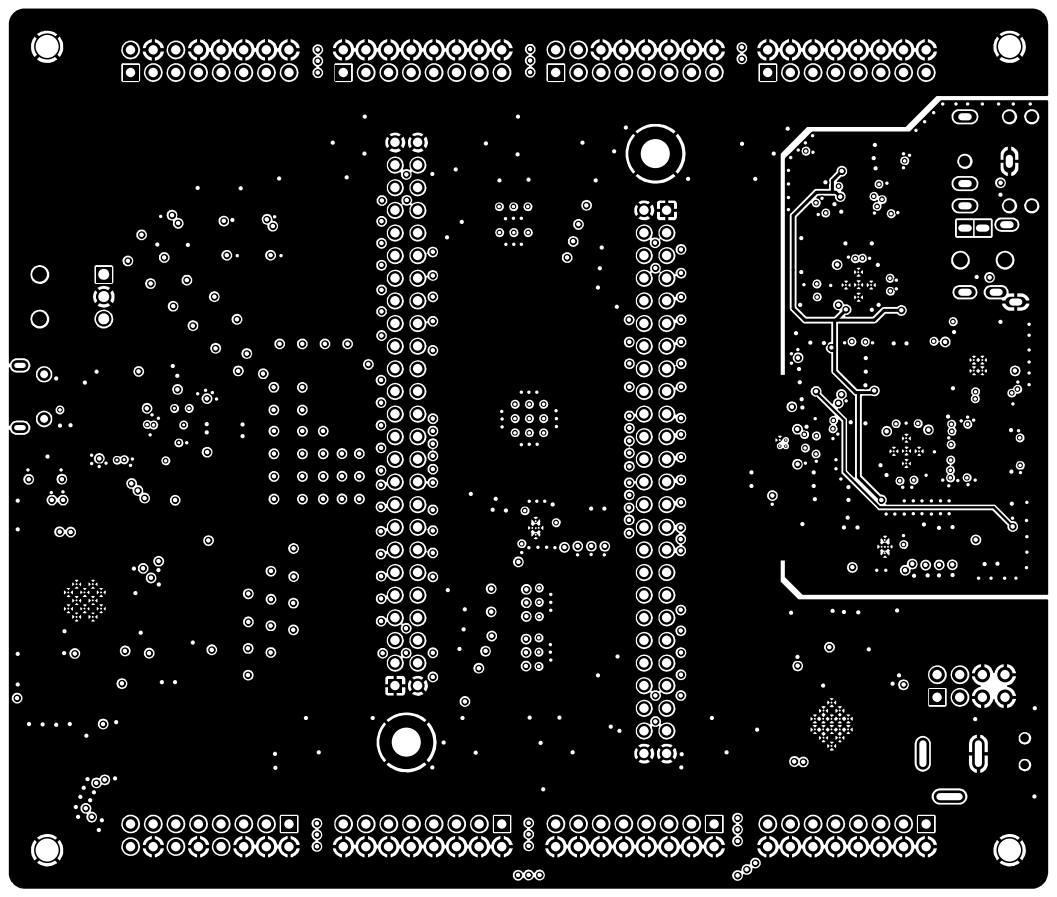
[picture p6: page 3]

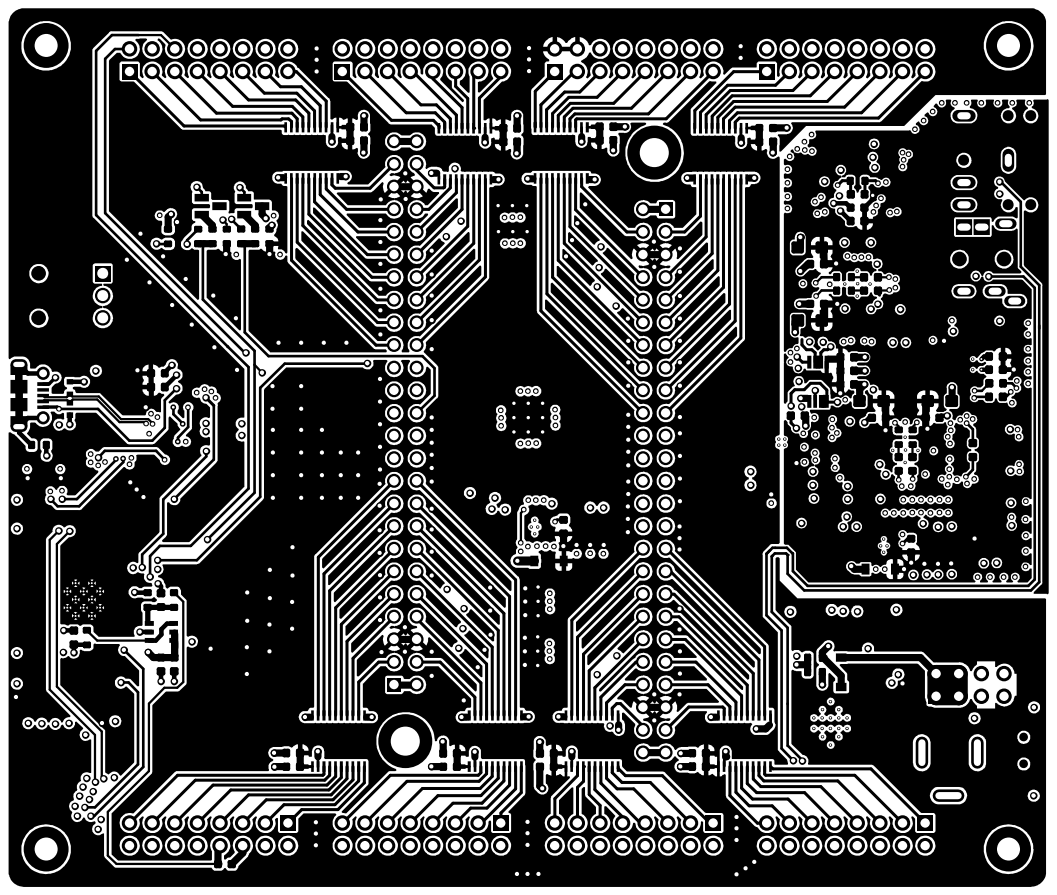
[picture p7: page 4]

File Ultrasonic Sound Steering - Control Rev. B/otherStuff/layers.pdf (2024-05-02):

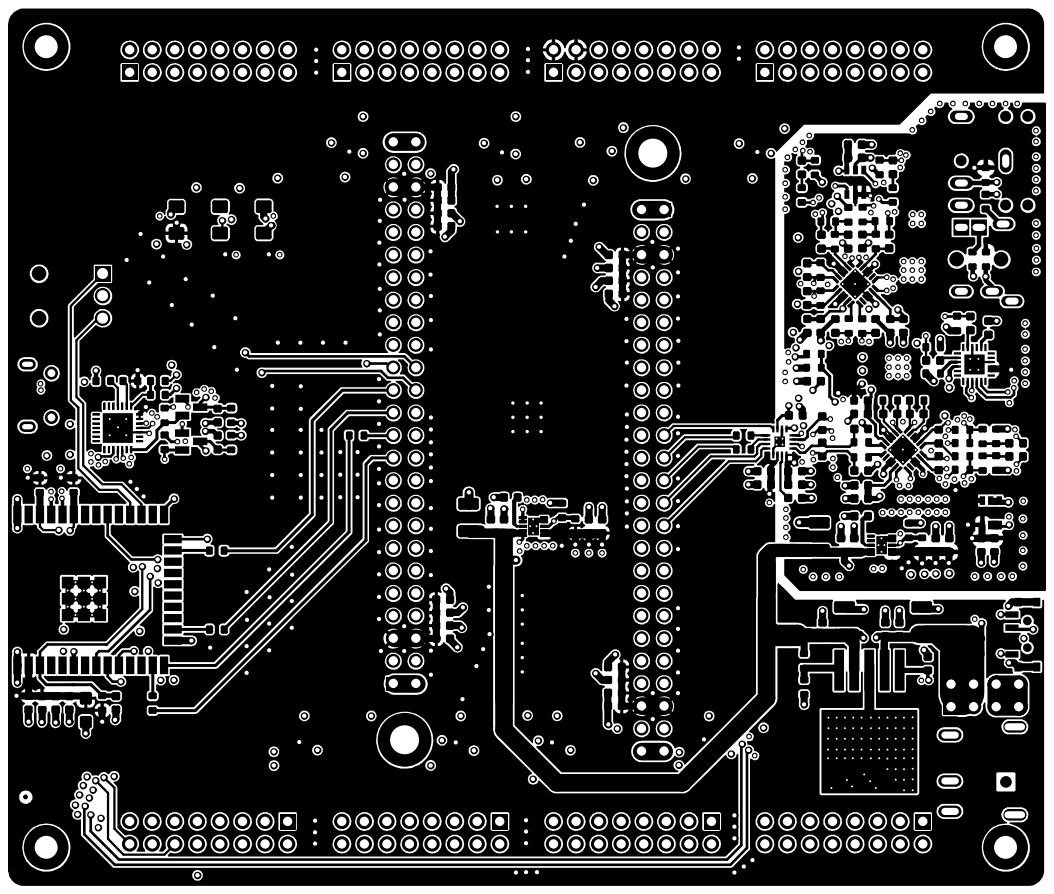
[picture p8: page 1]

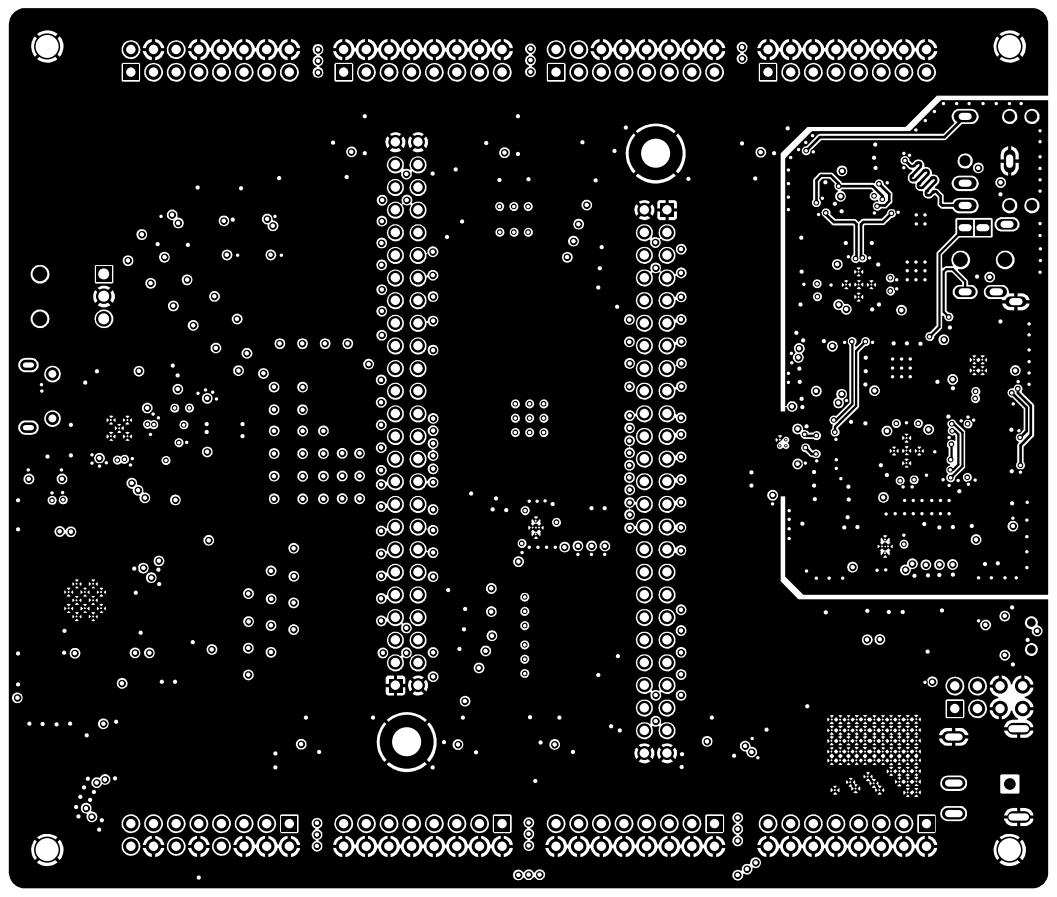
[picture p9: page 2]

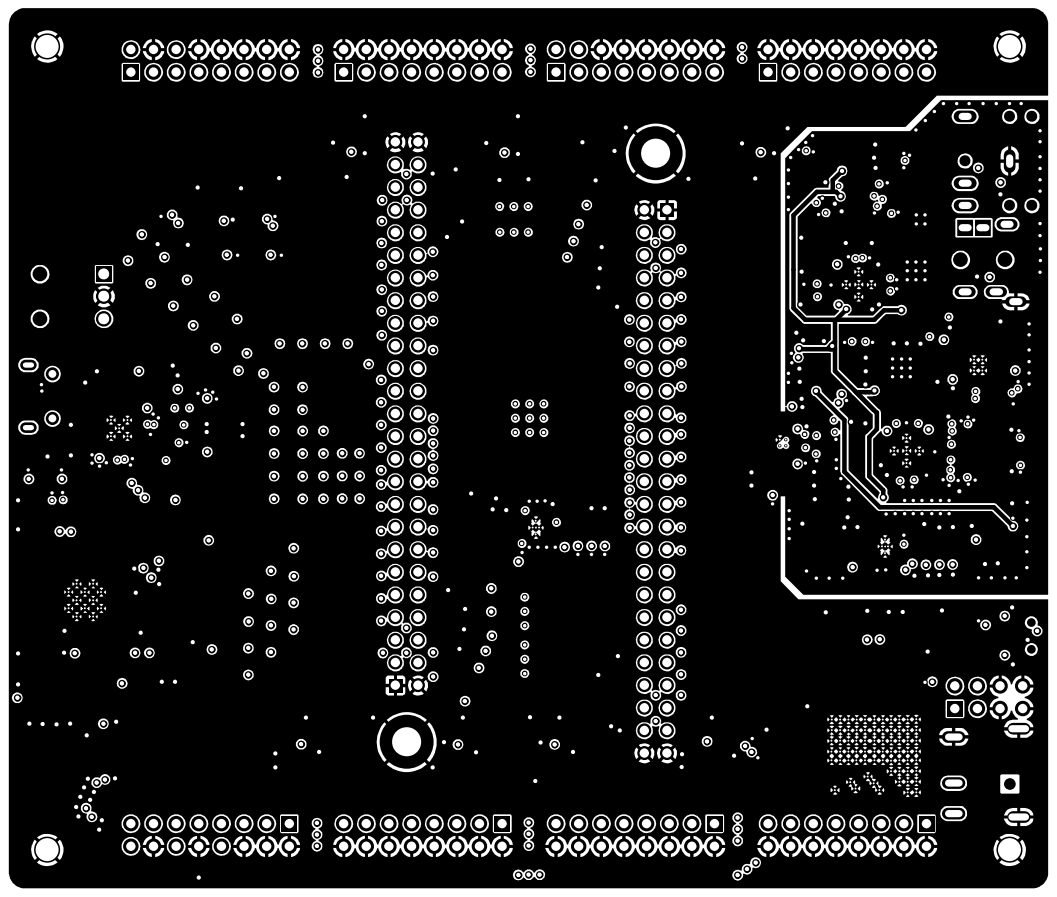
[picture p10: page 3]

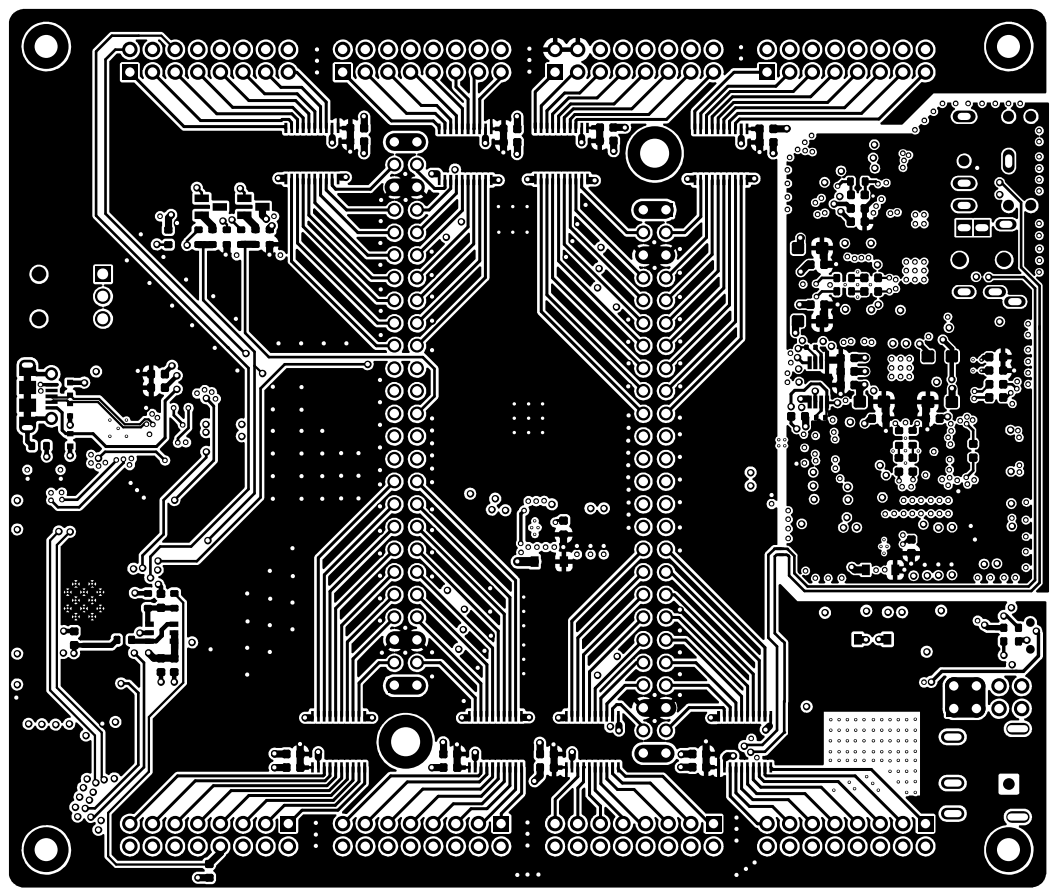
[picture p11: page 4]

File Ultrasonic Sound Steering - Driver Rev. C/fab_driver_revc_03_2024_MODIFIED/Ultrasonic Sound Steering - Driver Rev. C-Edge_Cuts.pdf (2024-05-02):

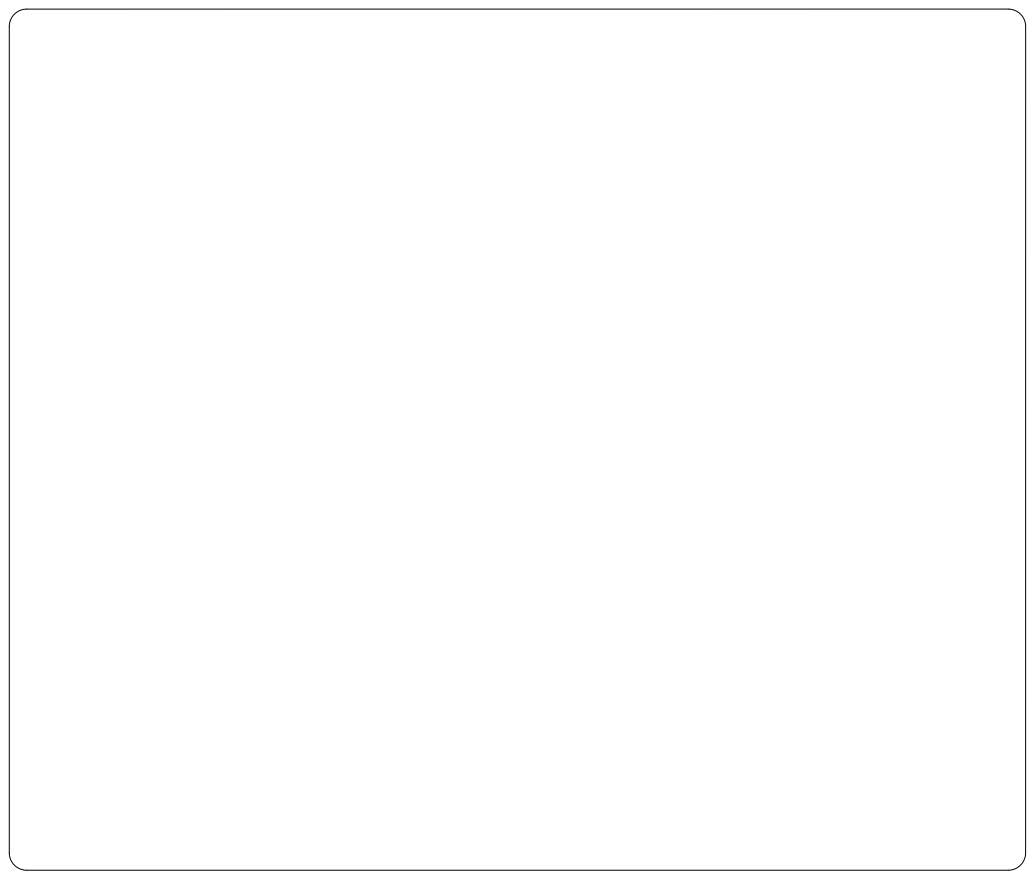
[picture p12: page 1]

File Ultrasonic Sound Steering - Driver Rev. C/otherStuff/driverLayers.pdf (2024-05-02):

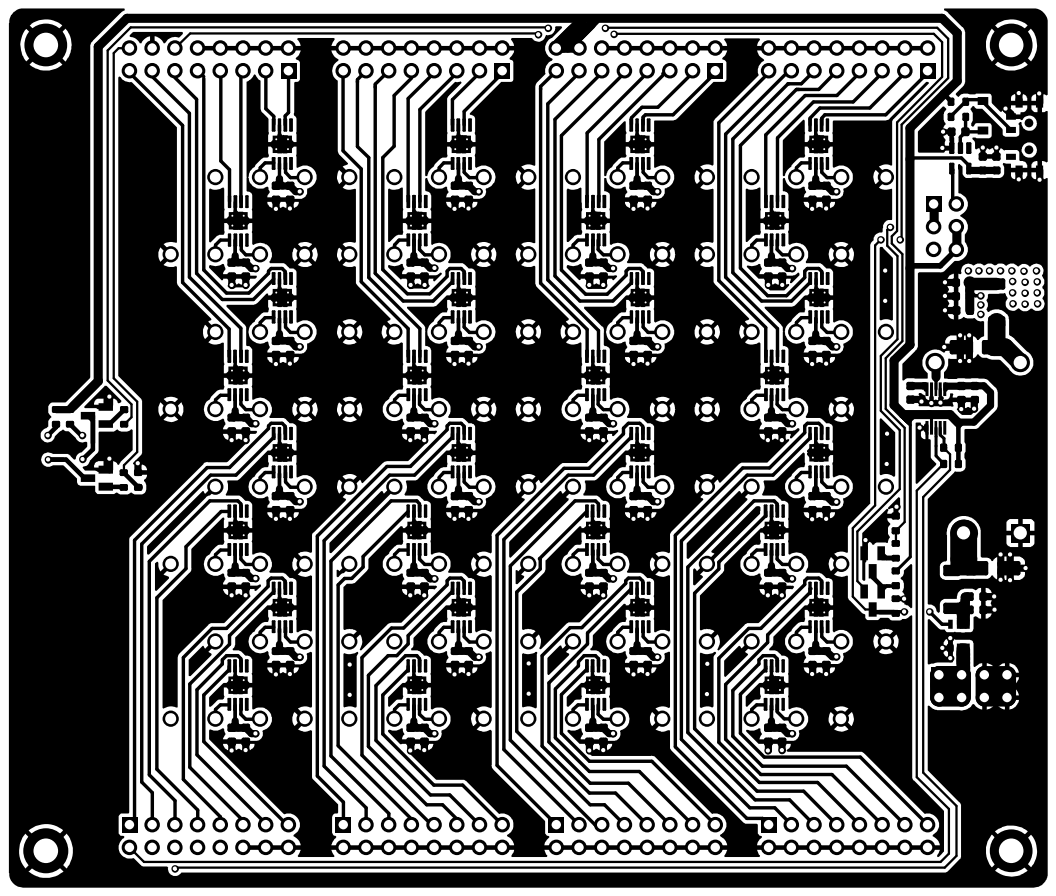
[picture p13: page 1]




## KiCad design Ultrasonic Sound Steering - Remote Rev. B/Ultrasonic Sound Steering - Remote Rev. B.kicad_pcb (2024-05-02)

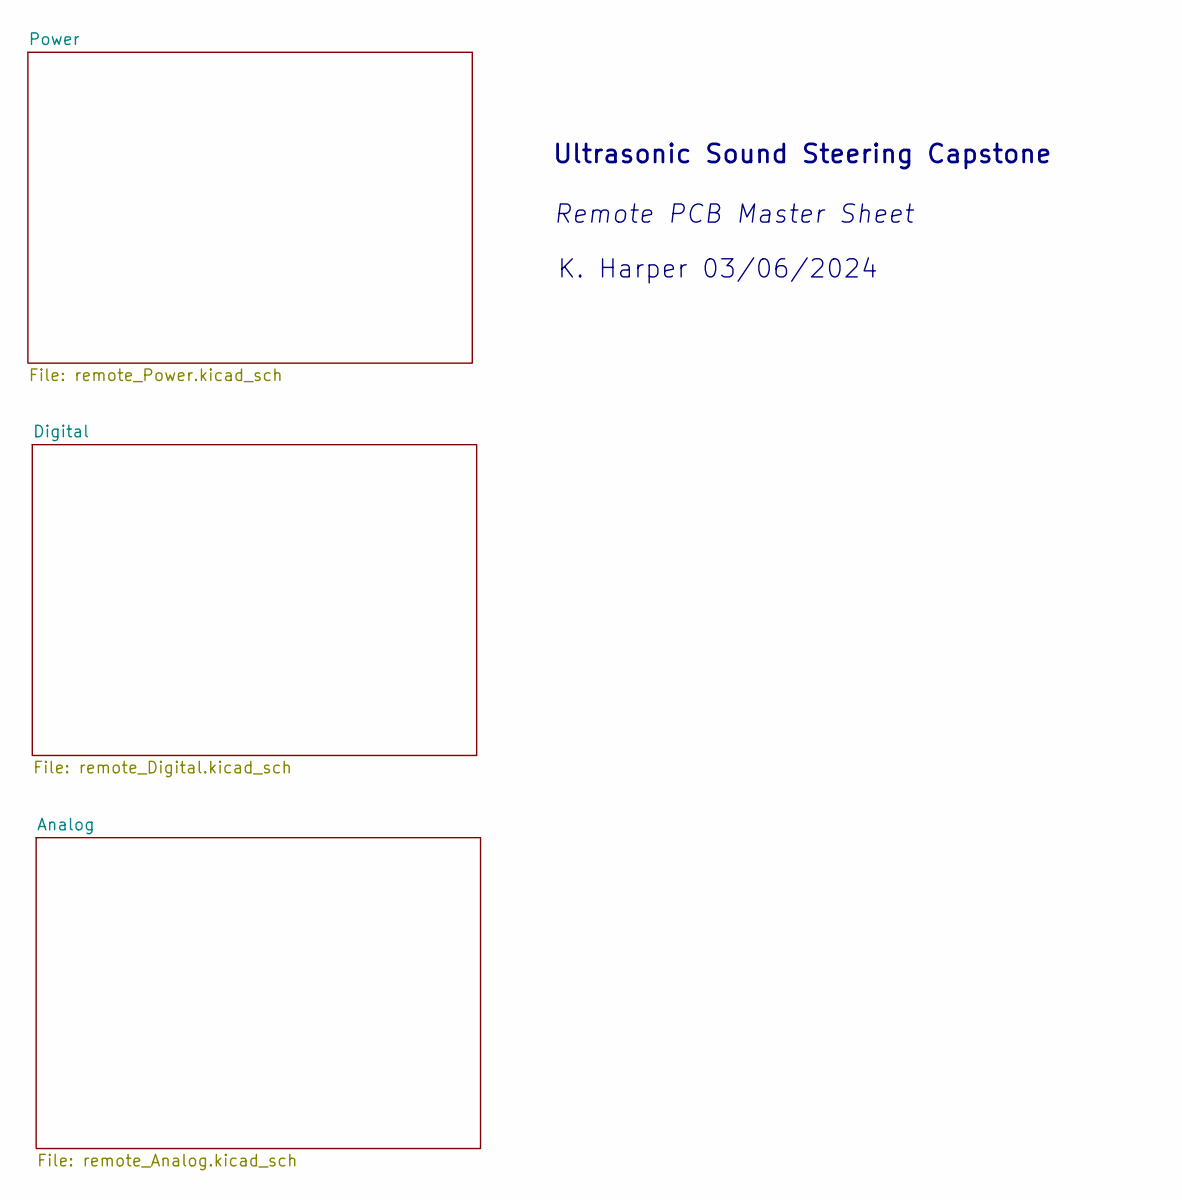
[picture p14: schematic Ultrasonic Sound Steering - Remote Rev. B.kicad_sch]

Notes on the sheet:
Remote PCB Master Sheet
K. Harper 03/06/2024
Ultrasonic Sound Steering Capstone

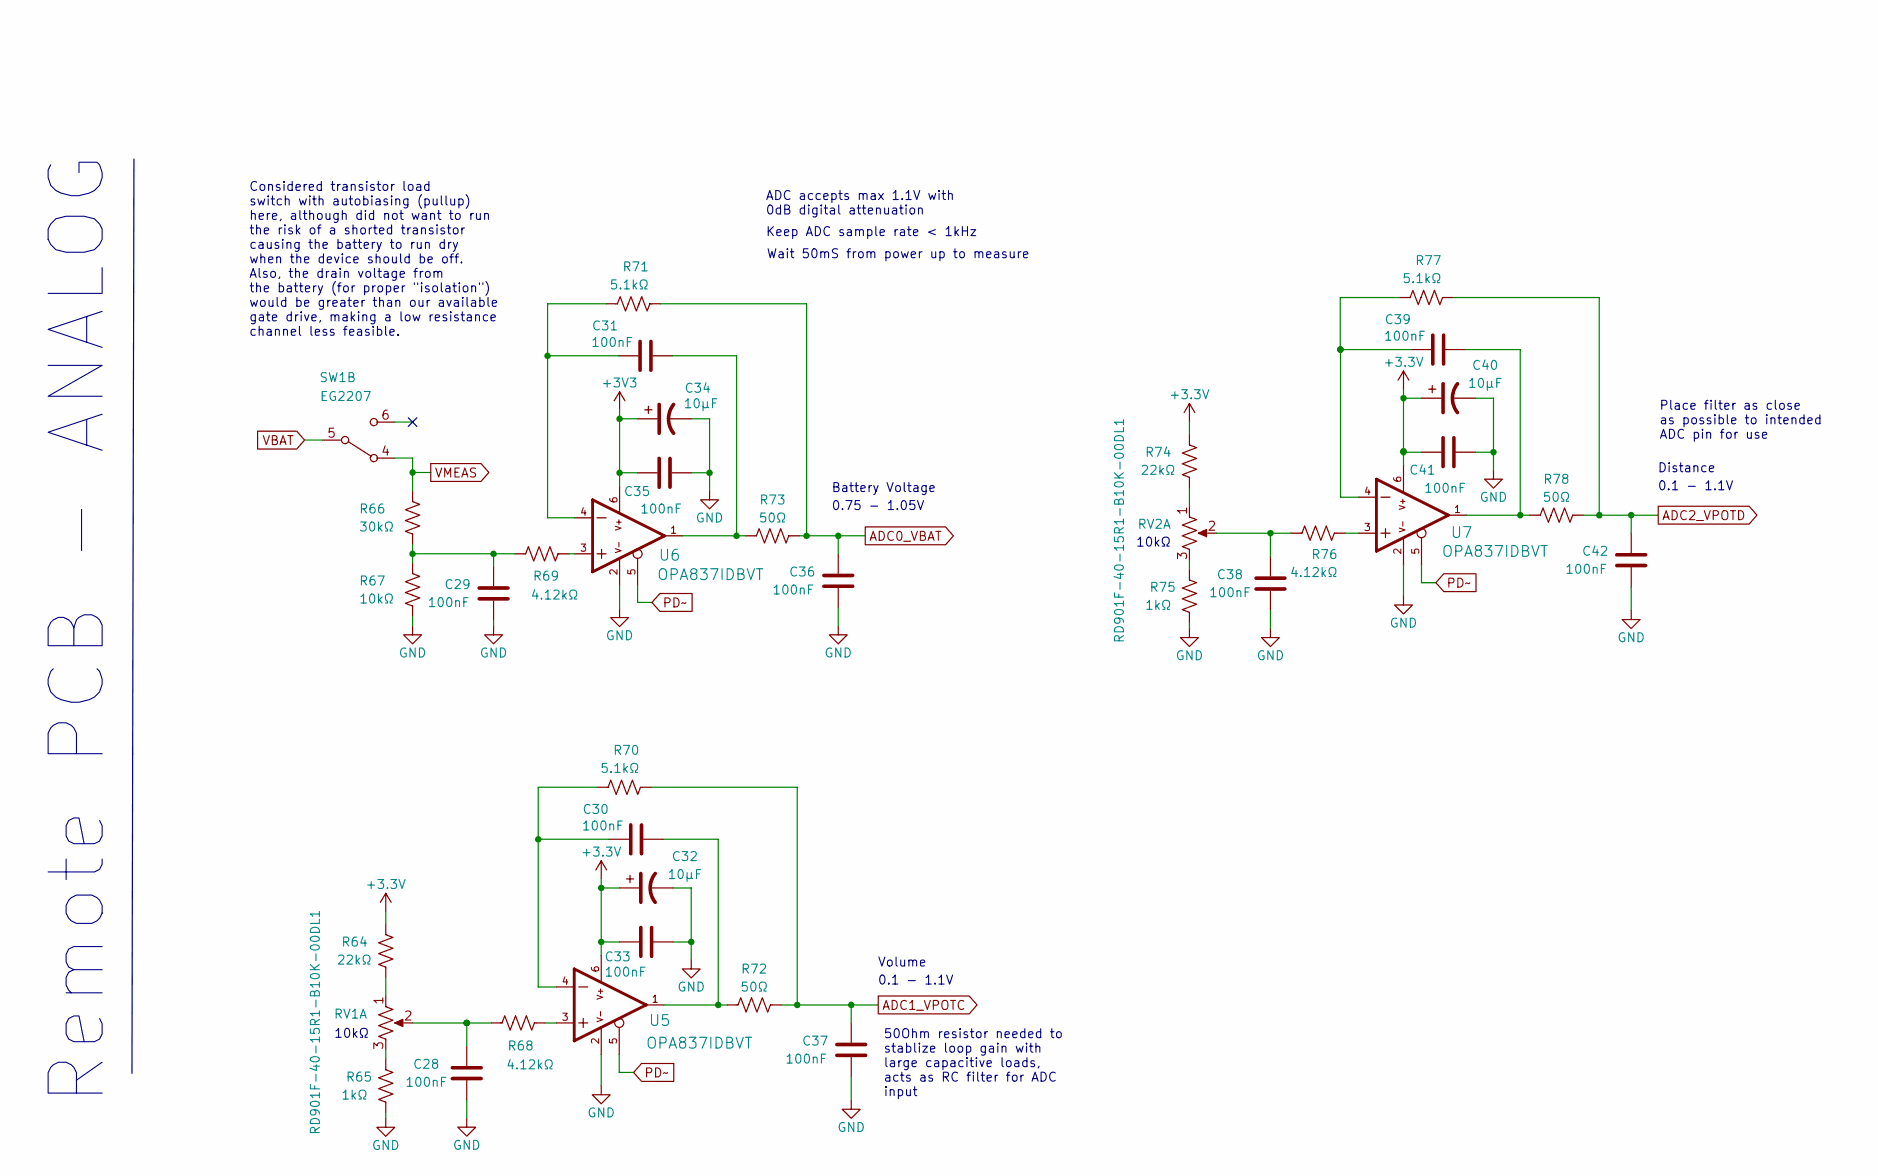
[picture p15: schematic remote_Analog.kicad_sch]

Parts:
C28, C29, C30, C31, C33, C35, C36, C37, C38, C39, C41, C42: 100nF; C_0603_1608Metric
C32, C34, C40: 10µF; C_TANT_1608-10
R64, R74: 22kΩ; R_0603_1608Metric
R65, R75: 1kΩ; R_0603_1608Metric
R66: 30kΩ; R_0603_1608Metric
R67: 10kΩ; R_0603_1608Metric
R68, R69, R76: 4.12kΩ; R_0603_1608Metric
R70, R71, R77: 5.1kΩ; R_0603_1608Metric
R72, R73, R78: 50Ω; R_0603_1608Metric
RV1, RV2: RD901F-40-15R1-B10K-00DL1; Potentiometer_Alps_RK09L_Single_Vertical
SW1: EG2207; SW_EG2207
U5, U6, U7: OPA837IDBVT; IC_SOT23-6

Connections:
ADC1_VPOTC: C37.2, R70.2, R72.2; also elsewhere on the board
ADC2_VPOTD: C42.2, R77.2, R78.2; also elsewhere on the board
GND: C28.1, C29.1, C32.2, C33.2, C34.2, C35.2, C36.1, C37.1, C38.1, C40.2, C41.2, C42.1, R65.2, R67.2, R75.2, U5.2, U6.2, U7.2; also elsewhere on the board
unnamed: C28.2, R68.1, RV1.2
unnamed: C29.2, R66.2, R67.1, R69.1
unnamed: C30.1, R70.1, U5.4
unnamed: C30.2, R72.1, U5.1
unnamed: C31.1, R71.1, U6.4
unnamed: C31.2, R73.1, U6.1
unnamed: C38.2, R76.1, RV2.2
unnamed: C39.1, R77.1, U7.4
unnamed: C39.2, R78.1, U7.1
unnamed: R64.2, RV1.1
unnamed: R65.1, RV1.3
unnamed: R68.2, U5.3
unnamed: R69.2, U6.3
unnamed: R74.2, RV2.1
unnamed: R75.1, RV2.3
unnamed: R76.2, U7.3
PD~: U5.5, U6.5, U7.5; also elsewhere on the board
VBAT: SW1.5; also elsewhere on the board
VMEAS: R66.1, SW1.4; also elsewhere on the board

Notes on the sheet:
Wait 50mS from power up to measure
Distance
Remote PCB - ANALOG
Place filter as close as possible to intended ADC pin for use
0.75 - 1.05V
Keep ADC sample rate < 1kHz
ADC accepts max 1.1V with 0dB digital attenuation
Volume
50Ohm resistor needed to stablize loop gain with large capacitive loads, acts as RC filter for ADC input
10kΩ
Battery Voltage
0.1 - 1.1V
Considered transistor load switch with autobiasing (pullup) here, although did not want to run the risk of a shorted transistor causing the battery to run dry when the device should be off. Also, the drain voltage from the battery (for proper "isolation") would be greater than our available gate dr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

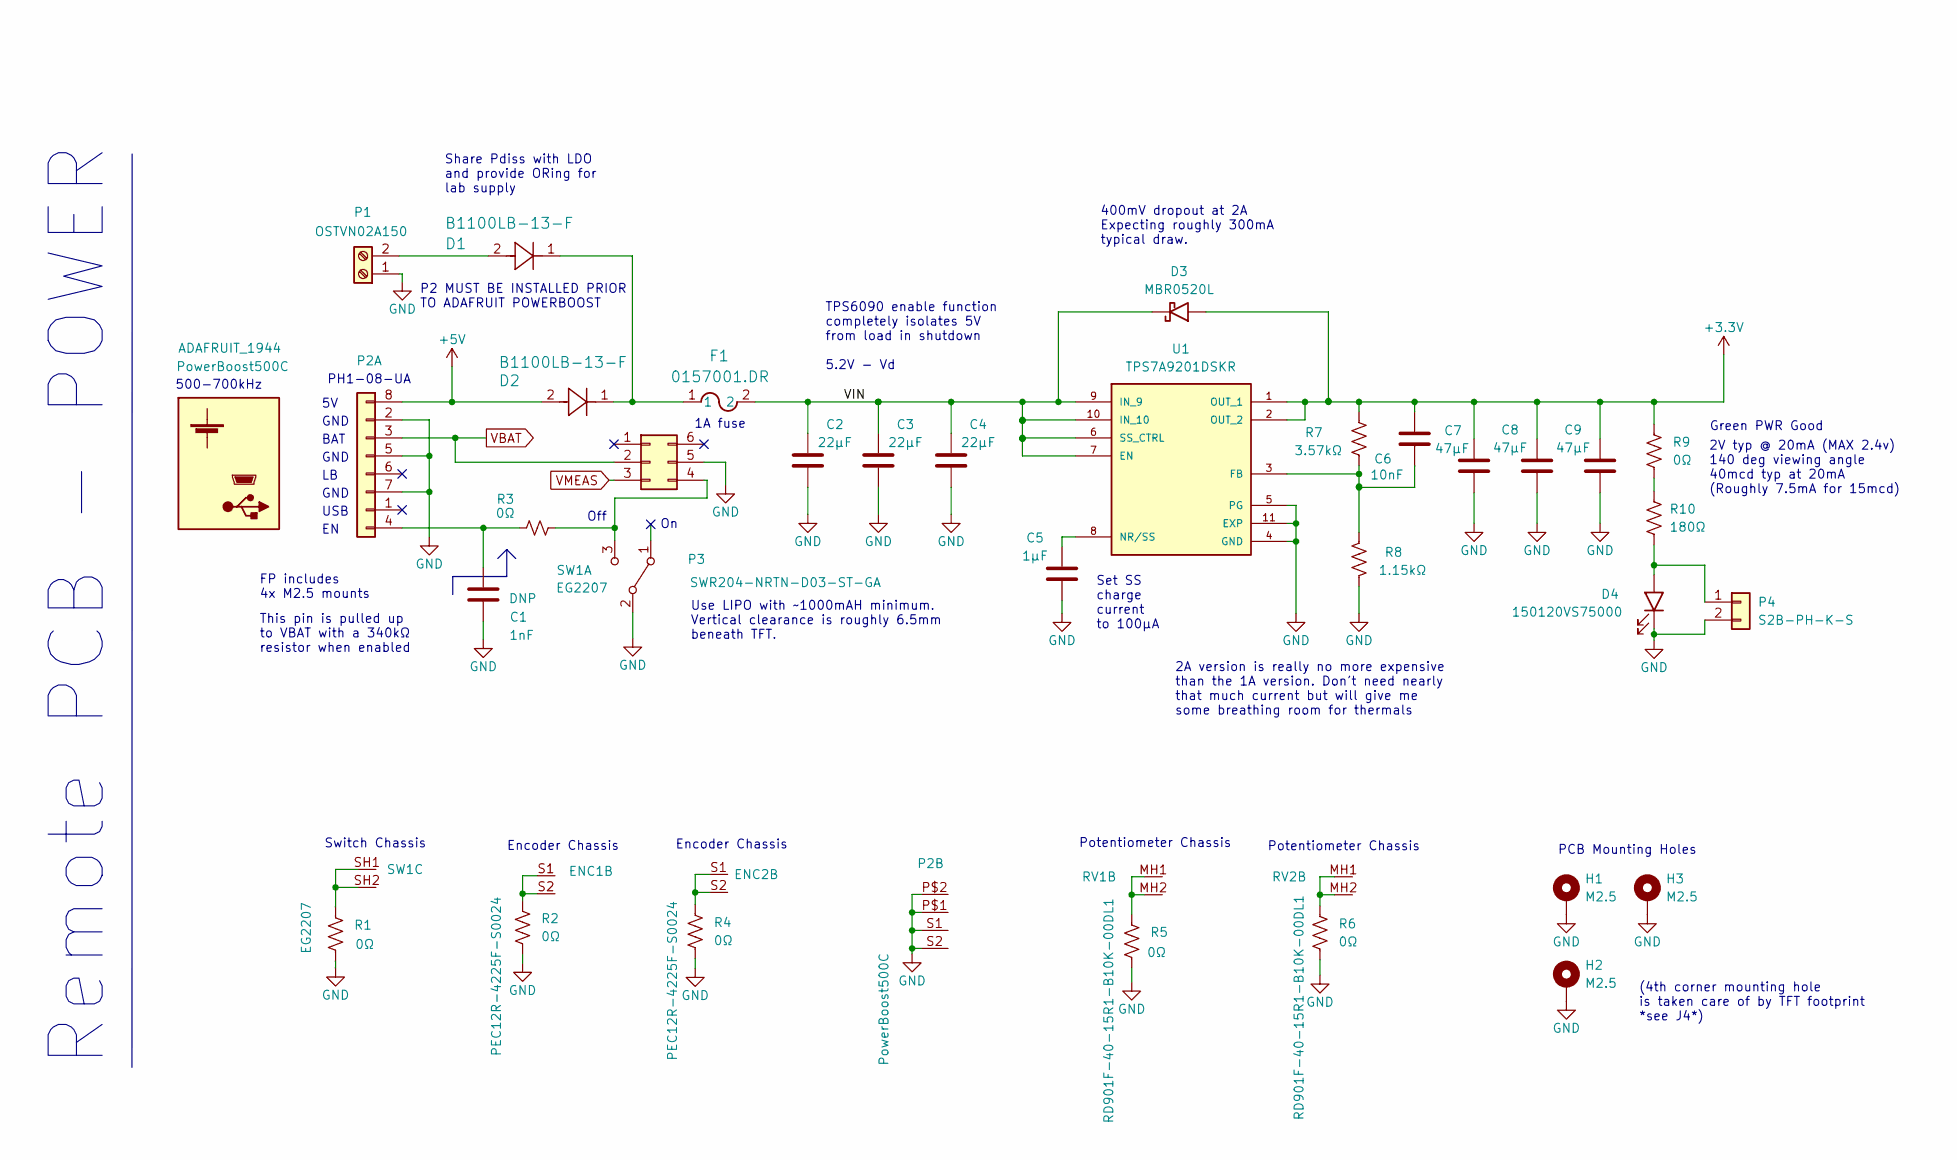
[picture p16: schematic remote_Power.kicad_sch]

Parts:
C1: 1nF; C_0603_1608Metric
C2, C3, C4: 22µF; C_0603_1608Metric
C5: 1µF; C_0603_1608Metric
C6: 10nF; C_0603_1608Metric
C7, C8, C9: 47µF; C_0603_1608Metric
D1, D2: B1100LB-13-F; D_SMB
D3: MBR0520L; D_SOD_123
D4: 150120VS75000; D_1206
ENC1, ENC2: PEC12R-4225F-S0024; XDCR_PEC12R-4215F-S0024
F1: 0157001.DR; FUSE_0157_SMD2
H1, H2, H3: M2.5; MountingHole_3.2mm_M3_DIN965_Pad_TopBottom
MODULE1: ADAFRUIT_1944
P1: OSTVN02A150; PinHeader_1x02_P2.54mm_Vertical
P2: PowerBoost500C; DB_POWERBOOST500C
P3: SWR204-NRTN-D03-ST-GA; sullinsSWR204
P4: S2B-PH-K-S; JST_PH_S2B-PH-K_1x02_P2.00mm_Horizontal
R1, R2, R3, R4, R5, R6, R9: 0Ω; R_0603_1608Metric
R7: 3.57kΩ; R_0603_1608Metric
R8: 1.15kΩ; R_0603_1608Metric
R10: 180Ω; R_0603_1608Metric
RV1, RV2: RD901F-40-15R1-B10K-00DL1; Potentiometer_Alps_RK09L_Single_Vertical
SW1: EG2207; SW_EG2207
U1: TPS7A9201DSKR; IC_SON-10_EP_2.5X2.5; PARTREV December 2016

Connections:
+5V: D2.2, P2.8
/Power/VIN: C2.2, C3.2, C4.2, D3.1 (K), F1.2, U1.6 (SS_CTRL), U1.7 (EN), U1.9 (IN_9), U1.10 (IN_10)
GND: C1.2, C2.1, C3.1, C4.1, C5.1, C7.1, C8.1, C9.1, D4.1 (K), H1.1, H2.1, H3.1, P1.1, P2.2, P2.5, P2.7, P2.P$1, P2.P$2, P2.S1 (M1), P2.S2 (M2), P3.5, P4.2, R1.2, R2.2, R4.2, R5.2, R6.2, R8.1, SW1.2, U1.4 (GND), U1.5 (PG), U1.11 (EXP), U1.12, U1.13, U1.14, U1.15; also elsewhere on the board
unnamed: C1.1, P2.4, R3.1
unnamed: C5.2, U1.8 (NR/SS)
unnamed: C6.1, R7.1, R8.2, U1.3 (FB)
unnamed: D1.1, D2.1, F1.1
unnamed: D1.2, P1.2
unnamed: D4.2 (A), P4.1, R10.2
unnamed: ENC1.S1 (MP1), ENC1.S2 (MP2), R2.1
unnamed: ENC2.S1 (MP1), ENC2.S2 (MP2), R4.1
unnamed: P3.4, R3.2, SW1.3
unnamed: R1.1, SW1.SH1, SW1.SH2
unnamed: R5.1, RV1.MH1 (MH2), RV1.MH2 (MH1)
unnamed: R6.1, RV2.MH1 (MH2), RV2.MH2 (MH1)
unnamed: R9.2, R10.1
VBAT: P2.3, P3.2; also elsewhere on the board
VMEAS: P3.3; also elsewhere on the board

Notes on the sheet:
PWR Good
TPS6090 enable function completely isolates 5V from load in shutdown 5.2V - Vd
Share Pdiss with LDO and provide ORing for lab supply
Switch Chassis
GND
500-700kHz
Remote PCB - POWER
This pin is pulled up to VBAT with a 340kΩ resistor when enabled
Set SS charge current to 100µA
BAT
PCB Mounting Holes
P2 MUST BE INSTALLED PRIOR TO ADAFRUIT POWERBOOST
2A version is really no more expensive than the 1A version. Don't need nearly that much current but will give me some breathing room for thermals
Off
USB
Encoder Chassis
(4th corner mounting hole is taken care of by TFT footprint *see J4*)
Green
PH1-08-UA
FP includes 4x M2.5 mounts
400mV dropout at 2A Expecting roughly 300mA typical draw.
Use LIPO with ~1000mAH minimum. Vertical clearance is roughly 6.5mm beneath TFT.
Potentiometer Chassis
2V typ @ 20mA (MAX 2.4v) 140 deg viewing angle 40mcd typ at 20mA (Roughly 7.5mA for 15mcd)
1A fuse

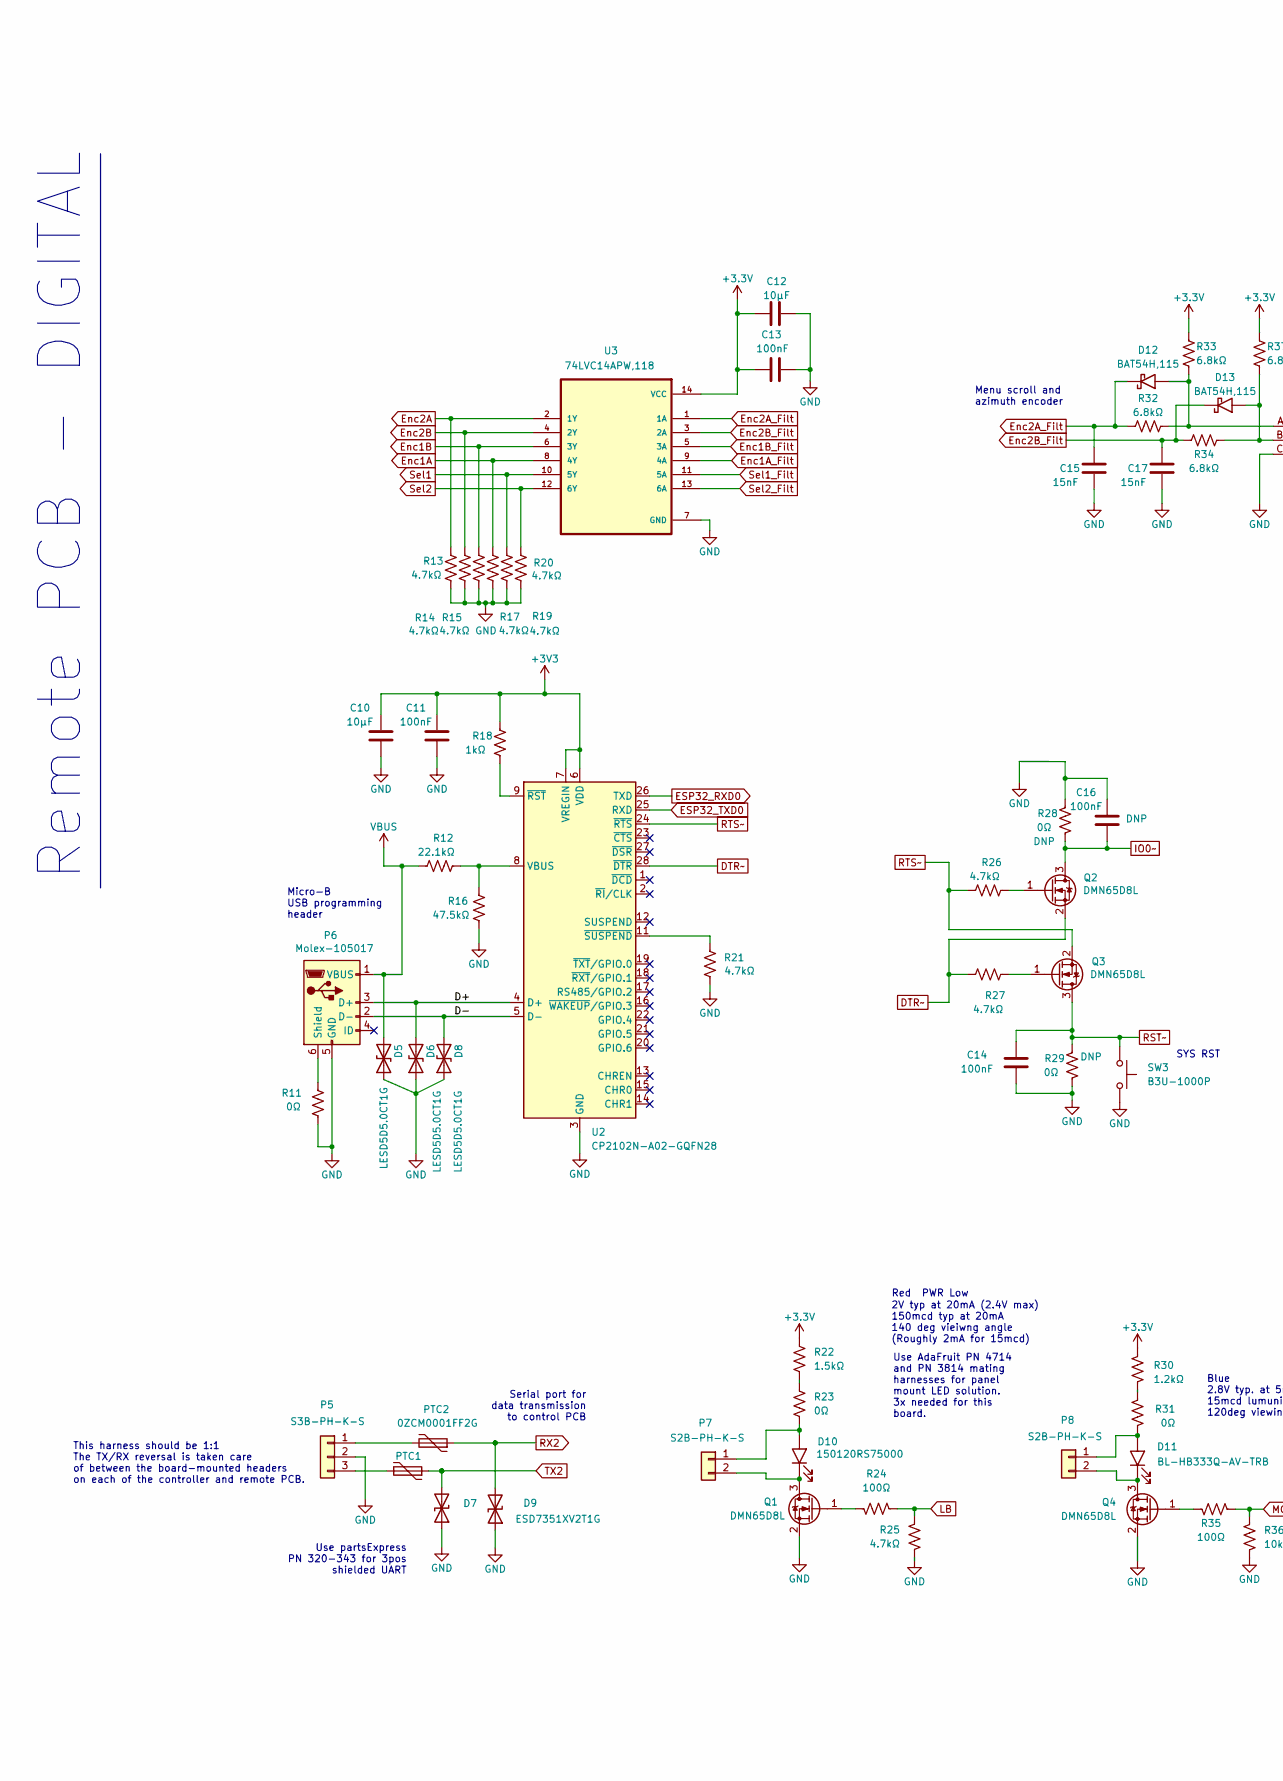
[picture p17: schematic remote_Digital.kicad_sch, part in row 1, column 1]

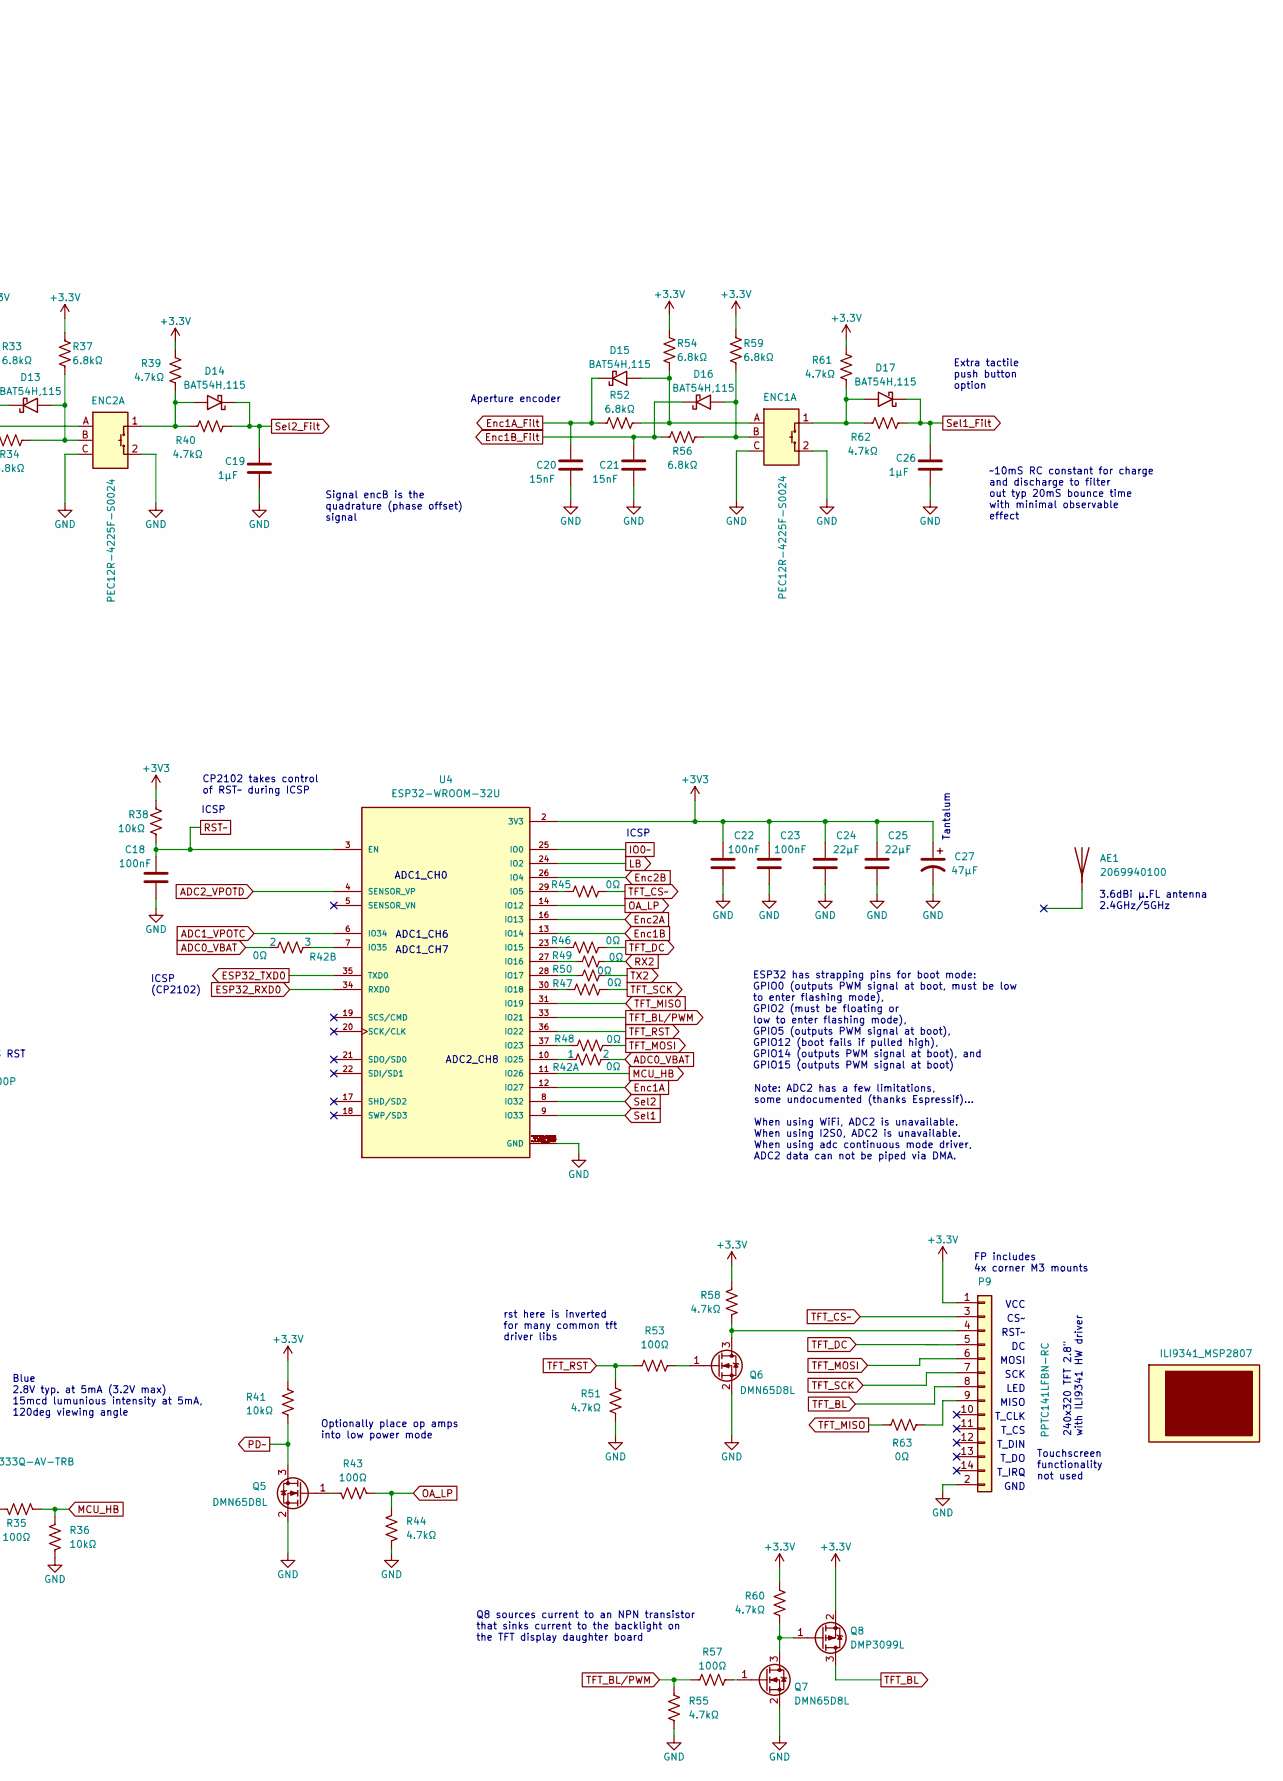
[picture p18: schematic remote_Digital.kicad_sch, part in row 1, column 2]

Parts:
AE1: 2069940100
C10, C12: 10µF; C_0603_1608Metric
C11, C13, C14, C16, C18, C22, C23: 100nF; C_0603_1608Metric
C15, C17, C20, C21: 15nF; C_0603_1608Metric
C19, C26: 1µF; C_0603_1608Metric
C24, C25: 22µF; C_0603_1608Metric
C27: 47µF; C_TANT_3216-18_Kemet-A
D5, D6, D8: LESD5D5.0CT1G; D_SOD_523
D7, D9: ESD7351XV2T1G; D_SOD_523
D10: 150120RS75000; D_1206
D11: BL-HB333Q-AV-TRB; D_1206
D12, D13, D14, D15, D16, D17: BAT54H,115; D_SOD_123F
ENC1, ENC2: PEC12R-4225F-S0024; XDCR_PEC12R-4215F-S0024
MODULE2: ILI9341_MSP2807
P5: S3B-PH-K-S; CON_1053131103
P6: Molex-105017; USB_Micro-B_Molex-105017-0001
P7, P8: S2B-PH-K-S; JST_PH_S2B-PH-K_1x02_P2.00mm_Horizontal
P9: PPTC141LFBN-RC; QD-TFT2803
PTC1, PTC2: 0ZCM0001FF2G; R_0603_1608Metric
Q1, Q2, Q3, Q4, Q5, Q6, Q7: DMN65D8L; T_SOT23
Q8: DMP3099L; T_SOT23
R11, R23, R28, R29, R31, R45, R46, R47, R48, R49, R50, R63: 0Ω; R_0603_1608Metric
R12: 22.1kΩ; R_0603_1608Metric
R13, R14, R15, R17, R19, R20, R21, R25, R26, R27, R39, R40, R44, R51, R55, R58, R60, R61, R62: 4.7kΩ; R_0603_1608Metric
R16: 47.5kΩ; R_0603_1608Metric
R18: 1kΩ; R_0603_1608Metric
R22: 1.5kΩ; R_0603_1608Metric
R24, R35, R43, R53, R57: 100Ω; R_0603_1608Metric
R30: 1.2kΩ; R_0603_1608Metric
R32, R33, R34, R37, R52, R54, R56, R59: 6.8kΩ; R_0603_1608Metric
R36, R38, R41: 10kΩ; R_0603_1608Metric
R42: 0Ω; R_0603_JUMPER
SW3: B3U-1000P; SW_SPST_B3U-1000P
U2: CP2102N-A02-GQFN28; IC_QFN-28_EP_5x5
U3: 74LVC14APW,118; IC_TSSOP-14_0.65P; MPN 74LVC14APW,118
U4: ESP32-WROOM-32U; IC_ESP32-WROOM32U; PARTREV 1.9

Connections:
/Digital/D+: D6.2 (A2), P6.3 (D+), U2.4 (D+)
/Digital/D-: D8.2 (A2), P6.2 (D-), U2.5 (D-)
ADC1_VPOTC: U4.6 (IO34); also elsewhere on the board
ADC2_VPOTD: U4.4 (SENSOR_VP); also elsewhere on the board
DTR~: Q2.2 (S), R27.1, U2.28 (~DTR)
ESP32_RXD0: U2.26 (TXD), U4.34 (RXD0)
ESP32_TXD0: U2.25 (RXD), U4.35 (TXD0)
Enc1A: R17.1, U3.8 (4Y), U4.12 (IO27)
Enc1A_Filt: C20.1, D15.1 (K), R52.1, U3.9 (4A)
Enc1B: R15.1, U3.6 (3Y), U4.13 (IO14)
Enc1B_Filt: C21.1, D16.1 (K), R56.1, U3.5 (3A)
Enc2A: R13.1, U3.2 (1Y), U4.16 (IO13)
Enc2A_Filt: C15.1, D12.1 (K), R32.1, U3.1 (1A)
Enc2B: R14.1, U3.4 (2Y), U4.26 (IO4)
Enc2B_Filt: C17.1, D13.1 (K), R34.1, U3.3 (2A)
GND: C10.1, C11.1, C12.1, C13.2, C14.1, C15.2, C16.2, C17.2, C18.1, C19.2, C20.2, C21.2, C22.1, C23.1, C24.1, C25.1, C26.2, C27.2, D5.1 (A1), D6.1 (A1), D7.1 (A1), D8.1 (A1), D9.1 (A1), ENC1.2, ENC1.C, ENC2.2 (S2), ENC2.C, P5.2, P6.5 (GND), P9.2, Q1.2 (S), Q4.2 (S), Q5.2 (S), Q6.2 (S), Q7.2 (S), R11.1, R13.2, R14.2, R15.2, R16.2, R17.2, R19.2, R20.2, R21.2, R25.2, R28.2, R29.1, R36.2, R44.2, R51.2, R55.2, SW3.2, U2.3 (GND), U2.29 (GND), U3.7 (GND), U4.1 (GND), U4.15 (GND), U4.38 (GND), U4.39_1 (GND), U4.39_2 (GND), U4.39_3 (GND), U4.39_4 (GND), U4.39_5 (GND), U4.39_6 (GND), U4.39_7 (GND), U4.39_8 (GND), U4.39_9 (GND), U4.39_10 (GND), U4.39_11 (GND), U4.39_12 (GND), U4.39_13 (GND), U4.39_14 (GND), U4.39_15 (GND), U4.39_16 (GND), U4.39_17 (GND), U4.39_18 (GND), U4.39_19 (GND), U4.39_20 (GND), U4.39_21 (GND); also elsewhere on the board
IO0~: C16.1, Q2.3 (D), R28.1, U4.25 (IO0)
LB: R24.1, R25.1, U4.24 (IO2)
MCU_HB: R35.1, R36.1, U4.11 (IO26)
unnamed: D10.1 (K), P7.2, Q1.3 (D)
unnamed: D10.2 (A), P7.1, R23.2
unnamed: D11.1 (K), P8.2, Q4.3 (D)
unnamed: D11.2 (A), P8.1, R31.2
unnamed: D12.2 (A), ENC2.A, R32.2, R33.2
unnamed: D13.2 (A), ENC2.B, R34.2, R37.2
unnamed: D14.2 (A), ENC2.1 (S1), R39.2, R40.1
unnamed: D15.2 (A), ENC1.A, R52.2, R54.2
unnamed: D16.2 (A), ENC1.B, R56.2, R59.2
unnamed: D17.2 (A), ENC1.1, R61.2, R62.1
unnamed: P5.1, PTC2.2
unnamed: P5.3, PTC1.2
unnamed: P6.6 (Shield), R11.2
unnamed: P9.4, Q6.3 (D), R58.2
unnamed: P9.9, R63.2
unnamed: Q1.1 (G), R24.2
unnamed: Q2.1 (G), R26.2
unnamed: Q3.1 (G), R27.2
unnamed: Q4.1 (G), R35.2
unnamed: Q5.1 (G), R43.2
unnamed: Q6.1 (G), R53.2
unnamed: Q7.1 (G), R57.2
unnamed: Q7.3 (D), Q8.1, R60.1
unnamed: R12.1, R16.1, U2.8 (VBUS)
unnamed: R18.2, U2.9 (~RST)
unnamed: R21.1, U2.11 (~SUSPEND)
unnamed: R22.2, R23.1
unnamed: R30.2, R31.1
unnamed: R42.1, U4.10 (IO25)
unnamed: R45.1, U4.29 (IO5)
unnamed: R46.1, U4.23 (IO15)
unnamed: R47.1, U4.30 (IO18)
unnamed: R48.1, U4.37 (IO23)
unnamed: R49.1, U4.27 (IO16)
unnamed: R50.1, U4.28 (IO17)
OA_LP: R43.1, R44.1, U4.14 (IO12)
PD~: Q5.3 (D), R41.2; also elsewhere on the board
RST~: C14.2, C18.2, Q3.3 (D), R29.2, R38.2, SW3.1, U4.3 (EN)
RTS~: Q3.2 (S), R26.1, U2.24 (~RTS)
RX2: D9.2 (A2), PTC2.1, R49.2
Sel1: R19.1, U3.10 (5Y), U4.9 (IO33)
Sel1_Filt: C26.1, D17.1 (K), R62.2, U3.11 (5A)
Sel2: R20.1, U3.12 (6Y), U4.8 (IO32)
Sel2_Filt: C19.1, D14.1 (K), R40.2, U3.13 (6A)
TFT_BL: P9.8, Q8.3
TFT_BL/PWM: R55.1, R57.1, U4.33 (IO21)
TFT_CS~: P9.3, R45.2
TFT_DC: P9.5, R46.2
TFT_MISO: R63.1, U4.31 (IO19)
TFT_MOSI: P9.6, R48.2
TFT_RST: R51.1, R53.1, U4.36 (IO22)
TFT_SCK: P9.7, R47.2
TX2: D7.2 (A2), PTC1.1, R50.2
VBUS: D5.2 (A2), P6.1 (VBUS), R12.2

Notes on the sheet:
T_CLK
CP2102 takes control of RST~ during ICSP
Blue 2.8V typ. at 5mA (3.2V max) 15mcd lumunious intensity at 5mA, 120deg viewing angle
VCC
Signal encB is the quadrature (phase offset) signal
Use AdaFruit PN 4714 and PN 3814 mating harnesses for panel mount LED solution. 3x needed for this board.
3.6dBi µ.FL antenna 2.4GHz/5GHz
MOSI
Q8 sources current to an NPN transistor that sinks current to the backlight on the TFT display daughter board
Remote PCB - DIGITAL
Note: ADC2 has a few limitations, some undocumented (thanks Espressif)... When using WiFi, ADC2 is unavailable. When using I2S0, ADC2 is unavailable. When using adc continuous mode driver, ADC2 data can not be piped via DMA.
CS~
T_IRQ
Micro-B USB programming header
ICSP
Use partsExpress PN 320-343 for 3pos shielded UART
T_DIN
Red
ESP32 has strapping pins for boot mode: GPIO0 (outputs PWM signal at boot, must be low to enter flashing mode), GPIO2 (must be floating or low to enter flashing mode), GPIO5 (outputs PWM signal at boot), GPIO12 (boot fails if pulled high), GPIO14 (outputs PWM signal at boot), and GPIO15 (outputs PW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
Aperture encoder
~10mS RC constant for charge and discharge to filter out typ 20mS bounce time with minimal observable effect
ADC1_CH6
SCK
SYS RST
ADC1_CH7
Extra tactile push button option
Touchscreen functionality not used
RST~
ADC1_CH0
Serial port for data transmission to control PCB
Optionally place op amps into low power mode
FP includes 4x corner M3 mounts
Tantalum
MISO
240x320 TFT 2.8" with ILI9341 HW driver
T_DO
ADC2_CH8
rst here is inverted for many common tft driver libs
Menu scroll and azimuth encoder
This harness should be 1:1 The TX/RX reversal is taken care of between the board-mounted headers on each of the controller and remote PCB.

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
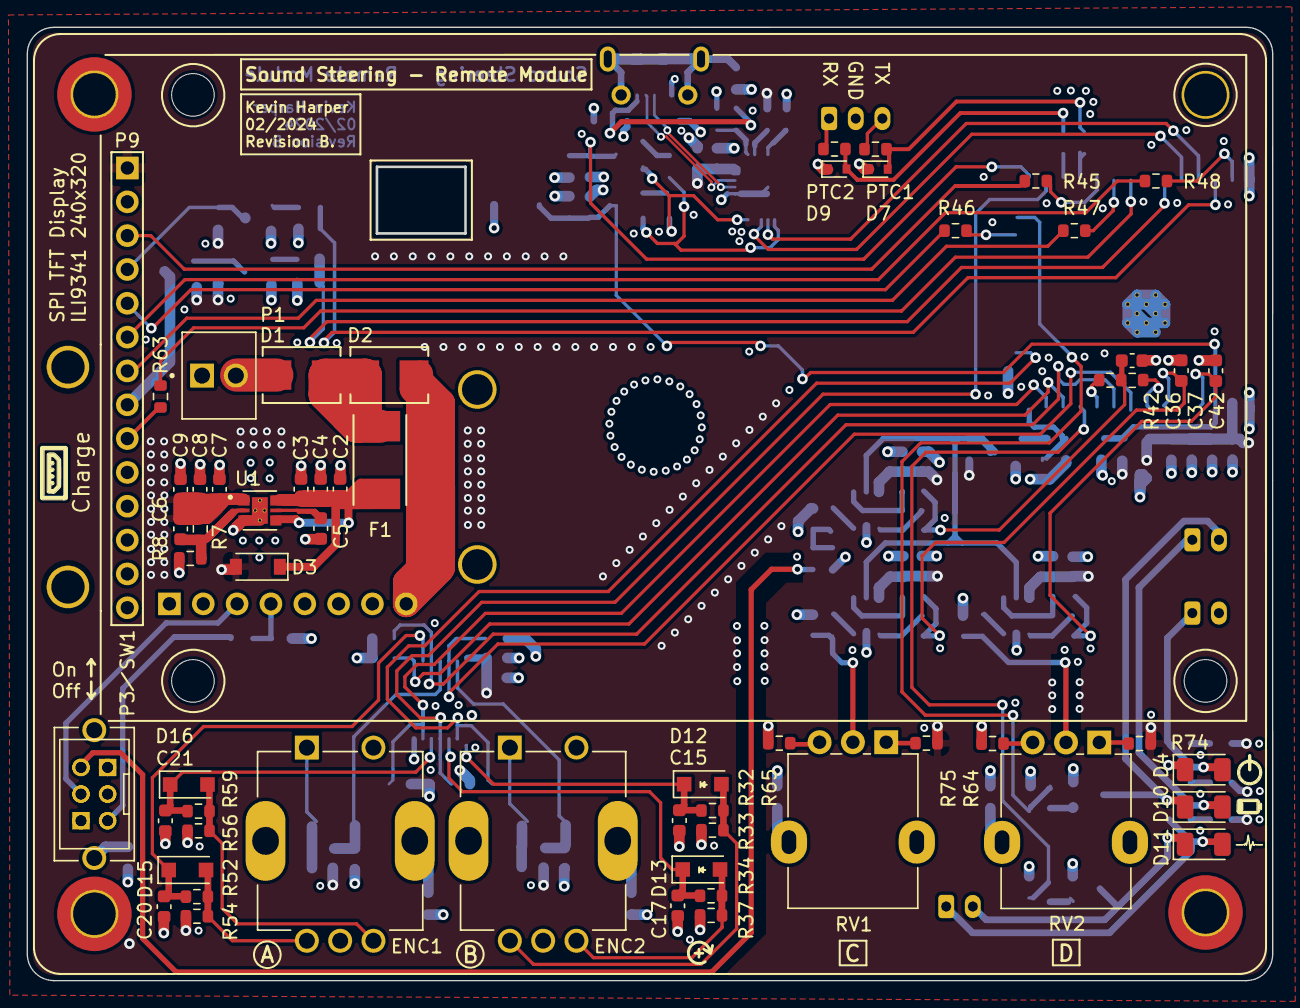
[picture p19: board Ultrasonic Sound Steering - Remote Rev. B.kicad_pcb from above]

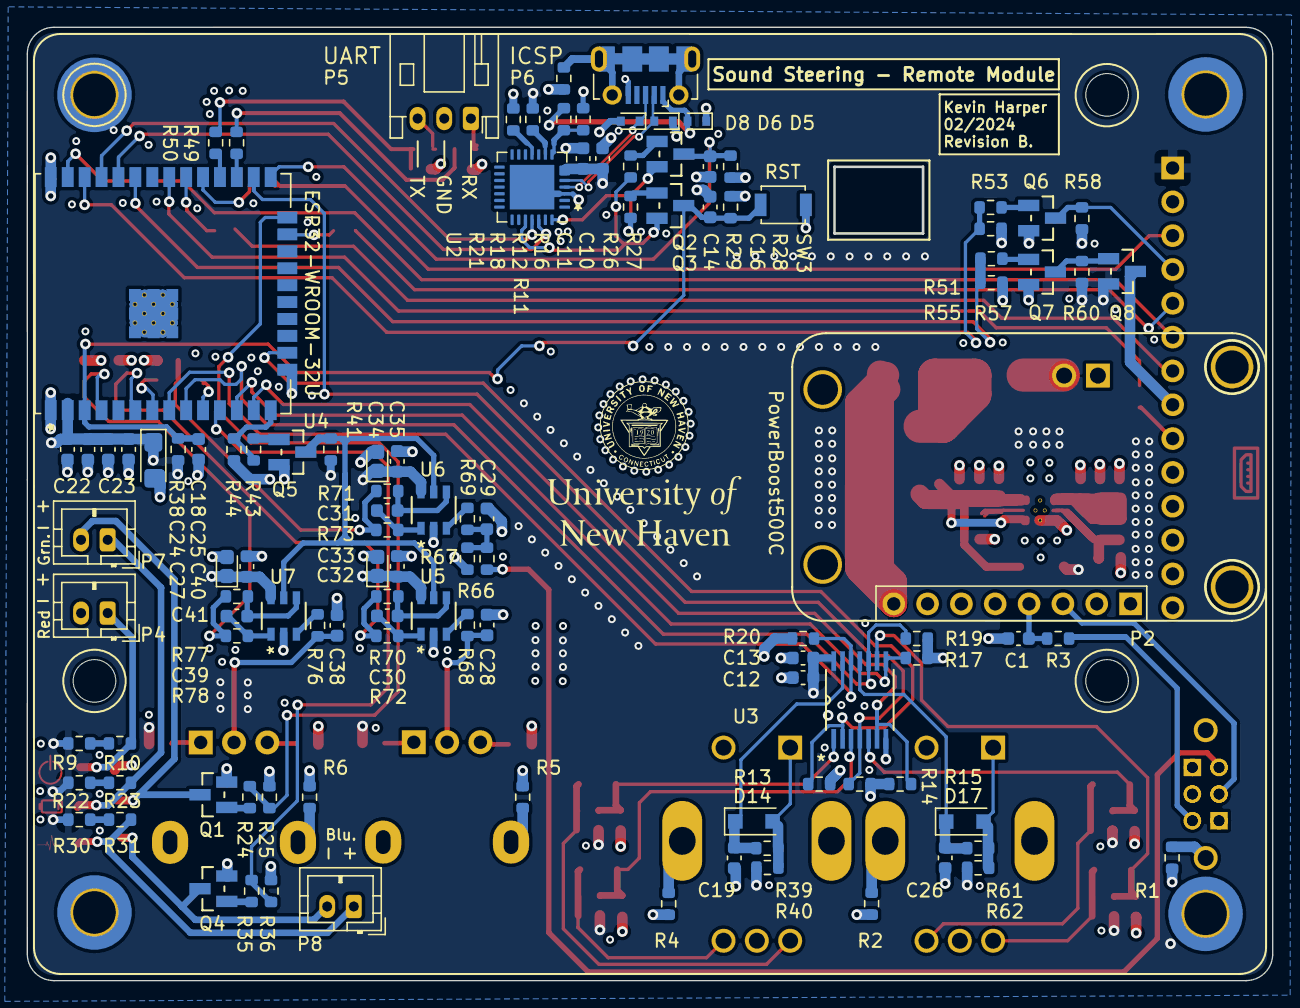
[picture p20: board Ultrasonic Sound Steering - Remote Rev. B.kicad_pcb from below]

Board: 4 copper layers, 93.5 x 71.6 mm, 173 parts (111 on the bottom side), 109 nets.

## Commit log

2024-06-07 PDF prints of all schematic files
    KiCAD 6
2024-06-07 Various info pertaining to the FPGA design
    [TE0725 - AXI Register Map.xlsx, TE0725 - Application Pinout.xlsx]
